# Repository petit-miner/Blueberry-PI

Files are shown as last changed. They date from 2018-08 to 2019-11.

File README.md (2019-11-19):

Blueberry PI

I have designed this PCB, because the sheer power of this SoC, at very low power consumption, combined with its display capabilities, it offers options that makers have never seen before.<br> 
<br>
There are two versions available: the 2 layer and 4 layer version.<br> 
Have a look at the subfolder for the 2 and 4 layer version to check out the specific features.<br>
<br>
<br>
The Blueberry PI:<br>
• SoC Allwinner V3s:<br>
	- ARM Cortex-A7 @ 1.2GHz<br>
	- 64 Megabyte of RAM<br>
•	10 / 100M Ethernet <br>
•	Wifi and Bluetooth (RTL8723BS)  <br>
•	1 USB Host Port / 1 micro USB port <br> 
•	MIPI CSI interface<br>
•	pinheader for an OV2640 and an OV7670 parallel camera<br>
•	parallel RGB interface, compatible with 40pin parallel RGB displays<br>
•	audio jack (3,5mm)<br>
•	onboard microphone<br>
•	a 26pin Raspberry PI compatible header<br>
•	SPI Flash <br>
•	SD card slot<br>

The Blueberry PI can boot from an SD card or SPI Flash. <br>
I'm currently <b> not </B> available for custom projects. <br>
If you have any questions email me at info.blueberrypi@gmail.com <br>

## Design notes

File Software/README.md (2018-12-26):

Software

The mainline linux kernel (4.21) has support for:
- basic SOC features
- Ethernet
- USB 
- parallel CSI 
- RGB and TCON 
- UART
- I²C
- SPI
- SDIO
- Audio
- LRADC0
- RTC
- Watchdog

Whats not implemented:
- CPU frequency scaling
- MIPI CSI 
- Video Engine (encoding / decoding video)

 Have a look at the documentation to find out how to build your own mainline kernel and rootfs.

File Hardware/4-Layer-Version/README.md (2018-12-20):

Hardware

This is the 4 Layer version of the Blueberry PI. It has a richer featureset than the 2 Layer PCB.<br>
Keep in mind that this PCB isn' tested yet, I will keep you updated.<br>
It has the following features:<br>
<br>
• SoC Allwinner V3s:<br>
• ARM Cortex-A7 @ 1.2GHz<br>
• 64 Megabyte of RAM<br>
• Ethernet Jack<br>
• Wifi and Bluetooth (RTL8723BS)<br>
• 1 USB Host Port / 1 micro USB port<br>
• MIPI CSI interface, pin compatible with the Raspberry Pi camera<br>
• pinheader for an OV2640 and an OV7670 parallel camera<br>
• parallel RGB interface, compatible with 40pin parallel RGB displays<br>
• VGA Output<br>
• HDMI Input with the ADV7611 1080p @ 30 fps<br>
• Audio jack (3,5mm)<br>
• onboard microphone<br>
• a 26pin Raspberry PI compatible header<br>
• SPI Flash<br>
• SD card slot <br>
<br>

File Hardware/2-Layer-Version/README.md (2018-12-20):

Hardware

This is the 2 Layer version of the Blueberry PI. It is a more compact version as the 4 layer PCB.<br>
It has the following features:<br>
<br>
• SoC Allwinner V3s:<br>
• ARM Cortex-A7 @ 1.2GHz<br>
• 64 Megabyte of RAM<br>
• Ethernet Jack<br>
• Wifi and Bluetooth (RTL8723BS)<br>
• 1 USB Host Port / 1 micro USB port<br>
• MIPI CSI interface, pin compatible with the Raspberry Pi camera<br>
• pinheader for an OV2640 and an OV7670 parallel camera<br>
• parallel RGB interface, compatible with 40pin parallel RGB displays<br>
• Audio jack (3,5mm)<br>
• onboard microphone<br>
• four costumizeable buttons and one reset buttons<br>
• a 26pin Raspberry PI compatible header<br>
• SPI Flash<br>
• SD card slot <br>

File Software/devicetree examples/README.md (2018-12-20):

Devicetree examples

As you can see there are 3 .dts files and one dtsi file.

The sun8i-v3s.dtsi defines all of the SoC Interfaces.

The sun8i-blueberrypi.dts shows an example for enabling the framebuffer.

The sun8i-blueberrypi-csi-ov2640.dts shows an example for the OV2640 parallel camera.

The sun8i-blueberrypi-csi-ov7670.dts shows an example for the OV7670 parallel camera.

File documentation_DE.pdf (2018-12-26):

## Inhaltsverzeichnis

S e i t e | 1

S e i t e | 2

## Buildroot

Für Buildroot werden folgende Pakte benötigt:

which sed make binutils build-essentials gcc g++ bash patch gzip bzip2 perl tar cpio python unzip rsync file bc wget ncurses5

Als erstes muss Buildroot heruntergeladen werden:

https://buildroot.org/downloads/

Wählt dazu den aktuellsten Tarball aus. Entpackt den Tarball in euer Workspace und betretet das neue Verzeichnis buildroot. Anschließend muss das Unterverzeichnis configs betreten werden.

In diesem Unterverzeichnis ladet ihr die vorgefertigte config Datei für den Blueberry PI herunter:

wget https://github.com/petit-miner/Blueberry-PI/raw/master/Software/blueberrypi_defconfig

Verlasst danach das Unterverzeichnis configs und wechselt ins Hauptverzeichnis von Buildroot, nun wird die config Datei angewendet:

make blueberrypi_defconfig

Möchte man nun Buildroot weiter konfigurieren, so muss dieser Befehl verwendet werden:

make menuconfig

Der Buildprozess lässt sich mit

make

starten. Dabei ist zu beachten, dass der Parameter -j nicht verwendet werden darf, da Buildroot kein paralleles Arbeiten unterstützt!

Nach erfolgreichem erstellen des Buildroots ist der Tarball unter: output/images/rootfs.tar

zu finden.

S e i t e | 3

## Imagepacker

Im Imagepacker befindet sich bereits eine kompilierte Version von u-boot und des Linux Kernels (4.21.rc-1). Somit kann, wenn gewünscht, der Buildprozess von u-boot und dem Linux Kernel übersprungen werden. Das Buildroot muss aufgrund seiner Größe allerdings noch selbst erstellt werden.

Möchte man ein LCD verwenden müssen diese Dateien in das /boot Verzeichnis kopiert werden:

boot-lcd.scr

sun8i-v3s-blueberrypi.dtb

Möchte man den VGA Ausgang benutzen müssen folgende Dateien in das /boot Verzeichnis kopiert werden:

boot-vga.scr

sun8i-v3s-blueberrypi.dtb

Möchte man keine Videoausgabe oder möchte eine parallele Kamera anschließen sind folgende Dateien zu kopieren:

boot.scr

sun8i-v3s-blueberrypi-csi-ov7670.dtb oder sun8i-v3s-blueberrypi-csi-ov2640.dtb

(Anschließend muss die Devicetree Datei noch in sun8i-v3s-blueberrypi.dtb umbenannt werden!)

Nachdem die korrekten Bootdateien kopiert worden sind, muss das zuvor erstellte tarball Buildroot in den Ordner rootfs entpackt werden. Wichtig ist dabei, dass dieses als Root geschieht, da sonst die Dateirechte verloren gehen.

mkdir rootfs

sudo tar xvf rootfs/rootfs.tar

rm rootfs/rootfs.tar

Als letzter Schritt wird nun das flashbare Image erstellt, dies geschieht so:

sudo chmod +x imagepacker.sh

sudo ./imagepacker.sh boot/ rootfs/

Nach erfolgreichem Erstellen des Images ist dieses als .dd Datei zu finden.

S e i t e | 4

## u-boot

Als erstes muss der Sourcecode für u-boot von Github geklont werden:

git clone https://github.com/petit-miner/u-boot.git -b v3s-current

Betrete anschließend das neue Verzeichnis u-boot und wende die Konfigurationsdatei an:

make ARCH=arm CROSS_COMPILE=arm-linux-gnueabihf- BlueberryPI-vga_defconfig

Möchte man nun u-boot weiter konfigurieren, so muss dieser Befehl verwendet werden:

make ARCH=arm CROSS_COMPILE=arm-linux-gnueabihf- menuconfig

Der Buildprozess lässt sich mit

make

starten.

Nach erfolgreichem Erstellen von u-boot ist dieses als u-boot-sunxi-with-spl.bin zu finden.

## Linux Kernel

Als erstes muss der Sourcecode für den Linux Kernel von Github geklont werden:

git clone https://github.com/torvalds/linux.git

Betrete anschließend das neue Verzeichnis linux und wende folgende Konfigurationsdatei an:

make ARCH=arm CROSS_COMPILE=arm-linux-gnueabihf- sunxi_defconfig

Zu beachten ist, dass es sich hierbei um eine minimal Konfiguration handelt und somit viele Treiber für z.B. USB Geräte fehlen. Zudem fehlt der DVP Kamera Treiber, dieser ist unter device driver -> Multimedia -> Platform zu finden. Diese können durch menuconfig ausgewählt werden.

make ARCH=arm CROSS_COMPILE=arm-linux-gnueabihf- menuconfig

Der Buildprozess lässt sich mit

make ARCH=arm CROSS_COMPILE=arm-linux-gnueabihf-

starten.

Nach erfolgreichem Erstellen vom Linux Kernel ist dieser als arch/arm/boot/zImage zu finden.

S e i t e | 5

## USB OTG (Universal Serial Bus, On the Go)

Der Allwinner V3s verfügt über einen USB OTG Port. Das USB Interface ist nicht multiplexbar.

Port | Pin
USB-DM | 110
USB-DP | 111

Im Linux Kernel ist der Treiber für das USB Interface als sun4i-usb-phy und sun4i-a10-musb zu finden.

### Konfiguration im Devicetree

Bei der Verwendung der Standard Devicetree Datei sun8i-v3s.dtsi ist im folgenden Beispiel erklärt wie der USB Controller aktiviert wird: Die vollständige Devicetreedatei kann auf Github heruntergeladen werden. Auszug aus der sun8i-v3s.dtsi:

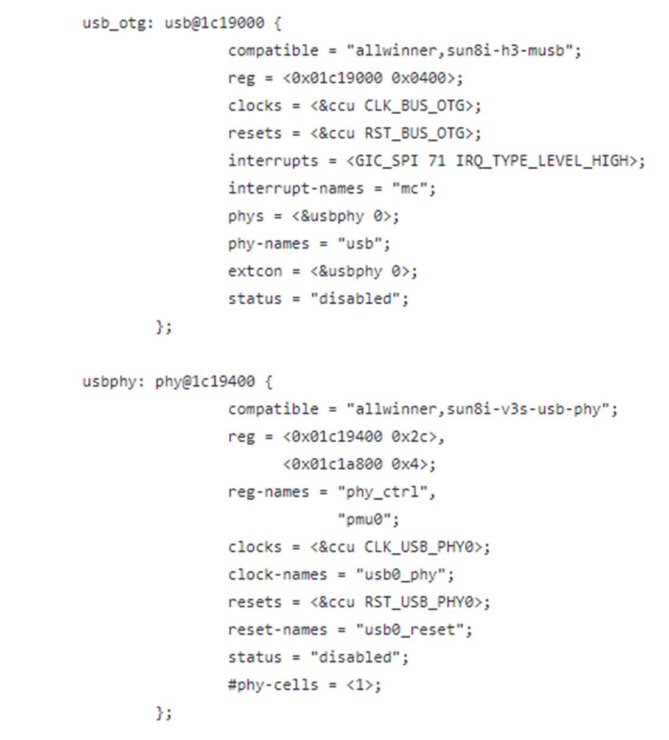
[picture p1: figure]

S e i t e | 6

Dafür muss die Boardfile sun8i-v3s-blueberrypi.dts bearbeitet werden:

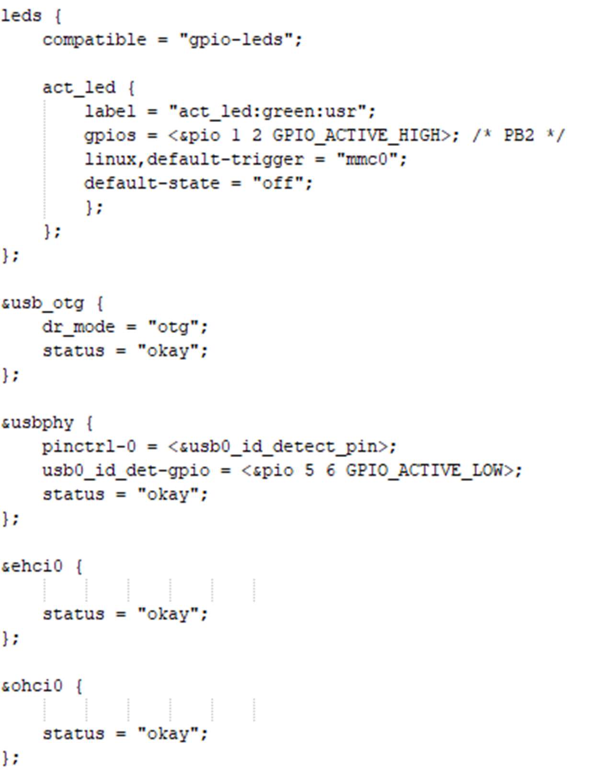
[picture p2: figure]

Der EHCI und OHCI Controller werden benötigt um USB 1.0 und USB 2.0 Geräte zu unterstützen. Werden die beiden Controller nicht im Devicetree aktiviert, entsteht kein Host Verhalten des V3s SoC. Momentan ist es nicht möglich USB 3.0 Geräte an den V3s anzuschließen, da dies eine Kernel Panic hervorruft.

### USB Device

Der V3s SoC verfügt über einen USB OTG Port, d.h. dass er als USB Device oder Host konfiguriert werden kann. Beim Blueberry PI befindet sich der USB_ID Pin an PF6. Dank der Treiberunterstützung im Linux Kernel kann der V3s als virtuelle USB zu Ethernet Karte und auch als USB zu UART Konverter fungieren. Dank des offenen USB Stacks lassen sich auch eigene USB Devices programmieren.

S e i t e | 7

### FEL-Mode

Über USB ist es möglich ein angeschlossenes SPI Flash zu beschreiben. Dazu muss die SD Karte aus dem Halter entfernt werden. Die weiteren Schritte zum Beschreiben sind auf Sunxi unter FEL/USBBoot zu finden.

## Ethernet

Der Allwinner V3s verfügt über einen Ethernet Port. Das Ethernet Interface ist nicht multiplexbar.

Port | Pin
EPHY_RXN | 89
EPHY_RXP | 90
EPHY_TXN | 91
EPHY_TXP | 91
EPHY_LINK_LED | 77
EPHY_SPD_LED | 78

Im Linux Kernel ist der Treiber für das Ethernet Interface als dwmac-sun8i zu finden.

### Konfiguration im Devicetree

Bei der Verwendung der Standard Devicetree Datei sun8i-v3s.dtsi ist im folgenden Beispiel erklärt wie das Ethernet Interface aktiviert wird. Dafür muss die Boardfile sun8i-v3s-blueberrypi.dts bearbeitet werden:

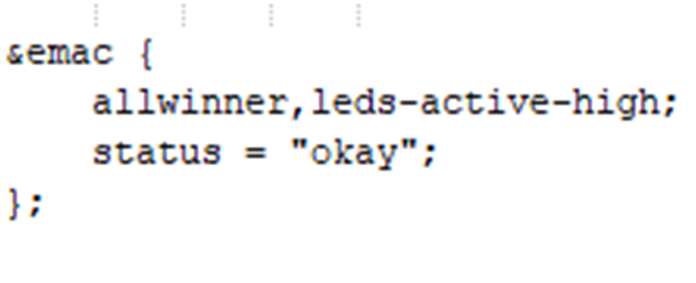
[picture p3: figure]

S e i t e | 8

### Einstellen einer festen MAC Adresse

Bei jedem Start / Reboot erhält der Ethernet PHY eine neue MAC Adresse vom Treiber, um dies zu unterbinden muss folgendes in die /etc/network/interfaces eingetragen werden:

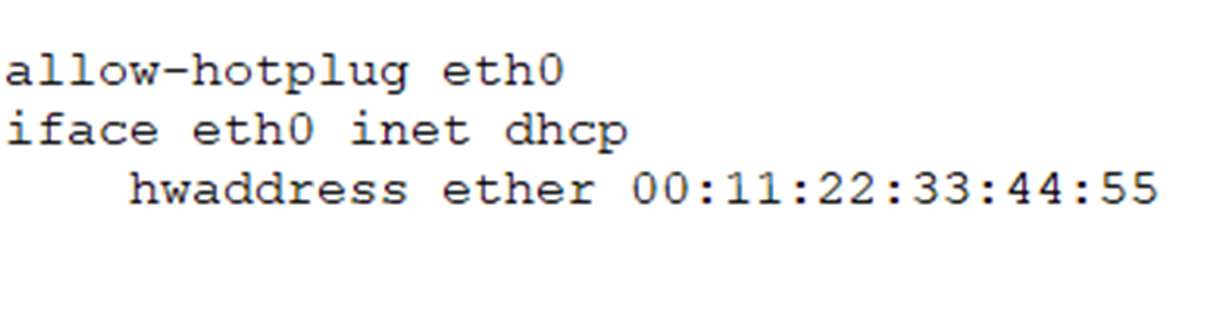
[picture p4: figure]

## Parallel RGB LCD interface

Der Allwinner V3s verfügt über eine parallele RGB LCD Schnittstelle, welche direkt LCDs ansteuern kann. Es können so gut wie alle 40 Pin parallelen RGB LCDs verwendet werden, zum Beispiel:

AT050TN33 (480x320)

HW800480F-3E-0B-10 (800x480)

Das parallele RGB interface ist nicht multiplexbar und besitzt folgendes Pinmapping:

Port | Pin
CSI_PCLK | PE0
CSI_MCLK | PE1
CSI_HSYNC | PE2
CSI_VSYNC | PE3
LCD_D2 | PE4
LCD_D3 | PE5
LCD_D4 | PE6
LCD_D5 | PE7
LCD_D6 | PE8
LCD_D7 | PE9
LCD_D10 | PE10
LCD_D11 | PE11
LCD_D12 | PE12
LCD_D13 | PE13
LCD_D14 | PE14
LCD_D15 | PE15
LCD_D18 | PE16
LCD_D19 | PE17
LCD_D20 | PE18
LCD_D21 | PE19
LCD_D22 | PE23
LCD_D23 | PE24

S e i t e | 9

### Konfiguration in u-boot:

Das Displaytiming wird bereits in u-boot konfiguriert um schon beim Booten eine Displayausgabe zu erhalten. Beim Starten des Linux Kernels übergibt u-boot jegliche Informationen über das Displaytiming sowie die Speicheradresse des zuvor initialisierten Framebuffers an den Linux Kernel. Somit ist es theoretisch nicht nötig die Displayhardware im Devicetree zu konfigurieren.

Es muss lediglich ein Framebuffer für u-boot angegeben werden, Auszug aus der

sun8i-v3s-blueberrypi.dts:

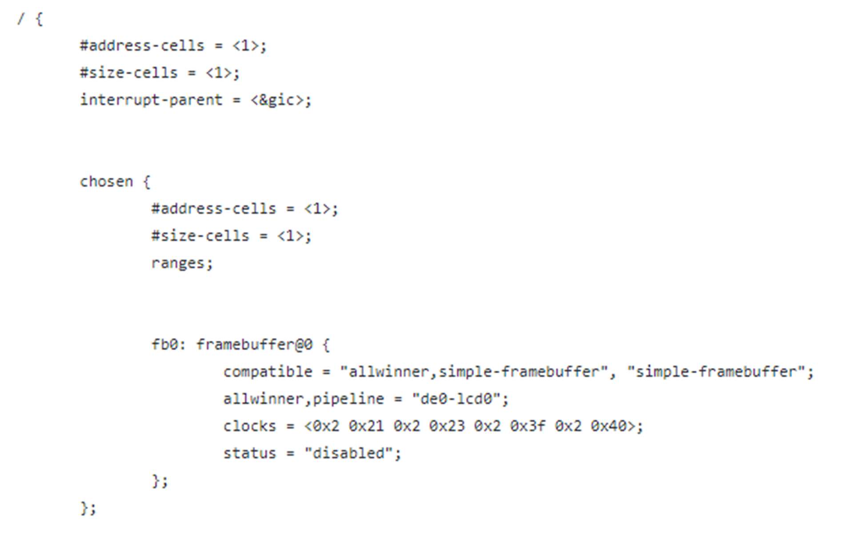
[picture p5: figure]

Momentan wird der simple Framebuffer lediglich in meinem u-boot Repository unterstützt.

Um u-boot mit Unterstützung des parallelen RGB Interfaces zu bauen, siehe u-boot. Dort sind auch die benötigten Displaytimings für die beiden oben genannten Displays angegeben sowie für den RGB zu VGA Konverter.

S e i t e | 10

## Parallel CSI

Der Allwinner V3s verfügt über einen parallelen CSI Port. Das Interface ist nicht multiplexbar.

Port | PIN | OV7670 | OV2640 | ADV7611
CSI_PCLK | PE0 | PLCK | PCLK | LLC
CSI_MCLK | PE1 | XCLK | XCLK | X
CSI_HSYNC | PE2 | HREF | HREF | X**
CSI_VSYNC | PE3 | VSYNC | VSYNC | X**
CSI_D0 | PE4 | X | X | P8
CSI_D1 | PE5 | X | X | P9
CSI_D2 | PE6 | X | D0 | P10
CSI_D3 | PE7 | X | D1 | P11
CSI_D4 | PE8 | D0 | D2 | P12
CSI_D5 | PE9 | D1 | D3 | P13
CSI_D6 | PE10 | D2 | D4 | P14
CSI_D7 | PE11 | D3 | D5 | P15
CSI_D8 | PE12 | D4 | D6 | P0
CSI_D9 | PE13 | D5 | D7 | P1
CSI_D10 | PE14 | D6 | D8 | P2
CSI_D11 | PE15 | D7 | D9 | P3
CSI_D12 | PE16 | X | X | P4
CSI_D13 | PE17 | X | X | P5
CSI_D14 | PE18 | X | X | P6
CSI_D15 | PE19 | X | X | P7
CSI_SCK / I2C1* | PE21 | SIOC | SIOC | SCL
CSI_SDA / I2C1* | PE22 | SIOD | SIOD | SDA

*zu beachten ist, dass lediglich I2C1 bzw. CSI_I2C für die Ansteuerung der Kamera verwendet werden kann.

** HSync und VSync Signale werden nicht benötigt, da BT.656 mit embedded Sync verwendet wird.

### Konfiguration im Devicetree

Bei der Verwendung der Standard Devicetree Datei sun8i-v3s.dtsi ist im folgenden Beispiel erklärt wie der parallele CSI Port aktiviert wird: Die vollständige Devicetreedatei kann auf Github heruntergeladen werden. Auszug aus der sun8i-v3s.dtsi:

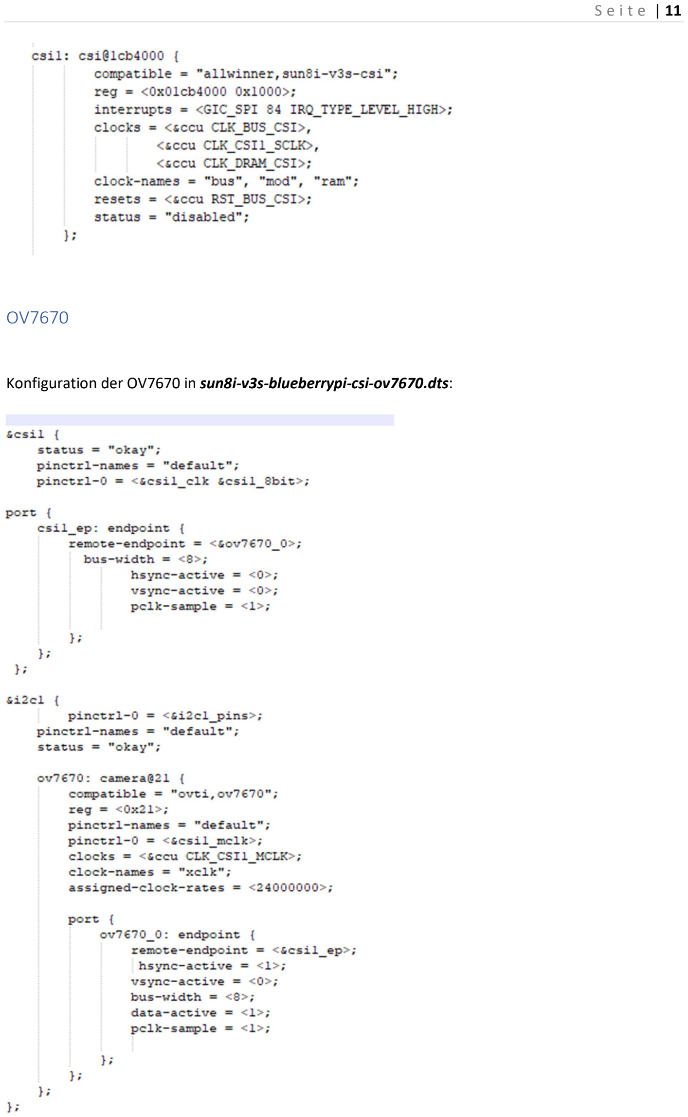
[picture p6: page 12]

S e i t e | 11

OV7670

Konfiguration der OV7670 in sun8i-v3s-blueberrypi-csi-ov7670.dts:

S e i t e | 12

Unter &csi wird das Interface aktiviert und die dazu gehörigen Pins über &csi1_clk und &csi1_8bit dem Interface zugewiesen. Dies geschieht im &pio (Pincontroller):

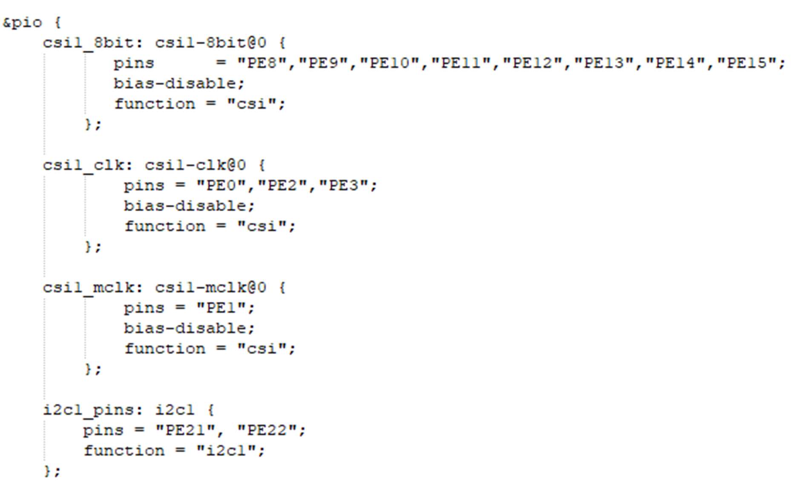
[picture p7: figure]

Anschließend wird im endpoint die verwendete Kamera näher definiert, wie z.B. die Hsync, Vsync und die PCLK Eigenschaften.

Unter &i2c1 werden die benutzen Pins zugewiesen und das I2C1 Interface aktiviert, innerhalb des &i2c1 wird die Kamera konfiguriert. Mit reg = <0x21>; wird die I2C Adresse der Kamera angegeben.

Danach wird die MCLK, die den Arbeitstakt für die Kamera bereitstellt, konfiguriert. Hierzu wird der verwendete Pin angegeben, siehe &pio, sowie die Frequenz in Hz.

Im endpoint von &i2c1 werden wieder die Eigenschaften von Hsync, Vsync und der PCLK definiert.

Zu beachten ist, dass die beiden Endpoints unter &csi und &i2c1 aufeinander verweisen, siehe remote-endpoint = <>;

S e i t e | 13

OV2640

Konfiguration der OV2640 in sun8i-v3s-blueberrypi-csi-ov2640.dts:

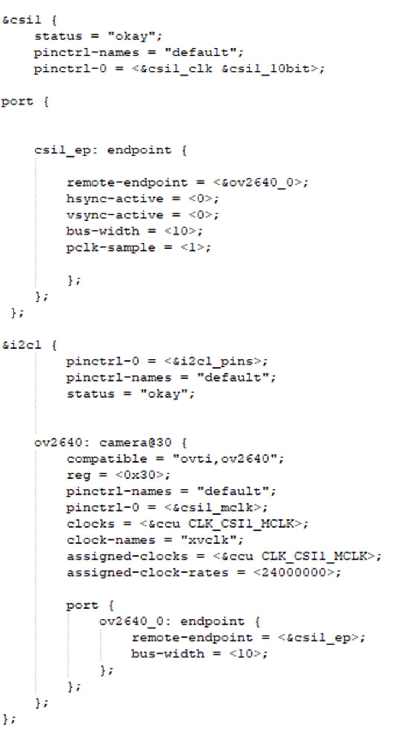
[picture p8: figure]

S e i t e | 14

Unter &csi wird das Interface aktiviert und die dazu gehörigen Pins über &csi1_clk und &csi1_10bit dem Interface zugewiesen. Dies geschieht im &pio (Pincontroller):

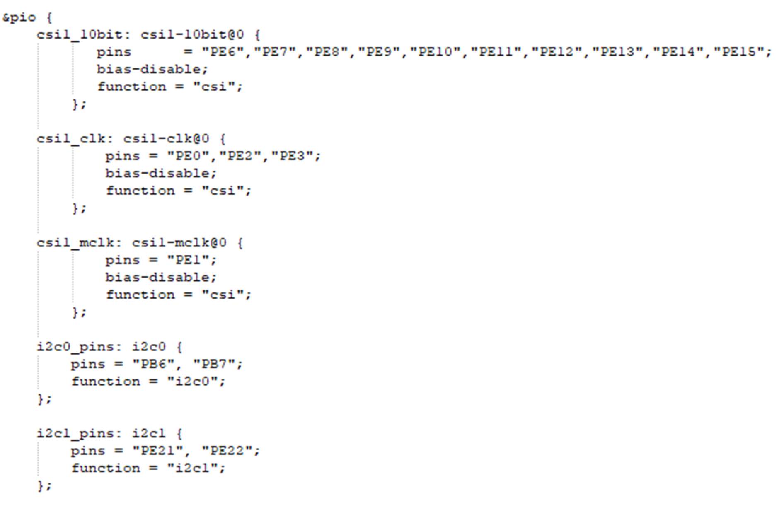
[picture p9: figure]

### ADV7611

WIP

### Verwendung der Kamera unter Linux

Mit dem Befehl: dmesg | grep ov kann überprüft werden ob die Kamera erkannt worden ist. Sollte
die Kamera nicht erkannt worden sein, könnte dies an der fehlenden MCLK liegen.

Wurde die Kamera erkannt, kann nun mit fswebcam ein Bild aufgenommen werden:

fswebcam -S 20 -d /dev/video0 -p YUYV -r 640x480 YUYV.jpg

Mit ffmpeg ist es möglich Videos aufzuzeichnen:

ffmpeg -f v4l2 -framerate 25 -video_size 640x480 -i /dev/video0 output.mp4

S e i t e | 15

## SPI (Serial Peripheral Interface)

Der Allwinner V3s verfügt über ein Serial Peripheral Interface. Beim SPI ist es nicht möglich die Pins zu multiplexen.

Port | Pin
SPI0_MISO | PC0
SPI0_CLK | PC1
SPI0_CS | PC2
SPI0_MOSI | PC3

Im Linux Kernel ist der Treiber für das SPI als sun8i-h3-spi zu finden.

### Konfiguration im Devicetree

Bei der Verwendung der Standard Devicetree Datei sun8i-v3s.dtsi ist im folgenden Beispiel erklärt wie das SPI aktiviert wird. Die vollständige Devicetreedatei kann auf Github heruntergeladen werden. Dafür muss die Boardfile sun8i-v3s-blueberrypi.dts bearbeitet werden:

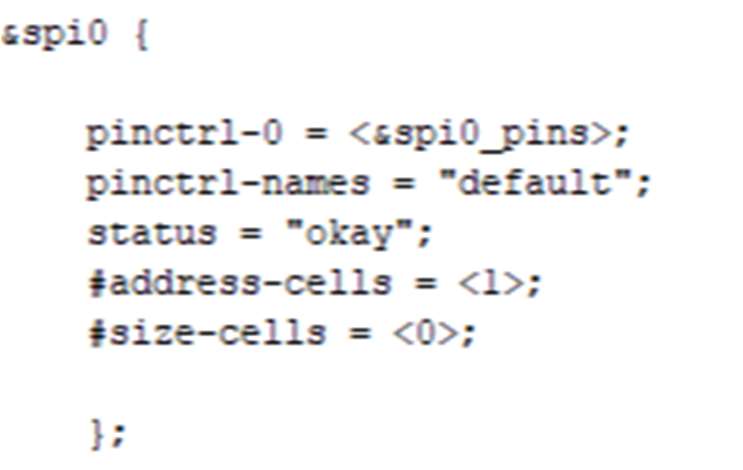
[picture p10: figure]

Als erstes wird das SPI mit den spi0_pins initialisiert. Die zwei Zeilen: #adress-cells = <1>; und

#size-cells = <0>; sind Helfer welche den DMA Support auf dem SPI ermöglichen.

Auffällig ist, dass in der sun8i-v3s-blueberrypi.dts keine Pinzuweisung stattfindet. Die Pinzuweisung findet in der sun8i-v3s.dtsi statt, da das SPI nicht multiplexbar ist und somit nur eine korrekte Pinzuweisung existiert.

Möchte man nun weitere Geräte an das SPI anschließen, so kann auf das große Treiberspektrum des Linux Kernels zurückgegriffen werden. Es kann z.B: der MCP2515 (CAN-Controller), ENC28J60 (Ethernet Interface), SPI Displays oder auch zahllose Sensoren und Aktoren angeschlossen werden.

Weitere Beispiele mit Sensoren / Aktoren im Devicetree folgen noch!

S e i t e | 16

## I²C

Der Allwinner V3s verfügt über zwei I²C (TWI) Busse:

Port | Multiplex Option 1 | Multiplex Option 2
TWI0-SDA | PB7
TWI0-SCK | PB6
TWI1-SDA | PB9 | PE22
TWI1-SCK | PB8 | PE21

I2C1 wird standardmäßig für die Ansteuerung einer seriellen oder parallelen Kamera verwendet.

Bei dem verwendetem I2C Controller handelt es sich um einen Marvell mv64xxx I2C.

Im Linux Kernel ist dieser als CONFIG_I2C_MV64XXX zu finden.

### Konfiguration im Devicetree

Bei der Verwendung der Standard Devicetree Datei sun8i-v3s.dtsi ist im folgenden Beispiel erklärt wie der I1C0 Bus aktiviert wird. Die vollständige Devicetreedatei kann auf Github heruntergeladen werden. Dafür muss die Boardfile sun8i-v3s-blueberrypi.dts bearbeitet werden:

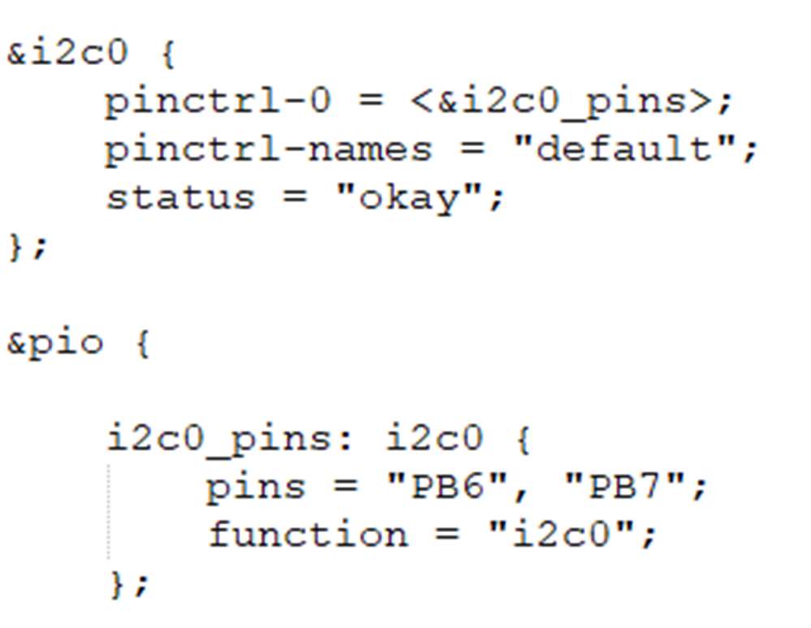
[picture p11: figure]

Als erstes wird der I2C0 Bus mit den i2c0_pins initialisiert. Die Pinzuweisung findet im PIO (Pincontroller) darunter statt. Zuerst wird die SCK des Busses und anschließend SDA als Pin angegeben.

Möchte man zusätzlich den zweiten I2C Bus aktivieren, so muss der Busname von i2c0 auf i2c1 geändert werden. Dies ist auch im Pincontroller zu tun.

S e i t e | 17

Möchte man nun Sensoren oder Aktoren an den I2C Bus anschließen, so kann auf das große Treiberspektrum des Linux Kernels zurückgegriffen werden. Sollte ein Sensor noch nicht unterstützt sein, kann auch auf externe Python oder C Programme zurückgegriffen werden, welche auf die I2C Schnittstelle unter /dev/i2c-0 zugreifen.

Weitere Beispiele mit Sensoren / Aktoren im Devicetree folgen noch!

## UART

Der Allwinner V3s verfügt über drei UART Busse:

Port | Multiplex Option 1 | Multiplex Option 2
UART0-TXD | PB8* | PF2*
UART0-RXD | PB9* | PF4*
UART1-TXD | PE21 | -
UART1-RXD | PE22 | -
UART1-RTS | PE23 | -
UART1-CTS | PE24 | -
UART2-TXD | PB0 | -
UART2-RXD | PB1 | -
UART2-RTS | PB2 | -
UART2-CTS | PB3 | -

*(Pinkonflikt mit SDC0! Kann nur verwendet werden, wenn über das SPI-Flash gebootet wird.)

*(Serielle Standardausgabe von Linux und u-boot, Baud: 115200)

### Konfiguration im Devicetree

Bei der Verwendung der Standard Devicetree Datei sun8i-v3s.dtsi ist im folgenden Beispiel erklärt wie der UART0 Bus aktiviert wird. Die vollständige Devicetreedatei kann auf Github heruntergeladen werden. Dafür muss die Boardfile sun8i-v3s-blueberrypi.dts bearbeitet werden:

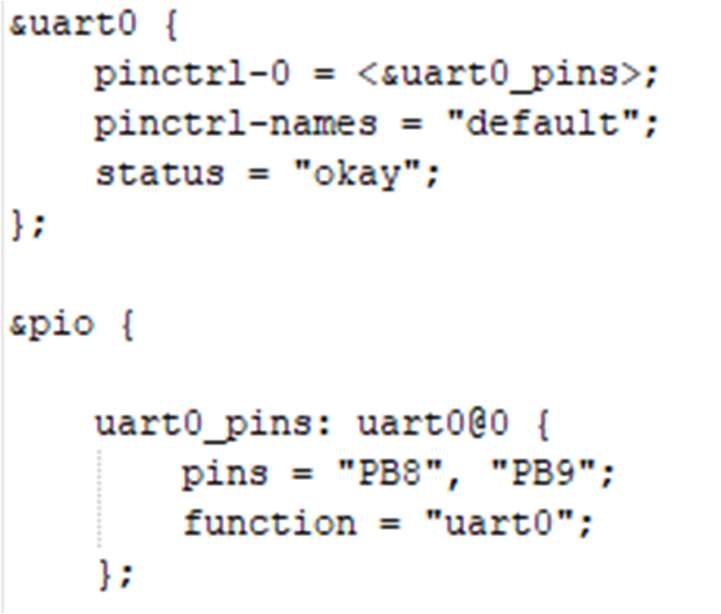
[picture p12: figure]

S e i t e | 18

Als erstes wird der UART0 Bus mit den uart0_pins initialisiert. Die Pinzuweisung findet im PIO (Pincontroller) darunter statt. Zuerst wird der TXD Pin des Busses und anschließend RXD als Pin angegeben.

Möchte man zusätzlich den zweiten oder dritten UART Bus aktivieren, so muss der Busname von UART0 auf UART1 geändert werden. Dies ist auch im Pincontroller zu tun.

## Audio Codec

Der Allwinner V3s verfügt über einen Audio Codec, dieser besteht aus einem Stereo DAC für die Wiedergabe und einem Stereo ADC zum Aufzeichnen von Audio.

Port | Pin
MICIN1P | 113
MICIN1N | 114
AVCC | 115
AGND | 116
VRA1 | 117
VRA2 | 118
HBIAS | 119
HPOUTR | 120
HPOUTL | 121
HPVCCIN | 122
HPVCCBP | 123
HPCOMFB | 124
HPCOM | 125

Im Linux Kernel ist der Treiber für den Audiocodec als sun8i-codec zu finden.

### Konfiguration im Devicetree

Bei der Verwendung der Standard Devicetree Datei sun8i-v3s.dtsi ist im folgenden Beispiel erklärt wie der Audio Codec aktiviert wird. Die vollständige Devicetreedatei kann auf Github heruntergeladen werden. Dafür muss die Boardfile sun8i-v3s-blueberrypi.dts bearbeitet werden:

S e i t e | 19

Als erstes wird beim Audio Routing die Audio Senke und danach die Audio Quelle angegeben.

Senke <- Quelle

Headphone <- HP

Headphone <- HPCOM

MIC1 <- Mic

Mic <- HBIAS

### Verwendung des Audiocodecs unter Linux

Wiedergabe:

Zuerst über amixer / alsamixer die Laustärke der Headphones erhöhen:

amixer -c 0 sset 'Headphone',0 100% unmute

Oder wahlweise über die GUI mit:

amixer

aplay test.mp3

Aufnahme mit dem Mikrofon:

amixer -c 0 cset numid=12 2 // Mikrofon aktivieren

arecord -D hw:0,0 -d 3 -f S16_LE -r 16000 tmp.wav

## LRADC0

Der Allwinner V3s verfügt über einen Low resolution ADC. Dieser wird dazu verwendet um 4 Taster auszulesen. Hinter jedem Taster ist ein Widerstand verschaltet, welcher wenn er gedrückt wird einen Spannungsteiler formt. Der ADC liest die abfallende Spannung am Spannungsteiler und bestimmt somit welcher Taster gedrückt worden ist.

Port | Pin
LRADC0 | 112

Im Linux Kernel ist dieser als sun4i-a10-lradc-keys zu finden.

S e i t e | 20

### Konfiguration im Devicetree

Bei der Verwendung der Standard Devicetree Datei sun8i-v3s.dtsi ist im folgenden Beispiel erklärt wie der LRADC0 aktiviert wird. Die vollständige Devicetreedatei kann auf Github heruntergeladen werden. Dafür muss die Boardfile sun8i-v3s-blueberrypi.dts bearbeitet werden:

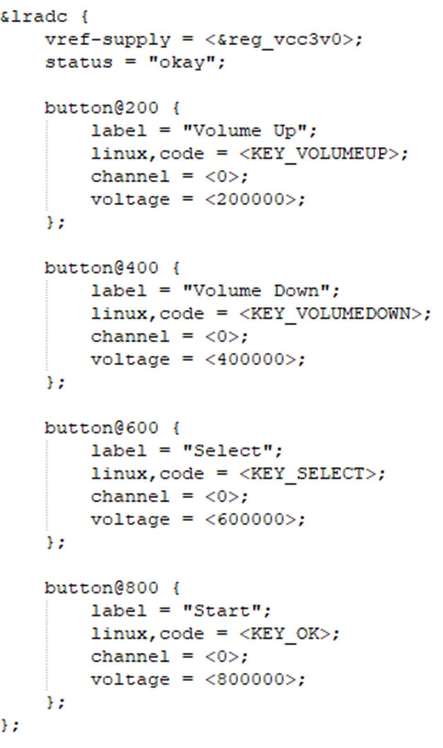
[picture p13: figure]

Zuerst wird die Speisespannung des LRADC0 mit vref-supply = <>; festgelegt. Im Fall des Blueberry PIs sind dies 3V. Anschließend werden die vier Taster wie folgt definiert:

label = “ “; Beschreibung des Tasters

linux,code = <>; Angabe des numerischen Keycodes

voltage = <>; Spannung des Spannungsteiler wenn der Taster gedrückt ist

S e i t e | 21

## Onewire Bus

Da der Allwinner V3s über kein natives Onewire Interface verfügt, muss dies über einen GPIO Port gebitbangt werden.

### Konfiguration im Devicetree

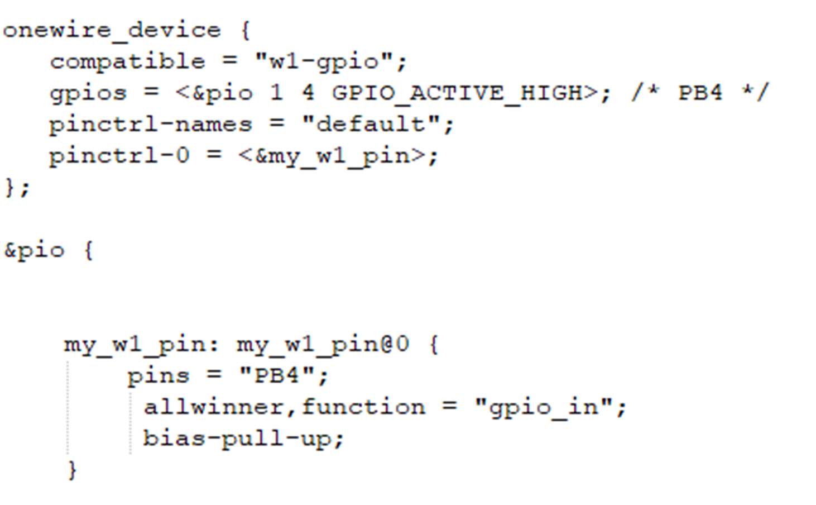
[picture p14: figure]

Zuerst wird unter der Angabe des zu verwendenden Treibers und dem benutzten GPIO Pin der Onewirebus konfiguriert. Im Pincontroller &pio muss der verwendete Pin für den Onewirebus noch zusätzlich definiert werden. Dieser ist als GPIO-In und mit einem Pull-Up zu konfigurieren.

Nun sollte unter /sys/bus/w1/devices/ alle angeschlossenen Onewiredevices sichtbar sein.

Um Sensoren auszulesen, können die einschlägigen Tutorials für andere Single Board Computer verwendet werden.

S e i t e | 22

## Troubleshooting Guide

Dieses Kapitel hilft dir dabei, wenn du den Blueberry Pi selbst in Betrieb nehmen willst.

Sollte dieser nicht booten, folge dieser Schritt für Schritt Anleitung um den Fehler zu finden.

- Im angeschalteten Zustand, ohne Boot Medium, verbraucht der SoC ungefähr 90mA @ 5V. (Versorgung durch DC Step down Module)
Sollte dies der Fall sein liegt höchstwahrscheinlich ein Softwareproblem vor. Versuche den V3s mit dem fertigen Image von Github zu booten. Sollte dies nicht funktionieren teste auch andere SD Karten.

Sollte der SoC wesentlich weniger verbrauchen folge diesen Schritten:

- Ist der V3s SoC korrekt auf der Platine platziert? Der kleine Kreis auf dem SoC markiert Pin 1.
- Alle Lötstellen überprüfen, sind alle Pins des SoC korrekt ausgerichtet und es existieren keine Lötbrücken?
- Ist das Masse Pad auf der Unterseite des SoC verlötet worden?
- Sind alle passiven Bauteile an der richtigen Stelle?
- Ist VCC – RTC und VCC – PE mit 3,3V verbunden? Beim Blueberry Pi geschieht dies mit zwei Jumpern die auf die jeweiligen beschrifteten Pinheader gesetzt werden.
- Sind alle nötigen Spannungen für den SoC vorhanden? (3,3V 3,0V 1,8V 1,2V)
- Oszilliert das 24Mhz Quarz?

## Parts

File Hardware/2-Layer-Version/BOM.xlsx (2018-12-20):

Qty | Value | Parts | Device
RCL
2 | 47k | RN1, RN2 | 4R-NEXB38V
2 | 0R | R4,R26 | R-EU_R0603
3 | 100k | R9, R10, R56 | R-EU_R0603
30 | 100nF | C1, C2, C9, C14, C15, C18, C19, C22, C27, C28, C48, C49, C51, C53, C57, C58, C62, C67, C68, C70, C72,C50, C52, C63, C69,C31, C36, C37, C75, C76 | C-EUC0603
1 | 100pF | C25 | C-EUC0603
1 | 10M | R3 | R-EU_R0603
7 | 10k | R8, R19, R22, R38, R39, R44, R45 | R-EU_R0603
22 | 10µF | C3, C5, C6, C7, C16, C20, C29, C30, C32, C33, C35, C40, C43, C44, C46, C66, C73, C74,C38, C56, C60, C71 | C-EUC0805
1 | 10µH | L2 | L-EUL0805
1 | 11k | R23 | R-EU_R0603
3 | 150k | R7, R54, R58 | R-EU_R0603
7 | 18pF | C8, C10, C11, C12, C41, C42, C45 | C-EUC0603
4 | 1k | R16, R17, R52, R53 | R-EU_R0603
1 | 1nF | C34 | C-EUC0603
11 | 1µF | C13, C17, C21, C39, C47, C55, C64, C65,C54, C59, C61 | C-EUC0603
4 | 2,2µH | L1, L3, L4,L5 | L-EU
2 | 200k | R55,R27 | R-EU_R0603
1 | 22R | R15 | R-EU_R0603
1 | 240 - 1% | R12 | R-EU_R0603
5 | 2k | R25, R28, R30,R13, R14 | R-EU_R0603
4 | 33pF | C4, C23, C24, C26 | C-EUC0603
6 | 47k | R1, R2, R11, R29, R32, R36 | R-EU_R0603
4 | 49.9 | R40, R41, R42, R43 | R-EU_R0603
1 | 5.1 | R47 | R-EU_R0603
1 | 680k | R57 | R-EU_R0603
1 | 6k 1% | R24 | R-EU_R0603
1 | 6k8 | R20 | R-EU_R0603
1 | 8k2 | R21 | R-EU_R0603
IC
1 | EA3036 | U$4 | EA3036
1 | 25F32006WSOI | U1 | SPI_FLASH-X25XXSMD1
1 | NS2009 | U$8 | NS2009
1 | PT4101 | U$9 | PT4101
1 | RTL8723BS | U$2 | RTL8723BS
1 | V3S | U$1 | V3S
1 | XC6204 | U$6 | 2.5V LDO
1 | LM1117 | IC1 | LM1117
Connectors
1 |  | J3 | 40PINFPCH15-1LW
1 | U-FL | ANT2 | ANTENNA-CONN-U-FL(3P)
1 | USB-B-S | X1 | USB-B-S
1 | HR911105A | U$3 | HR911105A
1 | AUDIO_JACK_SMD | J2 | AUDIO_JACK_TRRSSMD_RA
2 |  | JP11, JP12 | PINHD-2X8M
2 |  | JP3, JP5 | PINHD-1X3
1 |  | JP7 | PINHD-1X3M
1 |  | JP2 | PINHD-1X6_2.00
1 |  | JP1 | PINHD-2X13
1 |  | U$5 | MICRO-USB
1 | TRANSFLASH-LOCK | J1 | TRANSFLASH-LOCK
1 | OV2640 | JP10 | PINHD-2X10
1 | OV7670 | JP6 | PINHD-2X9
1 |  | CN2 | DCBARRELPTH
1 |  | J4 | 68611514122
1 | 52745-2290 | X3 | 52745-2290
Misc.
1 | 2A | F1 | PTCFUSE-1206
1 | 32kHz | Q2 | CRYSTALTC38H
1 | 24Mhz | Q1 | CRYSTALHC49U-V
1 |  | MIC | ELECTRET_MICROPHON
2 |  | LED1, LED2 | LEDCHIPLED_0805
5 |  | S1, S2, S3, S4, S5 | MOMENTARY-SWITCH
Semiconductor
1 |  | D1 | DIODE-SOD323-W
1 | AP2305BGN | U$7 | P-CHANNEL-MOSFET

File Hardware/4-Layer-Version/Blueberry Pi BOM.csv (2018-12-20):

Qty | Value | Device | Package | Parts | Description | MF | MPN | OC_FARNELL | OC_NEWARK | PACKAGE | PROD_ID | SF_ID | SPICEPREFIX | SUPPLIER | VALUE
1 |  | 40PINFPCH15-1LW | XF2H-4015-1LW | J3 | OMRON FPC Connector
2 |  | 4R-NEXB38V | EXB38V | RN1, RN2 | Array Chip Resistor |  |  | unknown | unknown
1 |  | 68611514122 | 68611514122 | J4 | WR-FPC 1.00mm SMT ZIF Horizontal Top Contact, 15 Pins=>Code : Con_FPC_ZIF_1.00_68611514122
2 |  | BSS138TA | SOT95P240X110-3N | U5, U6 | N-CHANNEL ENHANCEMENT MODE MOSFET |  | BSS138TA | 1471176 | 61M5072 | SOT-23-3 |  |  |  | Diodes Inc
1 |  | CON-HIROSE_MICRO-USB-SHIELD-ZX62R-B-5P | CON-HIROSE_ZX62R-B-5P | U$15 | Hirose Micro USB Connector
1 |  | DCBARRELPTH | DCJACK_2MM_PTH | CN2 | 2.0mm DC Barrel Jack
1 |  | DIODE-SOD323-W | SOD323-W | D1 | DIODE
1 |  | ELECTRET_MICROPHON-F6035AP | F6035AP | MIC | Electret Condenser Microphone
1 |  | F15HDH | HDF15H | X2 | SUB-D
2 |  | LEDCHIPLED_0805 | CHIPLED_0805 | LED1, LED2 | LED
1 |  | LM1117 | SOT223 | IC1
1 |  | PINHD-1X3 | 1X03 | JP3 | PIN HEADER
1 |  | PINHD-1X3M | 1X03M | JP7 | PIN HEADER
1 |  | PINHD-2X13 | 2X13 | JP1 | PIN HEADER
3 |  | SN74ALVC244PW | SOP65P640X120-20N | U2, U3, U4 | OCTAL BUFFERS/DRIVERS WITH 3-STATE OUTPUTS |  | SN74ALVC244PW | 1470750 | 36K3549 | TSSOP-20 |  |  |  | Texas Instruments
1 | 0 | R-EU_R0603 | R0603 | R26 | RESISTOR, European symbol
3 | 0R | R-EU_R0603 | R0603 | R69, R70, R71 | RESISTOR, European symbol
3 | 1,05k | R-EU_R0603 | R0603 | R18, R46, R55 | RESISTOR, European symbol
2 | 100k | R-EU_R0603 | R0603 | R9, R10 | RESISTOR, European symbol
2 | 100k | R-EU_R0603 | R0603 | R66, R68 | RESISTOR, European symbol |  |  |  |  |  |  |  | R
21 | 100nF | C-EUC0603 | C0603 | C1, C2, C9, C14, C15, C18, C22, C27, C28, C32, C33, C35, C48, C49, C51, C53, C57, C58, C62, C67, C70 | CAPACITOR, European symbol
4 | 100nF | C-EUC0603 | C0603 | C77, C79, C81, C83 | CAPACITOR, European symbol |  |  |  |  |  |  |  | C
3 | 100nF | C-EUC0805 | C0805 | C52, C63, C69 | CAPACITOR, European symbol
5 | 100nf | C-EUC0603 | C0603 | C31, C36, C37, C75, C76 | CAPACITOR, European symbol
1 | 100pF | C-EUC0603 | C0603 | C25 | CAPACITOR, European symbol
1 | 10M | R-EU_R0603 | R0603 | R3 | RESISTOR, European symbol
6 | 10k | R-EU_R0603 | R0603 | R8, R19, R38, R39, R44, R45 | RESISTOR, European symbol
2 | 10k | R-EU_R0603 | R0603 | R63, R64 | RESISTOR, European symbol |  |  |  |  |  |  |  | R
4 | 10µF | C-EUC0603 | C0603 | C38, C56, C60, C71 | CAPACITOR, European symbol
13 | 10µF | C-EUC0805 | C0805 | C3, C5, C6, C7, C16, C20, C29, C30, C50, C59, C66, C73, C74 | CAPACITOR, European symbol
8 | 10µF | C-EUC0805 | C0805 | C43, C44, C45, C46, C78, C80, C82, C84 | CAPACITOR, European symbol |  |  |  |  |  |  |  | C
1 | 10µH | L-EUL0805 | L0805 | L2 | INDUCTOR, European symbol
3 | 17,8k | R-EU_R0603 | R0603 | R4, R33, R49 | RESISTOR, European symbol
4 | 18pF | C-EUC0603 | C0603 | C8, C10, C11, C12 | CAPACITOR, European symbol
4 | 1k | R-EU_R0603 | R0603 | R16, R17, R52, R53 | RESISTOR, European symbol
1 | 1k | R-EU_R0603 | R0603 | R60 | RESISTOR, European symbol |  |  |  |  |  |  |  | R
1 | 1nF | C-EUC0603 | C0603 | C34 | CAPACITOR, European symbol
8 | 1µF | C-EUC0603 | C0603 | C13, C17, C21, C39, C47, C55, C64, C65 | CAPACITOR, European symbol
2 | 1µF | C-EUC0805 | C0805 | C54, C61 | CAPACITOR, European symbol
3 | 2,2k | R-EU_R0603 | R0603 | R7, R37, R54 | RESISTOR, European symbol
1 | 2,2µH | L-EU | ODD-INDUCTOR | L1 | INDUCTOR, European symbol
1 | 200k 1% | R-EU_R0603 | R0603 | R27 | RESISTOR, European symbol
1 | 22 | R-EU_R0603 | R0603 | R15 | RESISTOR, European symbol
1 | 240 - 1% | R-EU_R0603 | R0603 | R12 | RESISTOR, European symbol
1 | 24Mhz | CRYSTALHC49U-V | HC49U-V | Q1 | CRYSTAL |  |  | 1666969 | unknown
1 | 25F32006WSOI | SPI_FLASH-X25XXSMD1 | SO08-EIAJ | U1 | 32M Serial Flash Memory |  |  |  |  |  | IC-09109 |  |  |  | 25F32006WSOI
1 | 28.6363 | CRYSTALHC49S | HC49/S | Q3 | CRYSTAL |  |  | 1667008 | unknown
1 | 2A | PTCFUSE-1206 | R1206 | F1 | PTC fuses, resettable thermistors
2 | 2K2 | R-EU_R0603 | R0603 | R57, R58 | RESISTOR, European symbol
3 | 2k | R-EU_R0603 | R0603 | R25, R28, R30 | RESISTOR, European symbol
2 | 2k - 1% | R-EU_R0603 | R0603 | R13, R14 | RESISTOR, European symbol
1 | 32kHz | CRYSTALTC38H | TC38H | Q2 | CRYSTAL |  |  | unknown | unknown
4 | 33pF | C-EUC0603 | C0603 | C4, C23, C24, C26 | CAPACITOR, European symbol
1 | 390k | R-EU_R0603 | R0603 | R59 | RESISTOR, European symbol |  |  |  |  |  |  |  | R
4 | 3k3 | R-EU_R0603 | R0603 | R61, R62, R65, R67 | RESISTOR, European symbol |  |  |  |  |  |  |  | R
3 | 4,32k | R-EU_R0603 | R0603 | R6, R35, R51 | RESISTOR, European symbol
1 | 470pF | C-EUC0603 | C0603 | C42 | CAPACITOR, European symbol |  |  |  |  |  |  |  | C
6 | 47k | R-EU_R0603 | R0603 | R1, R2, R11, R29, R32, R36 | RESISTOR, European symbol
2 | 47pF | C-EUC0603 | C0603 | C40, C41 | CAPACITOR, European symbol |  |  |  |  |  |  |  | C
4 | 49.9 | R-EU_R0603 | R0603 | R40, R41, R42, R43 | RESISTOR, European symbol
1 | 5,1 | R-EU_R0603 | R0603 | R47 | RESISTOR, European symbol
3 | 549 | R-EU_R0603 | R0603 | R31, R48, R56 | RESISTOR, European symbol
1 | 6k 1% | R-EU_R0603 | R0603 | R24 | RESISTOR, European symbol
3 | 8,66k | R-EU_R0603 | R0603 | R5, R34, R50 | RESISTOR, European symbol
1 | ADV7611 | ADV7611 | QFP50P1210X1210X120-65T500 | U$5
1 | AP2305BGN | P-CHANNEL-MOSFET | SOT23-3 | U$7 | P-Channel MOSFET Mode Field Effect Transistor
1 | AUDIO_JACK_SMD | AUDIO_JACK_TRRSSMD_RA | AUDIO_JACK_3.5MM_TRRS_SMD_RA | J2 | Audio Jack - 3.5mm TRRS (SMD) |  |  |  |  |  | CONN-10676 | PRT-12639
2 | BSS123 | BSS123 | SOT23 | Q4, Q5 | N-CHANNEL MOS FET
1 | HDMI-A | HDMI-A | HDMI_A | U$12 | Horizonal HDMI type A" jack"
1 | HR911105A | HR911105A | RJ45 | U$3
4 | MOUNT-HOLE3.0 | MOUNT-HOLE3.0 | 3,0 | H1, H2, H3, H4 | MOUNTING HOLE with drill center marker
3 | MP1584-MINI | MP1584-MINI | MINI-DC-BRICK | U$4, U$10, U$11
1 | NS2009 | NS2009 | MSOP10 | U$8
1 | OV2640 | PINHD-2X10 | 2X10 | JP10 | PIN HEADER
1 | OV7670 | PINHD-2X9 | 2X09 | JP6 | PIN HEADER
1 | PT4101 | PT4101 | SOT23-6 | U$9
1 | RT9013-18GB | RT9013 | SOT-23-5 | U$14
1 | RTL8723BS | RTL8723BS | LGA | U$2
1 | TRANSFLASH-LOCK | TRANSFLASH-LOCK | TRANSFLASH-LOCK-SOCK | J1 | TransFlash TF Micro SD Card Socket Adapter
1 | U-FL | ANTENNA-CONN-U-FL(3P) | U-FL3P-SMD-2.6X2.6X1.0MM | ANT2 | 320110048 |  |  |  |  |  |  |  |  |  | U-FL
1 | USB-B-S | USB-B-S | USB-B-SMT | X1 | USB Connectors
1 | V3S | V3S | QFP-128 | U$1
1 | VCC-RTC | PINHD-1X3 | 1X03 | JP5 | PIN HEADER
1 | XC6204 | XC6204XC6204 | SOT25 | U$6
1 | XC6210B332MR-G | XC6210 | SOT-25 | U$13

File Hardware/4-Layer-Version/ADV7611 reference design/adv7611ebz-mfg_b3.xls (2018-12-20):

Manufacturing BOM Report for adv7611ebz_b3.pcb on 30/11/2010 - RoHS Compliant
Name | Part Type | Value | Tolerance | PCB Decal | SMD | Layer Name | Part Description | Manufacturer | Manufacturers P/N | Stock Code | Reel | Position X | Position Y | Orientation
ALSB | JUMPER |  |  | SIP-2P | No | Top | HEADER, 1 ROW 2WAY & JUMPER SOCKET, RED | HARWIN | M20-9990245 & M7566-05 | FEC 1022245 & 150411 |  | 39.75 | 47.75 | 90
AUDIO_OL1 | TESTPOINT-RED |  |  | TESTPOINT | No | Top | TERMINAL, PCB RED | VERO | 20-313137 | FEC 8731144 |  | 41 | 61.5 | 270
AUDIO_OL2 | TESTPOINT-RED |  |  | TESTPOINT | No | Top | TERMINAL, PCB RED | VERO | 20-313137 | FEC 8731144 |  | 38.25 | 61.5 | 270
AUDIO_OL3 | TESTPOINT-RED |  |  | TESTPOINT | No | Top | TERMINAL, PCB RED | VERO | 20-313137 | FEC 8731144 |  | 35.5 | 61.5 | 270
AUDIO_OL4 | TESTPOINT-RED |  |  | TESTPOINT | No | Top | TERMINAL, PCB RED | VERO | 20-313137 | FEC 8731144 |  | 32.75 | 61.5 | 270
AUDIO_OR1 | TESTPOINT-RED |  |  | TESTPOINT | No | Top | TERMINAL, PCB RED | VERO | 20-313137 | FEC 8731144 |  | 41 | 76 | 270
AUDIO_OR2 | TESTPOINT-RED |  |  | TESTPOINT | No | Top | TERMINAL, PCB RED | VERO | 20-313137 | FEC 8731144 |  | 38.25 | 76 | 270
AUDIO_OR3 | TESTPOINT-RED |  |  | TESTPOINT | No | Top | TERMINAL, PCB RED | VERO | 20-313137 | FEC 8731144 |  | 35.5 | 76 | 270
AUDIO_OR4 | TESTPOINT-RED |  |  | TESTPOINT | No | Top | TERMINAL, PCB RED | VERO | 20-313137 | FEC 8731144 |  | 32.75 | 76 | 270
AUD_3V3 | TESTPOINT-RED |  |  | TESTPOINT-POWER | No | Top | TESTPOINT-POWER | Not Inserted | Not Inserted | Not Inserted |  | 101.5 | 107 | 0
AUD_3V3A | TESTPOINT-RED |  |  | TESTPOINT-POWER | No | Top | TESTPOINT-POWER | Not Inserted | Not Inserted | Not Inserted |  | 101.5 | 112.75 | 0
AUD_CH1 | LED_0805_GR |  |  | LED_0805_GR | Yes | Top | LED, SMD GREEN | KINGBRIGHT | KP-2012SGC | FEC 1318243 | Yes | 8.25 | 88.25 | 180
AUD_CH2 | LED_0805_GR |  |  | LED_0805_GR | Yes | Top | LED, SMD GREEN | KINGBRIGHT | KP-2012SGC | FEC 1318243 | Yes | 8.25 | 85.75 | 180
AUD_CH3 | LED_0805_GR |  |  | LED_0805_GR | Yes | Top | LED, SMD GREEN | KINGBRIGHT | KP-2012SGC | FEC 1318243 | Yes | 8.25 | 83.25 | 180
AUD_CH4 | LED_0805_GR |  |  | LED_0805_GR | Yes | Top | LED, SMD GREEN | KINGBRIGHT | KP-2012SGC | FEC 1318243 | Yes | 8.25 | 80.75 | 180
AUD_RESET | TESTPOINT-RED |  |  | TESTPOINT | No | Top | TERMINAL, PCB RED | VERO | 20-313137 | FEC 8731144 |  | 55 | 61 | 0
AVDD1V8 | TESTPOINT-RED |  |  | TESTPOINT-POWER | No | Top | TESTPOINT-POWER | Not Inserted | Not Inserted | Not Inserted |  | 110.25 | 47.75 | 180
C1 | CAP0402_100NF | 0.1uF | (+80 -20%) | CMI0402 | Yes | Top | CAPACITOR, 0402 100NF 16V Y5V | PHYCOMP | CC0402ZRY5V7BB104 | FEC 3019482 | Yes | 10.25 | 144 | 180
C2 | CAP0402_10NF | 10nF | (+80 -20%) | CMI0402 | Yes | Top | CAPACITOR, 0402 10NF 16V Y5V | PHYCOMP | CC0402ZRY5V7BB103 | FEC 3019421 | Yes | 10.25 | 143 | 180
C3 | CAP0402_100NF | 0.1uF | (+80 -20%) | CMI0402 | Yes | Top | CAPACITOR, 0402 100NF 16V Y5V | PHYCOMP | CC0402ZRY5V7BB104 | FEC 3019482 | Yes | 14.5 | 135.5 | 180
C4 | CAP+ | 10uF | ±10% | CAP\TAJ_C | Yes | Top | CAPACITOR, CASE C, 10UF, 16V | KEMET | T491C106K016AT | FEC 1457461 |  | 15.25 | 69 | 270
C5 | 220UF_6.3V_TANT_SMD_N | 220uF | ±20% | CASE_N | Yes | Top | CAP TANTALUM 220UF 6.3V 20% SMD | Nichicon | F930J227MNC | Digikey 493-2345-1-ND |  | 12.5 | 60.5 | 180
C6 | CAPTAJA_4-7UF | 4.7uF | ±10% | RTAJ_A | Yes | Top | CAPACITOR, CASE A 4.7UF 10V TANTALUM | AVX | TAJA475K010R | FEC 498658 |  | 16.25 | 52.75 | 90
C7 | 220UF_6.3V_TANT_SMD_N | 220uF | ±20% | CASE_N | Yes | Top | CAP TANTALUM 220UF 6.3V 20% SMD | Nichicon | F930J227MNC | Digikey 493-2345-1-ND |  | 15.25 | 76.75 | 180
C8 | CAP0402_100NF | 0.1uF | (+80 -20%) | CMI0402 | Yes | Top | CAPACITOR, 0402 100NF 16V Y5V | PHYCOMP | CC0402ZRY5V7BB104 | FEC 3019482 | Yes | 17.75 | 72.5 | 270
C9 | CAP0402_100NF | 0.1uF | (+80 -20%) | CMI0402 | Yes | Top | CAPACITOR, 0402 100NF 16V Y5V | PHYCOMP | CC0402ZRY5V7BB104 | FEC 3019482 | Yes | 17.75 | 69 | 270
C10 | CAP0402_100NF | 0.1uF | (+80 -20%) | CMI0402 | Yes | Top | CAPACITOR, 0402 100NF 16V Y5V | PHYCOMP | CC0402ZRY5V7BB104 | FEC 3019482 | Yes | 19.5 | 140.5 | 0
C11 | CAP0402_100NF | 0.1uF | (+80 -20%) | CMI0402 | Yes | Top | CAPACITOR, 0402 100NF 16V Y5V | PHYCOMP | CC0402ZRY5V7BB104 | FEC 3019482 | Yes | 20.25 | 133.5 | 270
C12 | CAP0402_10NF | 10nF | (+80 -20%) | CMI0402 | Yes | Top | CAPACITOR, 0402 10NF 16V Y5V | PHYCOMP | CC0402ZRY5V7BB103 | FEC 3019421 | Yes | 21.25 | 133.5 | 270
C13 | CAP0402_10NF | 10nF | (+80 -20%) | CMI0402 | Yes | Top | CAPACITOR, 0402 10NF 16V Y5V | PHYCOMP | CC0402ZRY5V7BB103 | FEC 3019421 | Yes | 21.25 | 129.5 | 90
C14 | CAP0402_100NF | 0.1uF | (+80 -20%) | CMI0402 | Yes | Top | CAPACITOR, 0402 100NF 16V Y5V | PHYCOMP | CC0402ZRY5V7BB104 | FEC 3019482 | Yes | 20.25 | 129.5 | 90
C15 | 200PF_50V_NP0_0402 | 200pF | ±5% | CMI0402 | Yes | Top | CAP CER 200PF 50V C0G 0402 | Murata ENA | GRM1555C1H201JA01D | DigiKey 490-3232-1-ND |  | 20 | 63.75 | 0
C16 | 200PF_50V_NP0_0402 | 200pF | ±5% | CMI0402 | Yes | Top | CAP CER 200PF 50V C0G 0402 | Murata ENA | GRM1555C1H201JA01D | DigiKey 490-3232-1-ND |  | 21.25 | 73.5 | 0
C17 | CAP0402_NI | NI | n/a | CMI0402 | Yes | Top | SMD CAPACITOR 0402 | Not Inserted | Not Inserted | Not Inserted |  | 22 | 19.5 | 0
C18 | CAP0402_100NF | 0.1uF | (+80 -20%) | CMI0402 | Yes | Top | CAPACITOR, 0402 100NF 16V Y5V | PHYCOMP | CC0402ZRY5V7BB104 | FEC 3019482 | Yes | 25 | 138.75 | 0
C19 | CAP0402_10NF | 10nF | (+80 -20%) | CMI0402 | Yes | Top | CAPACITOR, 0402 10NF 16V Y5V | PHYCOMP | CC0402ZRY5V7BB103 | FEC 3019421 | Yes | 25 | 137.75 | 0
C20 | CAP0402_10NF | 10nF | (+80 -20%) | CMI0402 | Yes | Top | CAPACITOR, 0402 10NF 16V Y5V | PHYCOMP | CC0402ZRY5V7BB103 | FEC 3019421 | Yes | 24.75 | 126 | 180
C21 | CAP0402_100NF | 0.1uF | (+80 -20%) | CMI0402 | Yes | Top | CAPACITOR, 0402 100NF 16V Y5V | PHYCOMP | CC0402ZRY5V7BB104 | FEC 3019482 | Yes | 24.75 | 125 | 180
C22 | 680PF_50V_NP0_0402 | 680pF | ±5% | CMI0402 | Yes | Top | CAP CER 680PF 50V C0G 0402 | Murata ENA | GRM1555C1H681JA01D | Digikey 490-3240-1-ND |  | 26.75 | 74 | 90
C23 | 680PF_50V_NP0_0402 | 680pF | ±5% | CMI0402 | Yes | Top | CAP CER 680PF 50V C0G 0402 | Murata ENA | GRM1555C1H681JA01D | Digikey 490-3240-1-ND |  | 26.75 | 63.5 | 270
C24 | CAP0402_100NF | 0.1uF | (+80 -20%) | CMI0402 | Yes | Top | CAPACITOR, 0402 100NF 16V Y5V | PHYCOMP | CC0402ZRY5V7BB104 | FEC 3019482 | Yes | 27.75 | 138.75 | 0
C25 | CAP0402_10NF | 10nF | (+80 -20%) | CMI0402 | Yes | Top | CAPACITOR, 0402 10NF 16V Y5V | PHYCOMP | CC0402ZRY5V7BB103 | FEC 3019421 | Yes | 27.75 | 137.75 | 0
C26 | CAP0402_10NF | 10nF | (+80 -20%) | CMI0402 | Yes | Top | CAPACITOR, 0402 10NF 16V Y5V | PHYCOMP | CC0402ZRY5V7BB103 | FEC 3019421 | Yes | 29.25 | 53.5 | 180
C27 | CAP0402_100NF | 0.1uF | (+80 -20%) | CMI0402 | Yes | Top | CAPACITOR, 0402 100NF 16V Y5V | PHYCOMP | CC0402ZRY5V7BB104 | FEC 3019482 | Yes | 29.25 | 52.5 | 180
C28 | CAPTAJA_4-7UF | 4.7uF | ±10% | RTAJ_A | Yes | Top | CAPACITOR, CASE A 4.7UF 10V TANTALUM | AVX | TAJA475K010R | FEC 498658 |  | 29 | 70.25 | 0
C29 | CAPTAJA_4-7UF | 4.7uF | ±10% | RTAJ_A | Yes | Top | CAPACITOR, CASE A 4.7UF 10V TANTALUM | AVX | TAJA475K010R | FEC 498658 |  | 29 | 67.25 | 0
C30 | CAP0402_100NF | 0.1uF | (+80 -20%) | CMI0402 | Yes | Top | CAPACITOR, 0402 100NF 16V Y5V | PHYCOMP | CC0402ZRY5V7BB104 | FEC 3019482 | Yes | 31.5 | 138.5 | 0
C31 | CAP0402_10NF | 10nF | (+80 -20%) | CMI0402 | Yes | Top | CAPACITOR, 0402 10NF 16V Y5V | PHYCOMP | CC0402ZRY5V7BB103 | FEC 3019421 | Yes | 31.5 | 137.5 | 0
C32 | CAP0402_10NF | 10nF | (+80 -20%) | CMI0402 | Yes | Top | CAPACITOR, 0402 10NF 16V Y5V | PHYCOMP | CC0402ZRY5V7BB103 | FEC 3019421 | Yes | 32.75 | 135 | 90
C33 | CAP0402_10NF | 10nF | (+80 -20%) | CMI0402 | Yes | Top | CAPACITOR, 0402 10NF 16V Y5V | PHYCOMP | CC0402ZRY5V7BB103 | FEC 3019421 | Yes | 32.75 | 126.5 | 270
C34 | CAP0402_100NF | 0.1uF | (+80 -20%) | CMI0402 | Yes | Top | CAPACITOR, 0402 100NF 16V Y5V | PHYCOMP | CC0402ZRY5V7BB104 | FEC 3019482 | Yes | 33.75 | 135 | 90
C35 | CAP0402_100NF | 0.1uF | (+80 -20%) | CMI0402 | Yes | Top | CAPACITOR, 0402 100NF 16V Y5V | PHYCOMP | CC0402ZRY5V7BB104 | FEC 3019482 | Yes | 33.75 | 126.5 | 270
C36 | CAP0402_100NF | 0.1uF | (+80 -20%) | CMI0402 | Yes | Top | CAPACITOR, 0402 100NF 16V Y5V | PHYCOMP | CC0402ZRY5V7BB104 | FEC 3019482 | Yes | 34.25 | 74.25 | 0
C37 | CAP0402_100NF | 0.1uF | (+80 -20%) | CMI0402 | Yes | Top | CAPACITOR, 0402 100NF 16V Y5V | PHYCOMP | CC0402ZRY5V7BB104 | FEC 3019482 | Yes | 34.25 | 68 | 0
C38 | CAP0603_12PF | 12pF | ±5% | CMI0603 | Yes | Top | CAPACITOR, 0603 12PF 50V | PHYCOMP | CC0603JRNPO9BN120 | FEC 721979 |  | 36 | 142.75 | 270
C39 | CAP0603_12PF | 12pF | ±5% | CMI0603 | Yes | Top | CAPACITOR, 0603 12PF 50V | PHYCOMP | CC0603JRNPO9BN120 | FEC 721979 |  | 36 | 139.25 | 90
C40 | CAP0603_47PF | 47pF | ±5% | CMI0603 | Yes | Top | CAPACITOR, 0603 47PF 50V C0G/NP0 | KEMET | C0603C470J5GACTU | FEC 1414639 |  | 35.25 | 32 | 270
C41 | CAP0603_47PF | 47pF | ±5% | CMI0603 | Yes | Top | CAPACITOR, 0603 47PF 50V C0G/NP0 | KEMET | C0603C470J5GACTU | FEC 1414639 |  | 35.25 | 28.5 | 90
C42 | CAPTAJA_4-7UF | 4.7uF | ±10% | RTAJ_A | Yes | Top | CAPACITOR, CASE A 4.7UF 10V TANTALUM | AVX | TAJA475K010R | FEC 498658 |  | 37.75 | 119.75 | 180
C43 | CAP+ | 47uF | ± 10% | CAP\TAJ_D | Yes | Top | CAPACITOR, CASE D, 47UF, 16V | KEMET | B45196H3476K409 | FEC 9753931 |  | 43.25 | 68 | 270
C44 | CAP0402_100NF | 0.1uF | (+80 -20%) | CMI0402 | Yes | Top | CAPACITOR, 0402 100NF 16V Y5V | PHYCOMP | CC0402ZRY5V7BB104 | FEC 3019482 | Yes | 47.5 | 73 | 90
C45 | CAP0402_100NF | 0.1uF | (+80 -20%) | CMI0402 | Yes | Top | CAPACITOR, 0402 100NF 16V Y5V | PHYCOMP | CC0402ZRY5V7BB104 | FEC 3019482 | Yes | 46.25 | 70.75 | 270
C46 | CAP | 39nF | ±10% | CMI0603 | Yes | Top | MLCC, 0603, X7R, 25V, 39NF | MULTICOMP | MCCA000172 | FEC 1759030 |  | 46.75 | 63 | 270
C47 | CAP0402_2-2NF | 2.2nF | ±10% | CMI0402 | Yes | Top | CAPACITOR, 0402, 2.2NF, 50V, X7R | PHYCOMP | CC0402KRX7R9BB222 | FEC 3019408 |  | 47.25 | 65 | 0
C48 | CAP0402_100NF | 0.1uF | (+80 -20%) | CMI0402 | Yes | Top | CAPACITOR, 0402 100NF 16V Y5V | PHYCOMP | CC0402ZRY5V7BB104 | FEC 3019482 | Yes | 50.75 | 77 | 0
C49 | CAP0402_100NF | 0.1uF | (+80 -20%) | CMI0402 | Yes | Top | CAPACITOR, 0402 100NF 16V Y5V | PHYCOMP | CC0402ZRY5V7BB104 | FEC 3019482 | Yes | 49.75 | 63 | 0
C50 | CAP0402_100NF | 0.1uF | (+80 -20%) | CMI0402 | Yes | Top | CAPACITOR, 0402 100NF 16V Y5V | PHYCOMP | CC0402ZRY5V7BB104 | FEC 3019482 | Yes | 51.75 | 75.25 | 180
C51 | CAP0402_100NF | 0.1uF | (+80 -20%) | CMI0402 | Yes | Top | CAPACITOR, 0402 100NF 16V Y5V | PHYCOMP | CC0402ZRY5V7BB104 | FEC 3019482 | Yes | 52.25 | 63 | 180
C52 | CAP+ | 10uF | ±10% | CAP\TAJ_C | Yes | Top | CAPACITOR, CASE C, 10UF, 16V | KEMET | T491C106K016AT | FEC 1457461 |  | 51.75 | 79.5 | 0
C53 | CAP0402_10NF | 10nF | (+80 -20%) | CMI0402 | Yes | Top | CAPACITOR, 0402 10NF 16V Y5V | PHYCOMP | CC0402ZRY5V7BB103 | FEC 3019421 | Yes | 55.5 | 55.25 | 0
C54 | CAP0402_100NF | 0.1uF | (+80 -20%) | CMI0402 | Yes | Top | CAPACITOR, 0402 100NF 16V Y5V | PHYCOMP | CC0402ZRY5V7BB104 | FEC 3019482 | Yes | 55.5 | 54 | 0
C55 | CAP0402_100NF | 0.1uF | (+80 -20%) | CMI0402 | Yes | Top | CAPACITOR, 0402 100NF 16V Y5V | PHYCOMP | CC0402ZRY5V7BB104 | FEC 3019482 | Yes | 57.5 | 63.75 | 180
C56 | CAP0603_18PF | 18pF | ±5% | CMI0603 | Yes | Top | CAPACITOR, 0603 18PF 50V C0G/NP0 | KEMET | C0603C180J5GAC | FEC 1414620 |  | 68.25 | 121 | 270
C57 | CAP0603_18PF | 18pF | ±5% | CMI0603 | Yes | Top | CAPACITOR, 0603 18PF 50V C0G/NP0 | KEMET | C0603C180J5GAC | FEC 1414620 |  | 68.25 | 117.5 | 90
C58 | CAP0402_100NF | 0.1uF | (+80 -20%) | CMI0402 | Yes | Top | CAPACITOR, 0402 100NF 16V Y5V | PHYCOMP | CC0402ZRY5V7BB104 | FEC 3019482 | Yes | 79.75 | 123.5 | 180
C59 | CAPTAJA_4-7UF | 4.7uF | ±10% | RTAJ_A | Yes | Top | CAPACITOR, CASE A 4.7UF 10V TANTALUM | AVX | TAJA475K010R | FEC 498658 |  | 80.25 | 118.75 | 90
C60 | CAP0402_100NF | 0.1uF | (+80 -20%) | CMI0402 | Yes | Top | CAPACITOR, 0402 100NF 16V Y5V | PHYCOMP | CC0402ZRY5V7BB104 | FEC 3019482 | Yes | 81.75 | 133 | 0
C61 | CAP0402_100NF | 0.1uF | (+80 -20%) | CMI0402 | Yes | Top | CAPACITOR, 0402 100NF 16V Y5V | PHYCOMP | CC0402ZRY5V7BB104 | FEC 3019482 | Yes | 82.5 | 123.5 | 0
C62 | CAP0402_100NF | 0.1uF | (+80 -20%) | CMI0402 | Yes | Top | CAPACITOR, 0402 100NF 16V Y5V | PHYCOMP | CC0402ZRY5V7BB104 | FEC 3019482 | Yes | 82.75 | 44.5 | 0
C63 | CAP0402_100NF | 0.1uF | (+80 -20%) | CMI0402 | Yes | Top | CAPACITOR, 0402 100NF 16V Y5V | PHYCOMP | CC0402ZRY5V7BB104 | FEC 3019482 | Yes | 82.75 | 38.5 | 0
C64 | CAP0402_100NF | 0.1uF | (+80 -20%) | CMI0402 | Yes | Top | CAPACITOR, 0402 100NF 16V Y5V | PHYCOMP | CC0402ZRY5V7BB104 | FEC 3019482 | Yes | 82.75 | 32.5 | 0
C65 | CAP0402_100NF | 0.1uF | (+80 -20%) | CMI0402 | Yes | Top | CAPACITOR, 0402 100NF 16V Y5V | PHYCOMP | CC0402ZRY5V7BB104 | FEC 3019482 | Yes | 85.5 | 123.5 | 0
C66 | CAP0402_100NF | 0.1uF | (+80 -20%) | CMI0402 | Yes | Top | CAPACITOR, 0402 100NF 16V Y5V | PHYCOMP | CC0402ZRY5V7BB104 | FEC 3019482 | Yes | 88.25 | 123.5 | 0
C67 | CAP0402_100NF | 0.1uF | (+80 -20%) | CMI0402 | Yes | Top | CAPACITOR, 0402 100NF 16V Y5V | PHYCOMP | CC0402ZRY5V7BB104 | FEC 3019482 | Yes | 94.25 | 133.75 | 180
C68 | CAP0402_10NF | 10nF | (+80 -20%) | CMI0402 | Yes | Top | CAPACITOR, 0402 10NF 16V Y5V | PHYCOMP | CC0402ZRY5V7BB103 | FEC 3019421 | Yes | 94.25 | 132.75 | 180
C69 | CAP0402_100NF | 0.1uF | (+80 -20%) | CMI0402 | Yes | Top | CAPACITOR, 0402 100NF 16V Y5V | PHYCOMP | CC0402ZRY5V7BB104 | FEC 3019482 | Yes | 94.75 | 87.75 | 0
C70 | CAP0402_100NF | 0.1uF | (+80 -20%) | CMI0402 | Yes | Top | CAPACITOR, 0402 100NF 16V Y5V | PHYCOMP | CC0402ZRY5V7BB104 | FEC 3019482 | Yes | 94.75 | 81.75 | 0
C71 | CAPELEC_22UF | 22uF | ±20% | ELEK_SMD_B | Yes | Top | CAPACITOR, CASE B, 22UF, 16V | PANASONIC | EEEFK1C220UR | FEC 9695656 |  | 93 | 70.75 | 180
C72 | MCESL10V227M6_3X7_7 | 220uF | ±20% | MCESL10V227M6_3X7_7 | Yes | Top | CAPACITOR CASE G 220UF 10V | MULTICOMP | MCESL10V227M6.3X7.7 | FEC 9265678 | Yes | 95.25 | 47.75 | 180
C73 | CAP0603_470NF | 470nF | ±20% | CMI0603 | Yes | Top | CAPACITOR, 0603 470NF 16V X7R | KEMET | C0603C474K4RAC | FEC 1414644 |  | 99.25 | 75.25 | 180
C74 | CAP0402_100NF | 0.1uF | (+80 -20%) | CMI0402 | Yes | Top | CAPACITOR, 0402 100NF 16V Y5V | PHYCOMP | CC0402ZRY5V7BB104 | FEC 3019482 | Yes | 103.5 | 145.75 | 270
C75 | CAP0402_100NF | 0.1uF | (+80 -20%) | CMI0402 | Yes | Top | CAPACITOR, 0402 100NF 16V Y5V | PHYCOMP | CC0402ZRY5V7BB104 | FEC 3019482 | Yes | 102 | 128 | 0
C76 | CAP0402_100NF | 0.1uF | (+80 -20%) | CMI0402 | Yes | Top | CAPACITOR, 0402 100NF 16V Y5V | PHYCOMP | CC0402ZRY5V7BB104 | FEC 3019482 | Yes | 102 | 121.5 | 0
C77 | CAP0402_100NF | 0.1uF | (+80 -20%) | CMI0402 | Yes | Top | CAPACITOR, 0402 100NF 16V Y5V | PHYCOMP | CC0402ZRY5V7BB104 | FEC 3019482 | Yes | 102 | 115.5 | 0
C78 | CAP0402_100NF | 0.1uF | (+80 -20%) | CMI0402 | Yes | Top | CAPACITOR, 0402 100NF 16V Y5V | PHYCOMP | CC0402ZRY5V7BB104 | FEC 3019482 | Yes | 102 | 109.75 | 0
C79 | MCESL10V227M6_3X7_7 | 220uF | ±20% | MCESL10V227M6_3X7_7 | Yes | Top | CAPACITOR CASE G 220UF 10V | MULTICOMP | MCESL10V227M6.3X7.7 | FEC 9265678 | Yes | 102.5 | 30 | 0
C80 | CAP0402_100NF | 0.1uF | (+80 -20%) | CMI0402 | Yes | Top | CAPACITOR, 0402 100NF 16V Y5V | PHYCOMP | CC0402ZRY5V7BB104 | FEC 3019482 | Yes | 105.75 | 136.75 | 0
C81 | CAP0402_100NF | 0.1uF | (+80 -20%) | CMI0402 | Yes | Top | CAPACITOR, 0402 100NF 16V Y5V | PHYCOMP | CC0402ZRY5V7BB104 | FEC 3019482 | Yes | 109.75 | 57.25 | 180
C82 | CAP0402_100NF | 0.1uF | (+80 -20%) | CMI0402 | Yes | Top | CAPACITOR, 0402 100NF 16V Y5V | PHYCOMP | CC0402ZRY5V7BB104 | FEC 3019482 | Yes | 109.75 | 51.25 | 180
C83 | CAP0402_100NF | 0.1uF | (+80 -20%) | CMI0402 | Yes | Top | CAPACITOR, 0402 100NF 16V Y5V | PHYCOMP | CC0402ZRY5V7BB104 | FEC 3019482 | Yes | 109.75 | 45 | 180
C84 | CAP0402_100NF | 0.1uF | (+80 -20%) | CMI0402 | Yes | Top | CAPACITOR, 0402 100NF 16V Y5V | PHYCOMP | CC0402ZRY5V7BB104 | FEC 3019482 | Yes | 109.75 | 39 | 180
C85 | CAP0402_100NF | 0.1uF | (+80 -20%) | CMI0402 | Yes | Top | CAPACITOR, 0402 100NF 16V Y5V | PHYCOMP | CC0402ZRY5V7BB104 | FEC 3019482 | Yes | 109.75 | 33 | 180
C86 | MCESL10V227M6_3X7_7 | 220uF | ±20% | MCESL10V227M6_3X7_7 | Yes | Top | CAPACITOR CASE G 220UF 10V | MULTICOMP | MCESL10V227M6.3X7.7 | FEC 9265678 | Yes | 116.25 | 125.25 | 0
C87 | MCESL10V227M6_3X7_7 | 220uF | ±20% | MCESL10V227M6_3X7_7 | Yes | Top | CAPACITOR CASE G 220UF 10V | MULTICOMP | MCESL10V227M6.3X7.7 | FEC 9265678 | Yes | 115.25 | 79 | 0
C88 | MCESL10V227M6_3X7_7 | 220uF | ±20% | MCESL10V227M6_3X7_7 | Yes | Top | CAPACITOR CASE G 220UF 10V | MULTICOMP | MCESL10V227M6.3X7.7 | FEC 9265678 | Yes | 120 | 140.25 | 0
C89 | MCESL10V227M6_3X7_7 | 220uF | ±20% | MCESL10V227M6_3X7_7 | Yes | Top | CAPACITOR CASE G 220UF 10V | MULTICOMP | MCESL10V227M6.3X7.7 | FEC 9265678 | Yes | 120 | 132.75 | 0
C90 | CAP0402_100NF | 0.1uF | (+80 -20%) | CMI0402 | Yes | Top | CAPACITOR, 0402 100NF 16V Y5V | PHYCOMP | CC0402ZRY5V7BB104 | FEC 3019482 | Yes | 122.5 | 110 | 180
C91 | CAP0402_100NF | 0.1uF | (+80 -20%) | CMI0402 | Yes | Top | CAPACITOR, 0402 100NF 16V Y5V | PHYCOMP | CC0402ZRY5V7BB104 | FEC 3019482 | Yes | 122.5 | 104.25 | 180
C92 | CAP0402_100NF | 0.1uF | (+80 -20%) | CMI0402 | Yes | Top | CAPACITOR, 0402 100NF 16V Y5V | PHYCOMP | CC0402ZRY5V7BB104 | FEC 3019482 | Yes | 131.5 | 145.75 | 270
C93 | CAP0402_NI | NI | n/a | CMI0402 | Yes | Top | SMD CAPACITOR 0402 | Not Inserted | Not Inserted | Not Inserted |  | 141.75 | 67.75 | 180
C94 | CAP0402_100NF | 0.1uF | (+80 -20%) | CMI0402 | Yes | Top | CAPACITOR, 0402 100NF 16V Y5V | PHYCOMP | CC0402ZRY5V7BB104 | FEC 3019482 | Yes | 146.5 | 80 | 90
C95 | CAP0402_2-2NF | 2.2nF | ±10% | CMI0402 | Yes | Top | CAPACITOR, 0402, 2.2NF, 50V, X7R | PHYCOMP | CC0402KRX7R9BB222 | FEC 3019408 |  | 147 | 78.25 | 180
C96 | CAP0603_12NF | 12nF | ±10% | CMI0603 | Yes | Top | CAPACITOR, 0603, 12NF, 25V, X7R | PHYCOMP | CC0603KRX7R8BB123 | FEC 3019573 |  | 145.75 | 68.5 | 0
C97 | CAP0603_150NF | 150nF | ±10% | CMI0603 | Yes | Top | CAPACITOR,0.15UF 10V X7R | PHYCOMP | CC0603KRX7R6BB154 | FEC 3352006 |  | 146.5 | 66.25 | 90
C98 | CAP0402_2-2NF | 2.2nF | ±10% | CMI0402 | Yes | Top | CAPACITOR, 0402, 2.2NF, 50V, X7R | PHYCOMP | CC0402KRX7R9BB222 | FEC 3019408 |  | 147.75 | 70.75 | 180
C99 | CAP0402_100NF | 0.1uF | (+80 -20%) | CMI0402 | Yes | Top | CAPACITOR, 0402 100NF 16V Y5V | PHYCOMP | CC0402ZRY5V7BB104 | FEC 3019482 | Yes | 154.5 | 66 | 90
C100 | CAP0402_10NF | 10nF | (+80 -20%) | CMI0402 | Yes | Top | CAPACITOR, 0402 10NF 16V Y5V | PHYCOMP | CC0402ZRY5V7BB103 | FEC 3019421 | Yes | 153.5 | 66 | 90
C101 | CAP0402_100NF | 0.1uF | (+80 -20%) | CMI0402 | Yes | Top | CAPACITOR, 0402 100NF 16V Y5V | PHYCOMP | CC0402ZRY5V7BB104 | FEC 3019482 | Yes | 154.5 | 56 | 90
C102 | CAP0402_10NF | 10nF | (+80 -20%) | CMI0402 | Yes | Top | CAPACITOR, 0402 10NF 16V Y5V | PHYCOMP | CC0402ZRY5V7BB103 | FEC 3019421 | Yes | 153.5 | 56 | 90
C103 | CAP0402_100NF | 0.1uF | (+80 -20%) | CMI0402 | Yes | Top | CAPACITOR, 0402 100NF 16V Y5V | PHYCOMP | CC0402ZRY5V7BB104 | FEC 3019482 | Yes | 154.5 | 48.25 | 90
C104 | CAP0402_10NF | 10nF | (+80 -20%) | CMI0402 | Yes | Top | CAPACITOR, 0402 10NF 16V Y5V | PHYCOMP | CC0402ZRY5V7BB103 | FEC 3019421 | Yes | 153.5 | 48.25 | 90
C105 | CAP0402_10NF | 10nF | (+80 -20%) | CMI0402 | Yes | Top | CAPACITOR, 0402 10NF 16V Y5V | PHYCOMP | CC0402ZRY5V7BB103 | FEC 3019421 | Yes | 155.25 | 9.5 | 0
C106 | CAP0402_100NF | 0.1uF | (+80 -20%) | CMI0402 | Yes | Top | CAPACITOR, 0402 100NF 16V Y5V | PHYCOMP | CC0402ZRY5V7BB104 | FEC 3019482 | Yes | 155.25 | 8.25 | 0
C107 | CAP+_ELEK | 1000uF | ±20% | CAP_ELEK_200 | No | Top | CAPACITOR, 1000UF 16V | PANASONIC | ECA1CM102 | FEC 9693610 |  | 145 | 141.5 | 180
C108 | CAP0603_NI | NI | n/a | CMI0603 | Yes | Top | SMD CAPACITOR 0603 | Not Inserted | Not Inserted | Not Inserted |  | 162.75 | 12 | 0
C109 | CAP0402_220PF | 220pF | ±5% | CMI0402 | Yes | Bottom | CAPACITOR, 0402 220PF 50V C0G/NP0 | PHYCOMP | CC0402JRNPO9BN221 | FEC 3019240 | Yes | 5.75 | 77.75 | 0
C110 | CAP0402_220PF | 220pF | ±5% | CMI0402 | Yes | Bottom | CAPACITOR, 0402 220PF 50V C0G/NP0 | PHYCOMP | CC0402JRNPO9BN221 | FEC 3019240 | Yes | 5.75 | 57.25 | 0
C111 | CAP0402_220PF | 220pF | ±5% | CMI0402 | Yes | Bottom | CAPACITOR, 0402 220PF 50V C0G/NP0 | PHYCOMP | CC0402JRNPO9BN221 | FEC 3019240 | Yes | 10.5 | 99.75 | 0
C112 | CAP0402_220PF | 220pF | ±5% | CMI0402 | Yes | Bottom | CAPACITOR, 0402 220PF 50V C0G/NP0 | PHYCOMP | CC0402JRNPO9BN221 | FEC 3019240 | Yes | 14 | 146.5 | 0
C113 | CAP0402_220PF | 220pF | ±5% | CMI0402 | Yes | Bottom | CAPACITOR, 0402 220PF 50V C0G/NP0 | PHYCOMP | CC0402JRNPO9BN221 | FEC 3019240 | Yes | 19.75 | 124 | 0
C114 | CAP0402_220PF | 220pF | ±5% | CMI0402 | Yes | Bottom | CAPACITOR, 0402 220PF 50V C0G/NP0 | PHYCOMP | CC0402JRNPO9BN221 | FEC 3019240 | Yes | 24 | 38 | 0
C115 | CAP0402_220PF | 220pF | ±5% | CMI0402 | Yes | Bottom | CAPACITOR, 0402 220PF 50V C0G/NP0 | PHYCOMP | CC0402JRNPO9BN221 | FEC 3019240 | Yes | 28 | 59.75 | 0
C116 | CAP0402_220PF | 220pF | ±5% | CMI0402 | Yes | Bottom | CAPACITOR, 0402 220PF 50V C0G/NP0 | PHYCOMP | CC0402JRNPO9BN221 | FEC 3019240 | Yes | 42 | 127.25 | 0
C117 | CAP0402_220PF | 220pF | ±5% | CMI0402 | Yes | Bottom | CAPACITOR, 0402 220PF 50V C0G/NP0 | PHYCOMP | CC0402JRNPO9BN221 | FEC 3019240 | Yes | 39.75 | 87.5 | 0
C118 | CAP0402_220PF | 220pF | ±5% | CMI0402 | Yes | Bottom | CAPACITOR, 0402 220PF 50V C0G/NP0 | PHYCOMP | CC0402JRNPO9BN221 | FEC 3019240 | Yes | 43 | 20.25 | 0
C119 | CAP0402_100NF | 0.1uF | (+80 -20%) | CMI0402 | Yes | Bottom | CAPACITOR, 0402 100NF 16V Y5V | PHYCOMP | CC0402ZRY5V7BB104 | FEC 3019482 | Yes | 45 | 34.25 | 180
C120 | CAP0402_100NF | 0.1uF | (+80 -20%) | CMI0402 | Yes | Bottom | CAPACITOR, 0402 100NF 16V Y5V | PHYCOMP | CC0402ZRY5V7BB104 | FEC 3019482 | Yes | 45 | 31.75 | 180
C121 | CAP0402_100NF | 0.1uF | (+80 -20%) | CMI0402 | Yes | Bottom | CAPACITOR, 0402 100NF 16V Y5V | PHYCOMP | CC0402ZRY5V7BB104 | FEC 3019482 | Yes | 45 | 30.75 | 180
C122 | CAP0402_100NF | 0.1uF | (+80 -20%) | CMI0402 | Yes | Bottom | CAPACITOR, 0402 100NF 16V Y5V | PHYCOMP | CC0402ZRY5V7BB104 | FEC 3019482 | Yes | 44.75 | 29 | 90
C123 | CAP0402_100NF | 0.1uF | (+80 -20%) | CMI0402 | Yes | Bottom | CAPACITOR, 0402 100NF 16V Y5V | PHYCOMP | CC0402ZRY5V7BB104 | FEC 3019482 | Yes | 46.5 | 35.25 | 270
C124 | CAP0402_100NF | 0.1uF | (+80 -20%) | CMI0402 | Yes | Bottom | CAPACITOR, 0402 100NF 16V Y5V | PHYCOMP | CC0402ZRY5V7BB104 | FEC 3019482 | Yes | 46.25 | 26.5 | 270
C125 | CAP0402_1UF | 1uF | ±10% | CMI0402 | Yes | Bottom | CAPACITOR, 0402 1UF, 10V X5R | PHYCOMP | CC0402KRX5R6BB105 | FEC 1458896 | Yes | 48.5 | 119.25 | 270
C126 | CAP0402_100NF | 0.1uF | (+80 -20%) | CMI0402 | Yes | Bottom | CAPACITOR, 0402 100NF 16V Y5V | PHYCOMP | CC0402ZRY5V7BB104 | FEC 3019482 | Yes | 48.5 | 110.75 | 270
C127 | CAP0402_220PF | 220pF | ±5% | CMI0402 | Yes | Bottom | CAPACITOR, 0402 220PF 50V C0G/NP0 | PHYCOMP | CC0402JRNPO9BN221 | FEC 3019240 | Yes | 49.75 | 97.5 | 0
C128 | CAP0402_100NF | 0.1uF | (+80 -20%) | CMI0402 | Yes | Bottom | CAPACITOR, 0402 100NF 16V Y5V | PHYCOMP | CC0402ZRY5V7BB104 | FEC 3019482 | Yes | 48.5 | 35.25 | 270
C129 | CAP0402_100NF | 0.1uF | (+80 -20%) | CMI0402 | Yes | Bottom | CAPACITOR, 0402 100NF 16V Y5V | PHYCOMP | CC0402ZRY5V7BB104 | FEC 3019482 | Yes | 47.75 | 26.5 | 270
C130 | CAP0402_220PF | 220pF | ±5% | CMI0402 | Yes | Bottom | CAPACITOR, 0402 220PF 50V C0G/NP0 | PHYCOMP | CC0402JRNPO9BN221 | FEC 3019240 | Yes | 49.75 | 143.5 | 0
C131 | CAP0402_220PF | 220pF | ±5% | CMI0402 | Yes | Bottom | CAPACITOR, 0402 220PF 50V C0G/NP0 | PHYCOMP | CC0402JRNPO9BN221 | FEC 3019240 | Yes | 49 | 125.5 | 0
C132 | CAP0402_100NF | 0.1uF | (+80 -20%) | CMI0402 | Yes | Bottom | CAPACITOR, 0402 100NF 16V Y5V | PHYCOMP | CC0402ZRY5V7BB104 | FEC 3019482 | Yes | 50 | 119.25 | 270
C133 | CAP0402_1UF | 1uF | ±10% | CMI0402 | Yes | Bottom | CAPACITOR, 0402 1UF, 10V X5R | PHYCOMP | CC0402KRX5R6BB105 | FEC 1458896 | Yes | 50 | 110.75 | 270
C134 | CAP0402_100NF | 0.1uF | (+80 -20%) | CMI0402 | Yes | Bottom | CAPACITOR, 0402 100NF 16V Y5V | PHYCOMP | CC0402ZRY5V7BB104 | FEC 3019482 | Yes | 49.25 | 26.5 | 270
C135 | CAP0402_100NF | 0.1uF | (+80 -20%) | CMI0402 | Yes | Bottom | CAPACITOR, 0402 100NF 16V Y5V | PHYCOMP | CC0402ZRY5V7BB104 | FEC 3019482 | Yes | 51 | 35.25 | 270
C136 | CAP0402_100NF | 0.1uF | (+80 -20%) | CMI0402 | Yes | Bottom | CAPACITOR, 0402 100NF 16V Y5V | PHYCOMP | CC0402ZRY5V7BB104 | FEC 3019482 | Yes | 51 | 31.75 | 0
C137 | CAP0402_100NF | 0.1uF | (+80 -20%) | CMI0402 | Yes | Bottom | CAPACITOR, 0402 100NF 16V Y5V | PHYCOMP | CC0402ZRY5V7BB104 | FEC 3019482 | Yes | 50.75 | 29 | 90
C138 | CAP0402_1UF | 1uF | ±10% | CMI0402 | Yes | Bottom | CAPACITOR, 0402 1UF, 10V X5R | PHYCOMP | CC0402KRX5R6BB105 | FEC 1458896 | Yes | 53.75 | 122 | 180
C139 | CAP0402_100NF | 0.1uF | (+80 -20%) | CMI0402 | Yes | Bottom | CAPACITOR, 0402 100NF 16V Y5V | PHYCOMP | CC0402ZRY5V7BB104 | FEC 3019482 | Yes | 53.75 | 120.5 | 180
C140 | CAP0402_100NF | 0.1uF | (+80 -20%) | CMI0402 | Yes | Bottom | CAPACITOR, 0402 100NF 16V Y5V | PHYCOMP | CC0402ZRY5V7BB104 | FEC 3019482 | Yes | 53.25 | 109.5 | 0
C141 | CAP0402_1UF | 1uF | ±10% | CMI0402 | Yes | Bottom | CAPACITOR, 0402 1UF, 10V X5R | PHYCOMP | CC0402KRX5R6BB105 | FEC 1458896 | Yes | 53.25 | 108 | 0
C142 | CAP0402_220PF | 220pF | ±5% | CMI0402 | Yes | Bottom | CAPACITOR, 0402 220PF 50V C0G/NP0 | PHYCOMP | CC0402JRNPO9BN221 | FEC 3019240 | Yes | 61 | 38.5 | 0
C143 | CAP0402_220PF | 220pF | ±5% | CMI0402 | Yes | Bottom | CAPACITOR, 0402 220PF 50V C0G/NP0 | PHYCOMP | CC0402JRNPO9BN221 | FEC 3019240 | Yes | 53.25 | 20 | 0
C144 | CAP0402_220PF | 220pF | ±5% | CMI0402 | Yes | Bottom | CAPACITOR, 0402 220PF 50V C0G/NP0 | PHYCOMP | CC0402JRNPO9BN221 | FEC 3019240 | Yes | 55.75 | 117.25 | 0
C145 | CAP0402_100NF | 0.1uF | (+80 -20%) | CMI0402 | Yes | Bottom | CAPACITOR, 0402 100NF 16V Y5V | PHYCOMP | CC0402ZRY5V7BB104 | FEC 3019482 | Yes | 57 | 31.75 | 180
C146 | CAP0402_1UF | 1uF | ±10% | CMI0402 | Yes | Bottom | CAPACITOR, 0402 1UF, 10V X5R | PHYCOMP | CC0402KRX5R6BB105 | FEC 1458896 | Yes | 59.75 | 122 | 0
C147 | CAP0402_100NF | 0.1uF | (+80 -20%) | CMI0402 | Yes | Bottom | CAPACITOR, 0402 100NF 16V Y5V | PHYCOMP | CC0402ZRY5V7BB104 | FEC 3019482 | Yes | 59.75 | 120.5 | 0
C148 | CAP0402_100NF | 0.1uF | (+80 -20%) | CMI0402 | Yes | Bottom | CAPACITOR, 0402 100NF 16V Y5V | PHYCOMP | CC0402ZRY5V7BB104 | FEC 3019482 | Yes | 61 | 117.5 | 270
C149 | CAP0402_100NF | 0.1uF | (+80 -20%) | CMI0402 | Yes | Bottom | CAPACITOR, 0402 100NF 16V Y5V | PHYCOMP | CC0402ZRY5V7BB104 | FEC 3019482 | Yes | 61 | 115.5 | 90
C150 | CAP0402_100NF | 0.1uF | (+80 -20%) | CMI0402 | Yes | Bottom | CAPACITOR, 0402 100NF 16V Y5V | PHYCOMP | CC0402ZRY5V7BB104 | FEC 3019482 | Yes | 59.75 | 109.5 | 180
C151 | CAP0402_1UF | 1uF | ±10% | CMI0402 | Yes | Bottom | CAPACITOR, 0402 1UF, 10V X5R | PHYCOMP | CC0402KRX5R6BB105 | FEC 1458896 | Yes | 59.75 | 108 | 180
C152 | CAP0402_1UF | 1uF | ±10% | CMI0402 | Yes | Bottom | CAPACITOR, 0402 1UF, 10V X5R | PHYCOMP | CC0402KRX5R6BB105 | FEC 1458896 | Yes | 62.5 | 117.5 | 270
C153 | CAP0402_1UF | 1uF | ±10% | CMI0402 | Yes | Bottom | CAPACITOR, 0402 1UF, 10V X5R | PHYCOMP | CC0402KRX5R6BB105 | FEC 1458896 | Yes | 62.5 | 115.5 | 90
C154 | CAP0402_100NF | 0.1uF | (+80 -20%) | CMI0402 | Yes | Bottom | CAPACITOR, 0402 100NF 16V Y5V | PHYCOMP | CC0402ZRY5V7BB104 | FEC 3019482 | Yes | 65.5 | 115 | 270
C155 | CAP0402_100NF | 0.1uF | (+80 -20%) | CMI0402 | Yes | Bottom | CAPACITOR, 0402 100NF 16V Y5V | PHYCOMP | CC0402ZRY5V7BB104 | FEC 3019482 | Yes | 65.5 | 113 | 90
C156 | CAP0402_220PF | 220pF | ±5% | CMI0402 | Yes | Bottom | CAPACITOR, 0402 220PF 50V C0G/NP0 | PHYCOMP | CC0402JRNPO9BN221 | FEC 3019240 | Yes | 64.75 | 85.75 | 0
C157 | CAP0402_220PF | 220pF | ±5% | CMI0402 | Yes | Bottom | CAPACITOR, 0402 220PF 50V C0G/NP0 | PHYCOMP | CC0402JRNPO9BN221 | FEC 3019240 | Yes | 64.75 | 48.25 | 0
C158 | CAP0402_220PF | 220pF | ±5% | CMI0402 | Yes | Bottom | CAPACITOR, 0402 220PF 50V C0G/NP0 | PHYCOMP | CC0402JRNPO9BN221 | FEC 3019240 | Yes | 60.75 | 24.5 | 0
C159 | CAP0402_220PF | 220pF | ±5% | CMI0402 | Yes | Bottom | CAPACITOR, 0402 220PF 50V C0G/NP0 | PHYCOMP | CC0402JRNPO9BN221 | FEC 3019240 | Yes | 67.5 | 99.25 | 0
C160 | CAP0402_220PF | 220pF | ±5% | CMI0402 | Yes | Bottom | CAPACITOR, 0402 220PF 50V C0G/NP0 | PHYCOMP | CC0402JRNPO9BN221 | FEC 3019240 | Yes | 71.25 | 77.5 | 0
C161 | CAP0402_220PF | 220pF | ±5% | CMI0402 | Yes | Bottom | CAPACITOR, 0402 220PF 50V C0G/NP0 | PHYCOMP | CC0402JRNPO9BN221 | FEC 3019240 | Yes | 73.25 | 44.75 | 0
C162 | CAP0402_220PF | 220pF | ±5% | CMI0402 | Yes | Bottom | CAPACITOR, 0402 220PF 50V C0G/NP0 | PHYCOMP | CC0402JRNPO9BN221 | FEC 3019240 | Yes | 75.25 | 129.5 | 0
C163 | CAP0402_220PF | 220pF | ±5% | CMI0402 | Yes | Bottom | CAPACITOR, 0402 220PF 50V C0G/NP0 | PHYCOMP | CC0402JRNPO9BN221 | FEC 3019240 | Yes | 75 | 111 | 0
C164 | CAP0402_220PF | 220pF | ±5% | CMI0402 | Yes | Bottom | CAPACITOR, 0402 220PF 50V C0G/NP0 | PHYCOMP | CC0402JRNPO9BN221 | FEC 3019240 | Yes | 88.75 | 120.75 | 0
C165 | CAPTAJB_33UF | 33uF | ±10% | RTAJ_B | Yes | Bottom | CAPACITOR, CASE B 33UF 6.3V TANTALUM | AVX | TAJB336K006R | FEC 197040 | Yes | 87 | 41.75 | 180
C166 | CAPTAJB_33UF | 33uF | ±10% | RTAJ_B | Yes | Bottom | CAPACITOR, CASE B 33UF 6.3V TANTALUM | AVX | TAJB336K006R | FEC 197040 | Yes | 87 | 35.75 | 180
C167 | CAPTAJB_33UF | 33uF | ±10% | RTAJ_B | Yes | Bottom | CAPACITOR, CASE B 33UF 6.3V TANTALUM | AVX | TAJB336K006R | FEC 197040 | Yes | 87 | 29.75 | 180
C168 | CAP0402_220PF | 220pF | ±5% | CMI0402 | Yes | Bottom | CAPACITOR, 0402 220PF 50V C0G/NP0 | PHYCOMP | CC0402JRNPO9BN221 | FEC 3019240 | Yes | 97.75 | 142.75 | 0
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

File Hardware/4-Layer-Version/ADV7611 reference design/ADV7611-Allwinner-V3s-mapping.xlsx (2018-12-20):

Allwinner V3s Input | 16bit Mapping | ADV7611 Output
D0 | Y0 | P8
D1 | Y1 | P9
D2 | Y2 | P10
D3 | Y3 | P11
D4 | Y4 | P12
D5 | Y5 | P13
D6 | Y6 | P14
D7 | Y7 | P15
D8 | C0 | P0
D9 | C1 | P1
D10 | C2 | P2
D11 | C3 | P3
D12 | C4 | P4
D13 | C5 | P5
D14 | C6 | P6
D15 | C7 | P7

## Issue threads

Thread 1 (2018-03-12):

PCB design discussion

tido-, 2018-03-12:
Allwinner V3s SoC features two CSI module. CSI0 is used for MIPI CSI-2 interface and CSI1 is used for parallel interface. This is not documented in datasheet but by test and guess.

Falls du das noch nicht gesehen hast, mehr dazu: https://www.spinics.net/lists/linux-media/msg128062.html

petit-miner, 2018-03-13:
Ja das habe ich gesehen. Ich weiß nur noch nicht welche Kamera ich verwenden soll, bzw. welche überhaupt unterstützt wird. Ich hätte da an die OV2640 (2MP) oder an die OV5640 (5MP) gedacht. Was meinen Sie?

tido-, 2018-03-14:
Ich habe mich noch mit einem Moderator bei Armbian dazu ausgetauscht. Er meinte es ist eine Frage der erhältlichen Treiber und es gibt viele action-cams die mit [V3 & 8MP Sony Sensor](https://www.youtube.com/watch?v=PIgrToh81Nw) IMX179 laufen, aber ich weiss nicht wie es um die Treiber steht.

Übrigens bei [spinics ist schon v9](https://www.spinics.net/lists/linux-media/msg130006.html) draussen.

tido-, 2018-03-15:
Eine gute Frage.
Eventuell hat der erschaffer von Lichee Pi was in seinen Dateien?
Warst du schon hier: https://www.digi.com/resources/documentation/digidocs/90001546/reference/bsp/cc6/r_mipi.htm

Und das kennst du wahrscheinlich auch https://groups.google.com/forum/#!searchin/linux-sunxi/v3s%7Csort:date/linux-sunxi/Cu5ldv_SzSc/73FR9h50BAAJ

Macht es Sinn das Design trotzdem auf MIPI CSI auszulegen oder gibt es eine Alternative ?

petit-miner, 2018-03-16:
Geplant ist ein MIPI CSI FPC Connector der kompatibel mit der Raspberry Pi Kamera ist.
Vielleicht wird ja irgendwann MIPI CSI doch noch unterstützt.

tido-, 2018-03-16:
Ist der Anschluss für die RPi-Kamera derselbe wie für die OV5640 (5MP) ?

Was ändert sich gemäss dieser Aussage: nicht mehr Raspberry Pi form factor ?

petit-miner, 2018-03-16:
Auf der Raspberry Pi Kamera wird der OV5647 IC verwendet, welcher über MIPI CSI angesprochen wird.
Auf dem Blueberry Pi wird es eine pinkompatible FPC-Buchse für die Raspberry PI Kamera geben.
Der OV5640 und der OV5647 haben neben einem parallem Port auch eine MIPI CSI Schnittstelle.
Wobei ich auf Ebay und co. die OV5640 nur als parallel finde. Die OV5647 nur als Raspberry Pi Kamera also MIPI CSI.

Also der MIPI CSI Port und der parallel Port (CSI / LCD) sind von einander getrennt.
Ein Raspberry Pi form factor ist mit diesen ganzen Schnittstellen, der Lage der einzelnen Schnittstellen auf einem 2-Layer board nicht zu schaffen. Desweiteren kommt dazu, dass es zu wenig GPIOs gibt um einen 40 Pin GPIO Header möglich zu machen. Unter Hardware/pictures/ habe ich einen Vorentwurf hochgeladen, wo ungefähr welche Schnittstelle sitzt. Da ändert sich wahrscheinlich noch was dran.

tido-, 2018-03-17:
OV5647 - die muss doch aber einen Treiber für den RPi haben..

Im 2 Lagen Design wird das PCB recht gross, viele Freiflächen, was ist denn der limitierende Faktor(en) statt 3 oder 4 lagig ?
Sind in deinem Design auch noch LED (power, activity) vorgesehen?

Auch wenn der Header nur 28 hat aber in derselben Reihenfolge wie der RPi, so wäre er doch für viele 'Hat' verwendbar. Ein Bild von der Unterseite wäre noch interessant.

petit-miner, 2018-03-17:
Ja die OV5647 wird von Linux unterstützt, ob MIPI CSI oder auch der Parallele Ausgang unterstützt wird weiß ich nicht. Das übersteigt dann doch mein Wissen.  Ich habe bisher für Kameras irgendwie nur die I²C Treiber gefunden. Wo sind die Treiber für die Kamera selber? Oder gibt es keine weil keine nötig sind, da MIPI CSI Standardisiert ist?

Power LED und Act LED sind natürlich Pflicht, hatte ich bisher nur noch nicht aufgeschrieben.

Das Problem mit dem Raspberry Pi Layout ist einfach, dass es viele Schnittstellen gibt die dem Raspi nicht entsprechen. z.B statt HDMI gibt es keinen "richtigen" Video Ausgang.
Die Powerbuchse ist eine Standard DC-Jack. Die 4 Taster für Next previous volume up down usw.
stören ein bisschen im Standard Raspi Layout. Desweiteren müsste man dann schon ein 4-Layer Board nehmen um ein Raspi Layout hinzubekommen. Dazu kommt noch das relativ große Wifi / Bluetooth Modul.
Im Vergleich zum Licheepi zero soll der Blueberrypi alle Interfaces herausführen und somit die volle Funktionalität des V3s bereitstellen.

Oben rechts in der Ecke ist noch relativ viel Platz, da hier noch 3 Step down Converter + ein linearer Regler hin muss.
Nachdem 6 April habe ich wieder richtig Zeit um aktiv an diesem Projekt zu arbeiten. Ich stecke momentan voll in der Klausurenphase.

Um euer kleines Ratespiel aufzulösen: Nein ich bin nicht aus der Schweiz, komme aus Deutschland. :D

tido-, 2018-03-20:
> z.B statt HDMI gibt es keinen "richtigen" Video Ausgang.

Was meinst du damit, kein HDMI ?

gc2035 - https://github.com/avafinger/gc2035

OV5640 - https://github.com/avafinger/ov5640

I have managed to build FFmpeg with Cedrus on Armbian and it seems working.
To grab video stream from the CMOS camera:
`sudo ./ffmpeg -f v4l2 -channel 0 -video_size 640x480 -i /dev/video0 -pix_fmt nv12 -r 30 -b:v 64k -c:v cedrus264 test.mp4`
https://forum.armbian.com/topic/1842-ffmpeg-with-cedrus-h264-hw-encoder-h3-cmos-camera/

Raspi Layout:

- Standard DC-Jack - ist ja auch sinnvoll
- Die 4 Taster für Next previous volume up down - braucht wahrscheinlich auch nicht jeder aber schön sind die da.
- Wifi / Bluetooth Modul - möchtest du noch eines integrieren, via USB? Welches?

Der Vorteil an dem Layout liegt auf der Hand, Gehäuse und anderes sind schon vorhanden und können bei Bedarf angepasst werden.

Dass du aus DE ist war mir bald klar, als ich deinen Link im Forum zu  de.Aliexpress sah :-)

petit-miner, 2018-03-21:
Bei dem Wlan / Bluetooth Modul habe ich an das RTL8723bs gedacht. Wird über den SDIO Bus angeschlossen + Uart Port.
Ich habe mir das ganze nochmal angesehen und vielleicht kann man ja auf die 3 USB Ports vom Raspi verzichten und dort dann die Taster und das Mikro unterbringen?
Ein 4 Layer Pcb kostest ja in China auch nicht mehr die Welt. Bei Jlc Pcb gibt es ein 4-Layer Pcb 10cm*10cm Leadfree und in Blau für 36€. Versand ist kostenlos.

Der V3s hat keinen HDMI Ausgang, man bräuchte einen extra IC um das zu realisieren.
Vor allem im Bereich der Kamera sind noch viele Fragen offen, z.B. fehlt im aktuellem Treiber die Möglichkeit einen Pin als Clock driver Pin zu definieren um die Kamera ans laufen zu bekommen.
Desweiteren fehlen hier und da Infos die einen in der Entwicklung stoppen.

tido-, 2018-03-23:
> RTL8723bs

Der V3s hat "Integrated an internal 10/100M PHY" sprich Netzwerk ist vorhanden, dann habe ich mir überlegt, wozu noch WiFi, warum nicht Zigbee?

> 3 USB Ports

Wolltest du das via USB-Hub lösen, ich sehe nur den USB-OTG?
Wenn USB nicht direkt am SoC angebunden ist, wird USB-Attached-SCSI nicht möglich sein. Na ja, 100Mbit vom Ethernet wären auch nur 6MB/s und das schafft fast jedes USB2.0 ohne UAS und die 5MP Kamera liefert wahrscheinlich auch nicht mehr. Es gibt auch einzelne aufrechtstehende USB-A Buchsen.

keinen HDMI Ausgang - dafür Support RGB interface with DE/SYNC mode, up to 1024x768@60fps

> 4-Layer Pcb 10cm*10cm Leadfree und in Blau für 36€.

Das wäre für 10 Stück, hat es keine SMD Komponenten, sonst braucht es noch die SMD-Stencil zum aufbringen der Lötpaste.
Ich frage mich gerade was die Produktion in Ostdeutschland kosten würde.

tido-, 2018-04-21:
Ging mit der Klausur alles gut?

Was hälst du davon..
> warum nicht Zigbee?

petit-miner, 2018-04-24:
Ich hoffe mal 😀
Der Schaltplan ist jetzt soweit fertig und es fehlen noch ein paar Sachen wie der DC DC Wandler und der Lipo Lade IC.

Problematisch wird es mit dem Platz auf der Platine. Der SoC vom Raspberry ist ebenhalt wesentlich kleiner als der V3s im TQFP. Zudem fehlt momentan der DC DC Wandler und alle dazugehörigen Bauteile. Vielleicht fällt mir noch was ein, wie ich dass ganze noch lösen kann.
Ich denke einen direkten Zigbee Sockel auf der Platine in den jetzigen Maßen wird nicht möglich sein.

Closed 2018-06-21.

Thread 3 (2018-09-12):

2-sides pcb + lvds + axp203

bhgv, 2018-09-12:
hi,

i did a fork of your blueberry pi, but added LVDS serialiser (SN65LVDS84) with the regular LVDS pin-header, TSC2003 - touch controller, w25q128 - flash, AXP203 power chip instead of EA3036.

https://github.com/bhgv/Blueberry-PI_Allwinner-V3s_LVDS_AXP203

and traced them as 2-sides PCBs.

https://github.com/bhgv/Blueberry-PI_Allwinner-V3s_LVDS_AXP203/tree/master/Hardware/PCB/routed

maybe you interested

petit-miner, 2018-09-13:
thank you

KaDw, 2018-12-19:
@bhgv Did you managed to get it up and running with AXP203?

bhgv, 2018-12-21:
@KaDw
> Did you managed to get it up and running with AXP203?
not yet. i'm playing now with a ea3036 one. only received PCBs and soldered it partly. too tight contacts on the ea3036 (and AXP203). i think using lm1117 will be better for this chip/board.

bhgv, 2018-12-21:
@KaDw
..and on my board wrong connection of the micro-usb. they are mirrored. use full size USB.

petit-miner, 2018-12-21:
@bhgv this issue is resolved with the new version of the PCB

ma6254, 2020-06-12:
@bhgv i cannot set the default output voltage
in the AXP203 datasheet：
> As for more details, please refer to “Default Configuration Instruction”.
Do you have this, can you post it?
Thx

Closed 2018-09-13.

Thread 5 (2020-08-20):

repository 'https://github.com/petit-miner/u-boot.git/' not found

ciprian288, 2020-08-20:
repository 'https://github.com/petit-miner/u-boot.git/' not found

Thore-Krug, 2020-10-09:
The V3s SOC is generally supported by Mainline Uboot by now i dont have a Board to test it but support can be tested relatively easily.

Thore-Krug, 2020-10-09:
You can use Mainline Uboot for the BlueberryPi with the `LicheePi_Zero_defconfig` and the `sunxi` defconfig for mainline Linux Kernel with the `sun8i-v3s-licheepi-zero.dtb` Devicetree according to http://linux-sunxi.org/Blueberry_PI

Closed 2021-03-14.

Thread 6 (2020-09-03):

Hardware Connections

eric-meehan, 2020-09-03:
Hello Marcel,

I am attempting to build a board very similar to the one you have detailed here - a linux-capable single board computer with wifi.  If you are willing, I would very much like to see a schematic for your device, as I am having difficulty making a connection between the WiFi module and the V3s.

How did you supply WiFi to the kernel?  Did you use SPI, SDIO, UART, or some other connection protocol?  Do you think it would be possible to add two WiFi modules?  If you used SDIO, the V3s seems to have multiple SDIO interfaces, so it seems feasible, though I have yet to make a connection with one. Within the OS, does the RTL8723BS appear as one of the WLAN interfaces, and would it be able to be controlled by wpa_supplicant?

I would also like to add additional RAM and storage to the device.  Did you consider doing this?

I have a number of questions on how you managed to build this board and would love to hear back from you!

Best,
Eric

petit-miner, 2020-09-06:
Hi Eric,
the RTL8723BS uses SDIO as main Interface. UART is only needed if you want to use Bluetooth.
The driver for the RTL8723BS is a staging driver, so it isn't in the kernel but in a kernel module.
You will need to activate the SDIO in the devicetree including the used pins. After startup you will need to load the kernel module and then the wifi module is usable as network interface. I have only tried this with one module on SDIO1 since SDIO0 is used by my SD Card. Additional RAM isn't possible since no adress / data bus is exposed. However you can easily expand the flash by adding a bigger SD card.
If you have further questions you can email me at my email adress mentioned in the readme.
Best,
Marcel

Closed 2021-03-14.

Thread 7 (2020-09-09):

Distributor for Allwinner V3S

NilsMinor, 2020-09-09:
Hello Blueberry Team,

First of all thanks for sharing your experience designing a RPI module alternative. I was looking for a distributor for Allwinner V3S SoC in Germnay / Europe. Maybe you can help me with a contact. Where did you buy the SoC ?

Thanks,
Nils

petit-miner, 2020-09-17:
Hallo Nils,
Für einzelne Prototypen habe ich den V3s auf Aliexpress gekauft. Für eine Serienproduktion hätte ich einen Kontakt zu einem Händler in China.

Gruß Marcel

NilsMinor, 2020-09-17:
Hi Marcel,

danke für dein Feedback :). Kannst du einen Kontakt zum Händler herstellen? Wir überlegen ein SoM zu bauen und sind noch auf der Suche nach einem günstigen Prozessor. Gerne kannst du mir auch eine Mail an nils@electronic-fellows.de schreiben.

Beste Grüße,
Nils

Closed 2020-09-25.

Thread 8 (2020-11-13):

Eagle libaries

Thore-Krug, 2020-11-13:
I took a look at the files and noted that for example the Allwinner V3s Libary is not available in this repo. I wanted to ask if you would be kind enough to provide that Libary.

Signed off by: Thore Krug opensource[at]thorekrug.de

Thore-Krug, 2020-11-13:
I noticed the required libary is provided in another Repository.

Signed off by Thore Krug opensource[at]thorekrug.de

Closed 2020-11-13.

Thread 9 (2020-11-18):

FEL Mode Pin

Thore-Krug, 2020-11-18:
I was interested in creating a Board based on the Allwinner V3s as well and was looking through the documentation of the V3s looking for the Pin initiating the FEL mode. Normally the Pin gets pulled down to Ground which initiates the FEL mode, even though the documentation mentions it briefly its not completely clear which pin on the package it is.

Have i overlooked it in the schematic? Or is the Blueberry Pi not making use of this feature?

Signed off by: Thore Krug opensource[at]thorekrug.de

petit-miner, 2020-11-19:
In the lichee pi zero schematics it seems like to be the SPI MISO (Master In Slave Out) Pin. However it makes sense since the Slave can't talk with the Master (V3s)

tomwimmenhove, 2022-02-20:
Simply shorting out the SPI Flash chip's output seems like a bad idea. The datasheet mentions a "BSP" pin in the boot-configuration flow chars, but this pin is not named anywere else (as in, not listed in the pinout of the chip)

petit-miner, 2022-02-21:
Yes, you should do it with a pulldown resistor. But the BSP Pin isn't really needed since the V3s prefers booting from an SD Card and you can also always enter FEL Mode through the uboot console.

Closed 2021-03-14.

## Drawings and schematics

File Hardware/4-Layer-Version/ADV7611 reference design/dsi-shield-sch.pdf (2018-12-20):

A

A

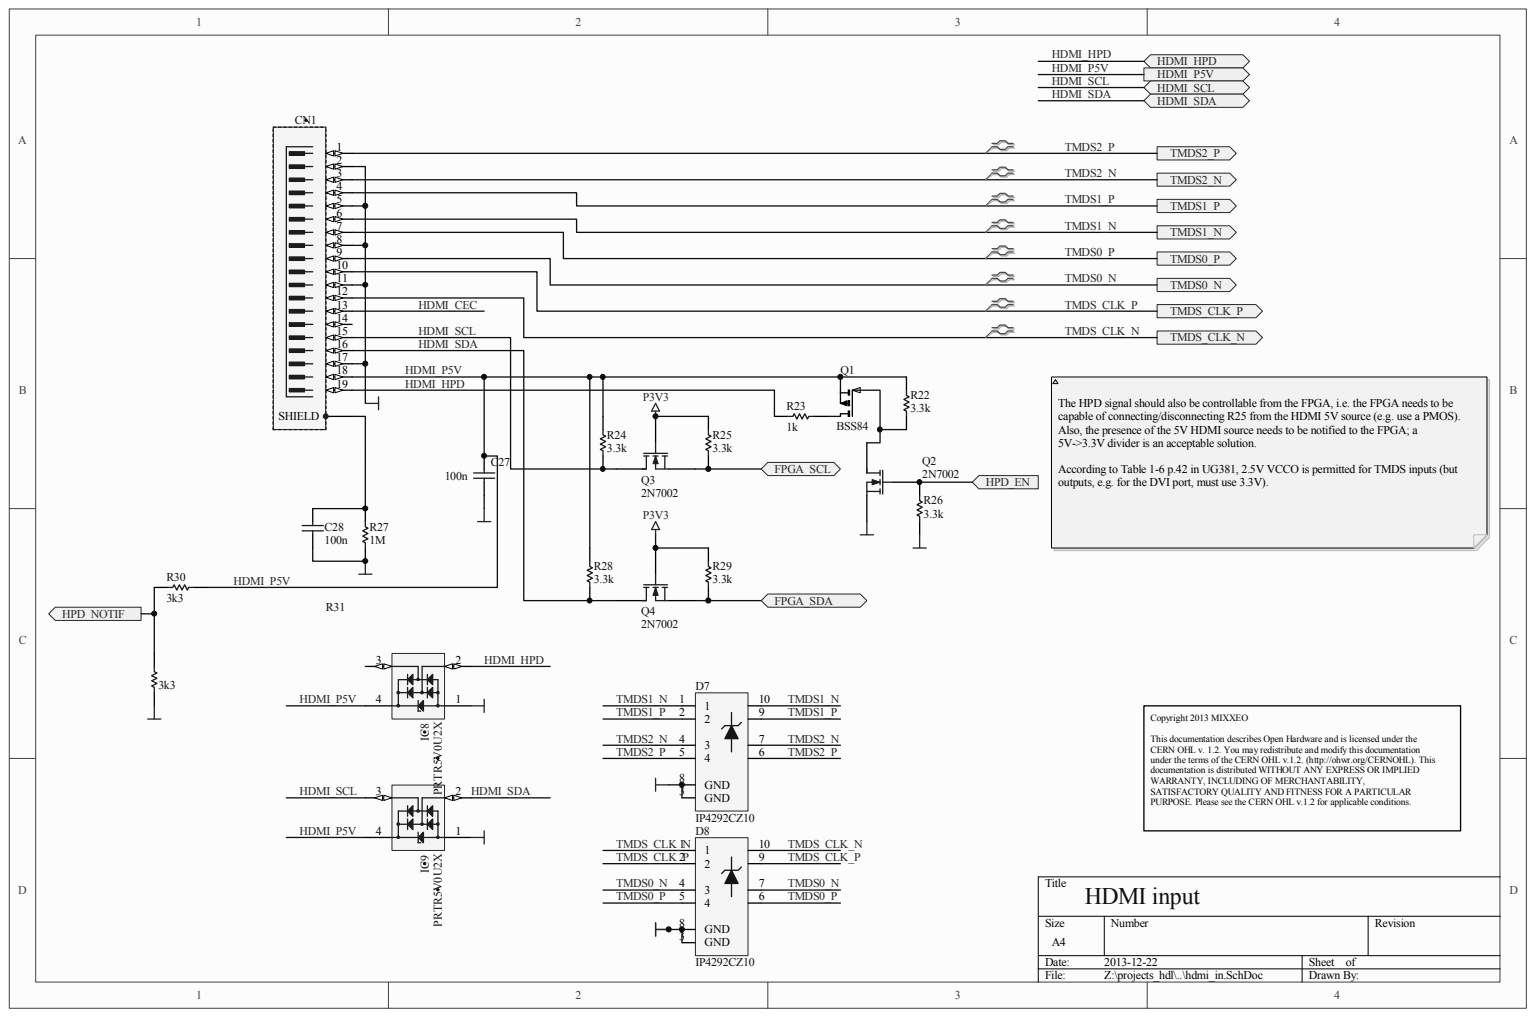
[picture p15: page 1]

The HPD signal should also be controllable from the FPGA, i.e. the FPGA needs to be
capable of connecting/disconnecting R25 from the HDMI 5V source (e.g. use a PMOS).
Also, the presence of the 5V HDMI source needs to be notified to the FPGA; a
5V->3.3V divider is an acceptable solution.

According to Table 1-6 p.42 in UG381, 2.5V VCCO is permitted for TMDS inputs (but
outputs, e.g. for the DVI port, must use 3.3V).

This documentation describes Open Hardware and is licensed under the
CERN OHL v. 1.2. You may redistribute and modify this documentation
under the terms of the CERN OHL v.1.2. (http://ohwr.org/CERNOHL). This
documentation is distributed WITHOUT ANY EXPRESS OR IMPLIED
WARRANTY, INCLUDING OF MERCHANTABILITY,
SATISFACTORY QUALITY AND FITNESS FOR A PARTICULAR
PURPOSE. Please see the CERN OHL v.1.2 for applicable conditions.

A | A

## SDRAM_A0

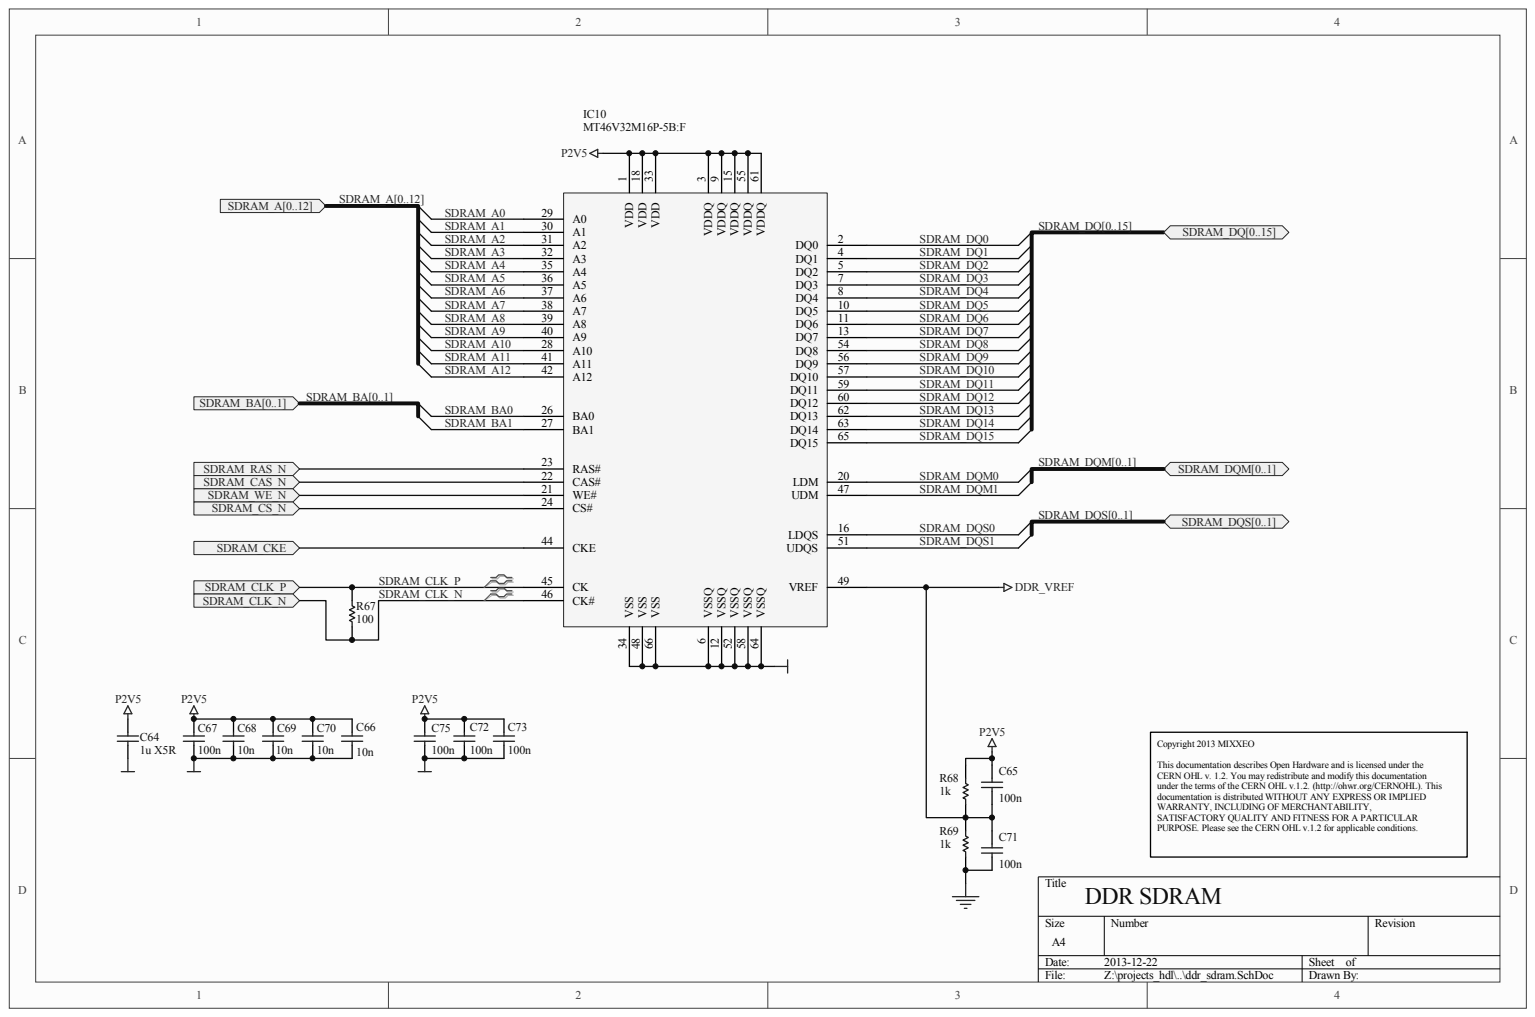
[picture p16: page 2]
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

A | A

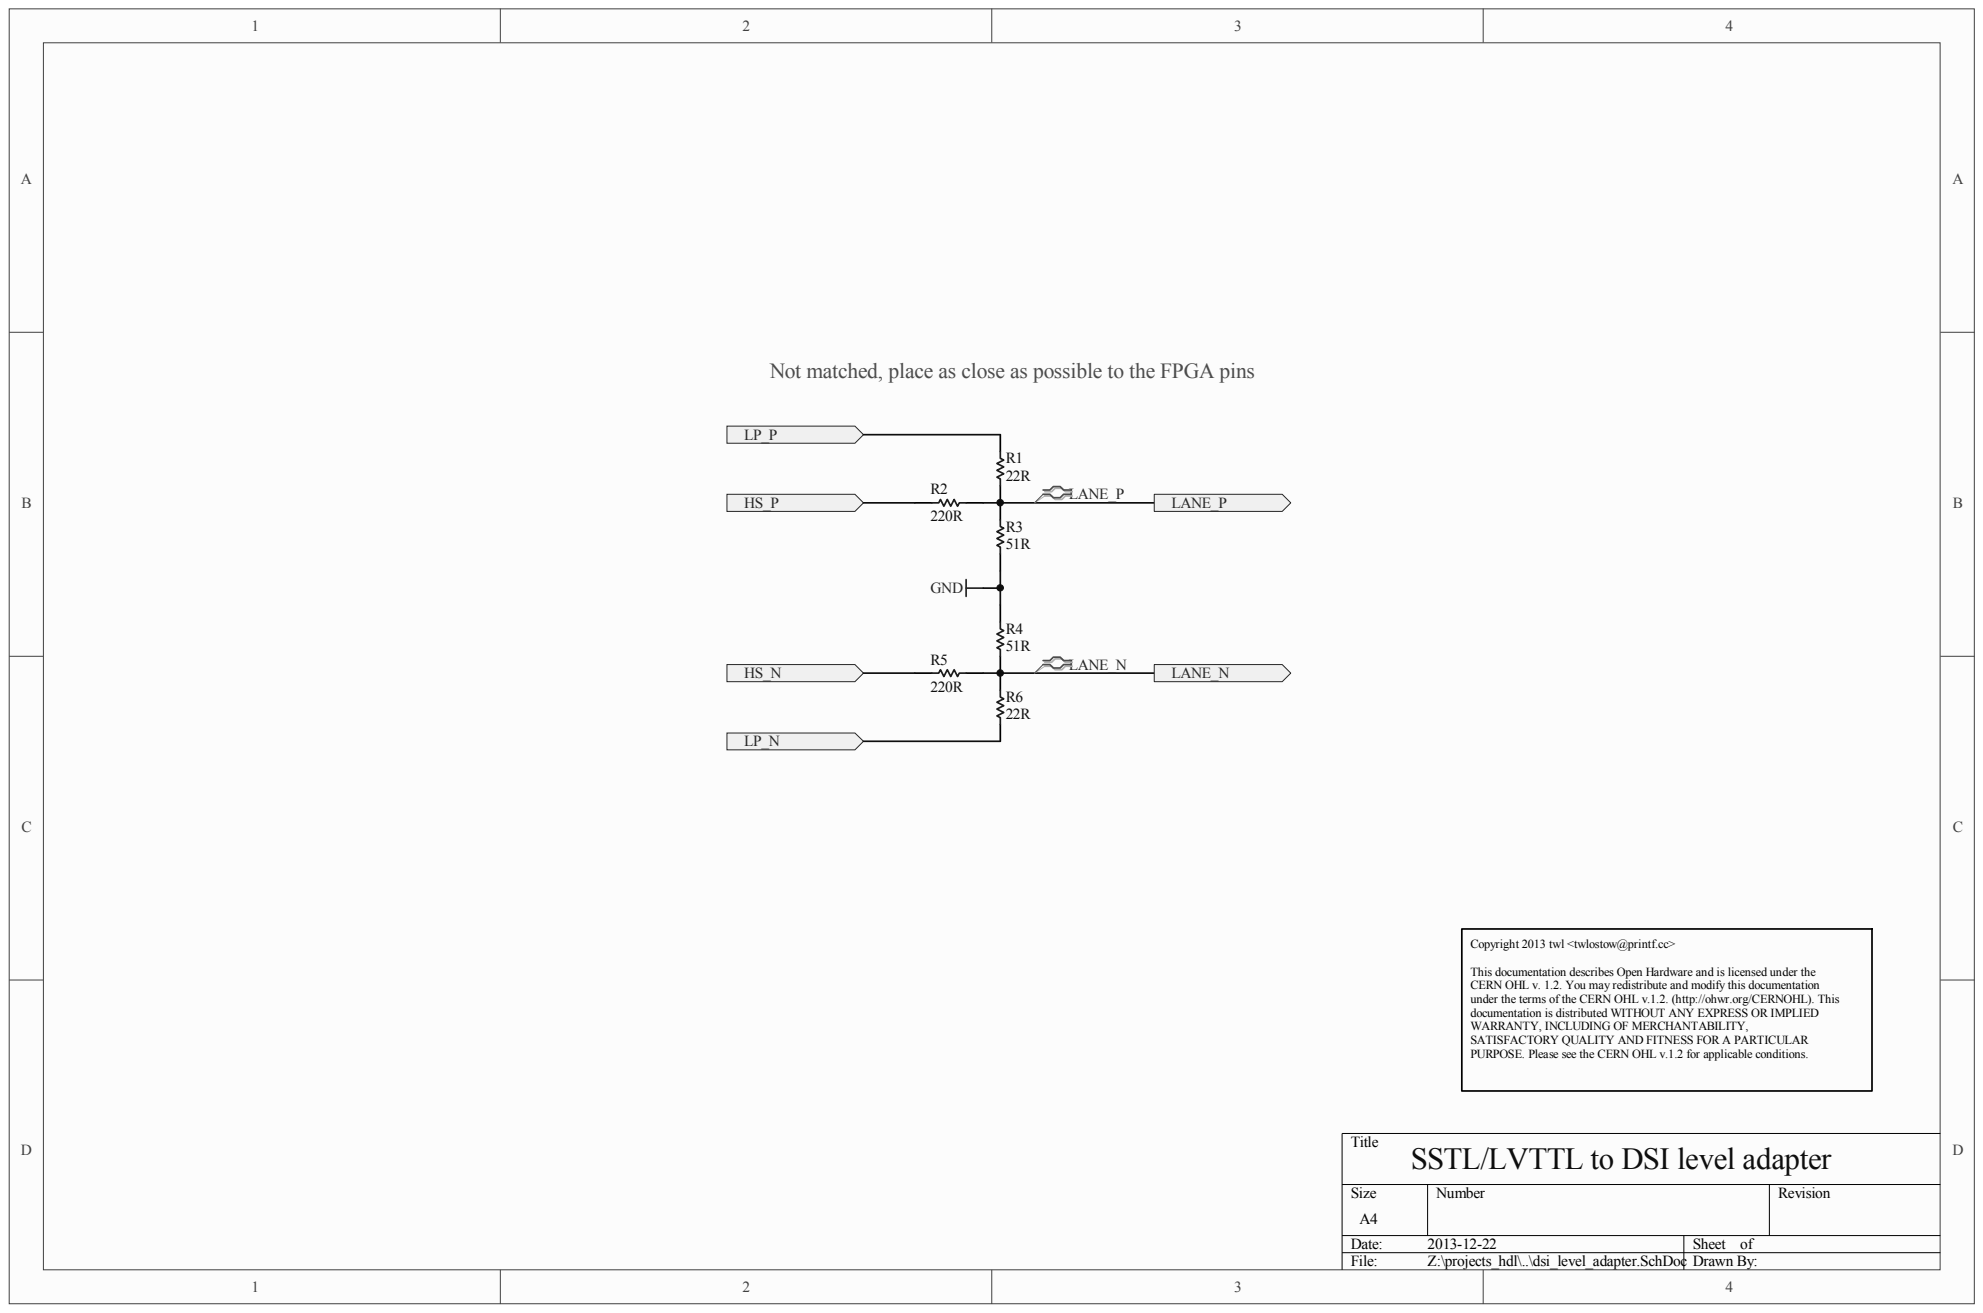
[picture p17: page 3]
Size; Number; Revision; File:; Z:\projects_hdl\..\dsi_level_adapter.SchDoc Drawn By:; GND; LANE_P; LANE_N

Not matched, place as close as possible to the FPGA pins

Copyright 2013 twl <twlostow@printf.cc>

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

Title
SSTL/LVTTL to DSI level adapter

JTAG & configuration flash | TMS

## Host interface

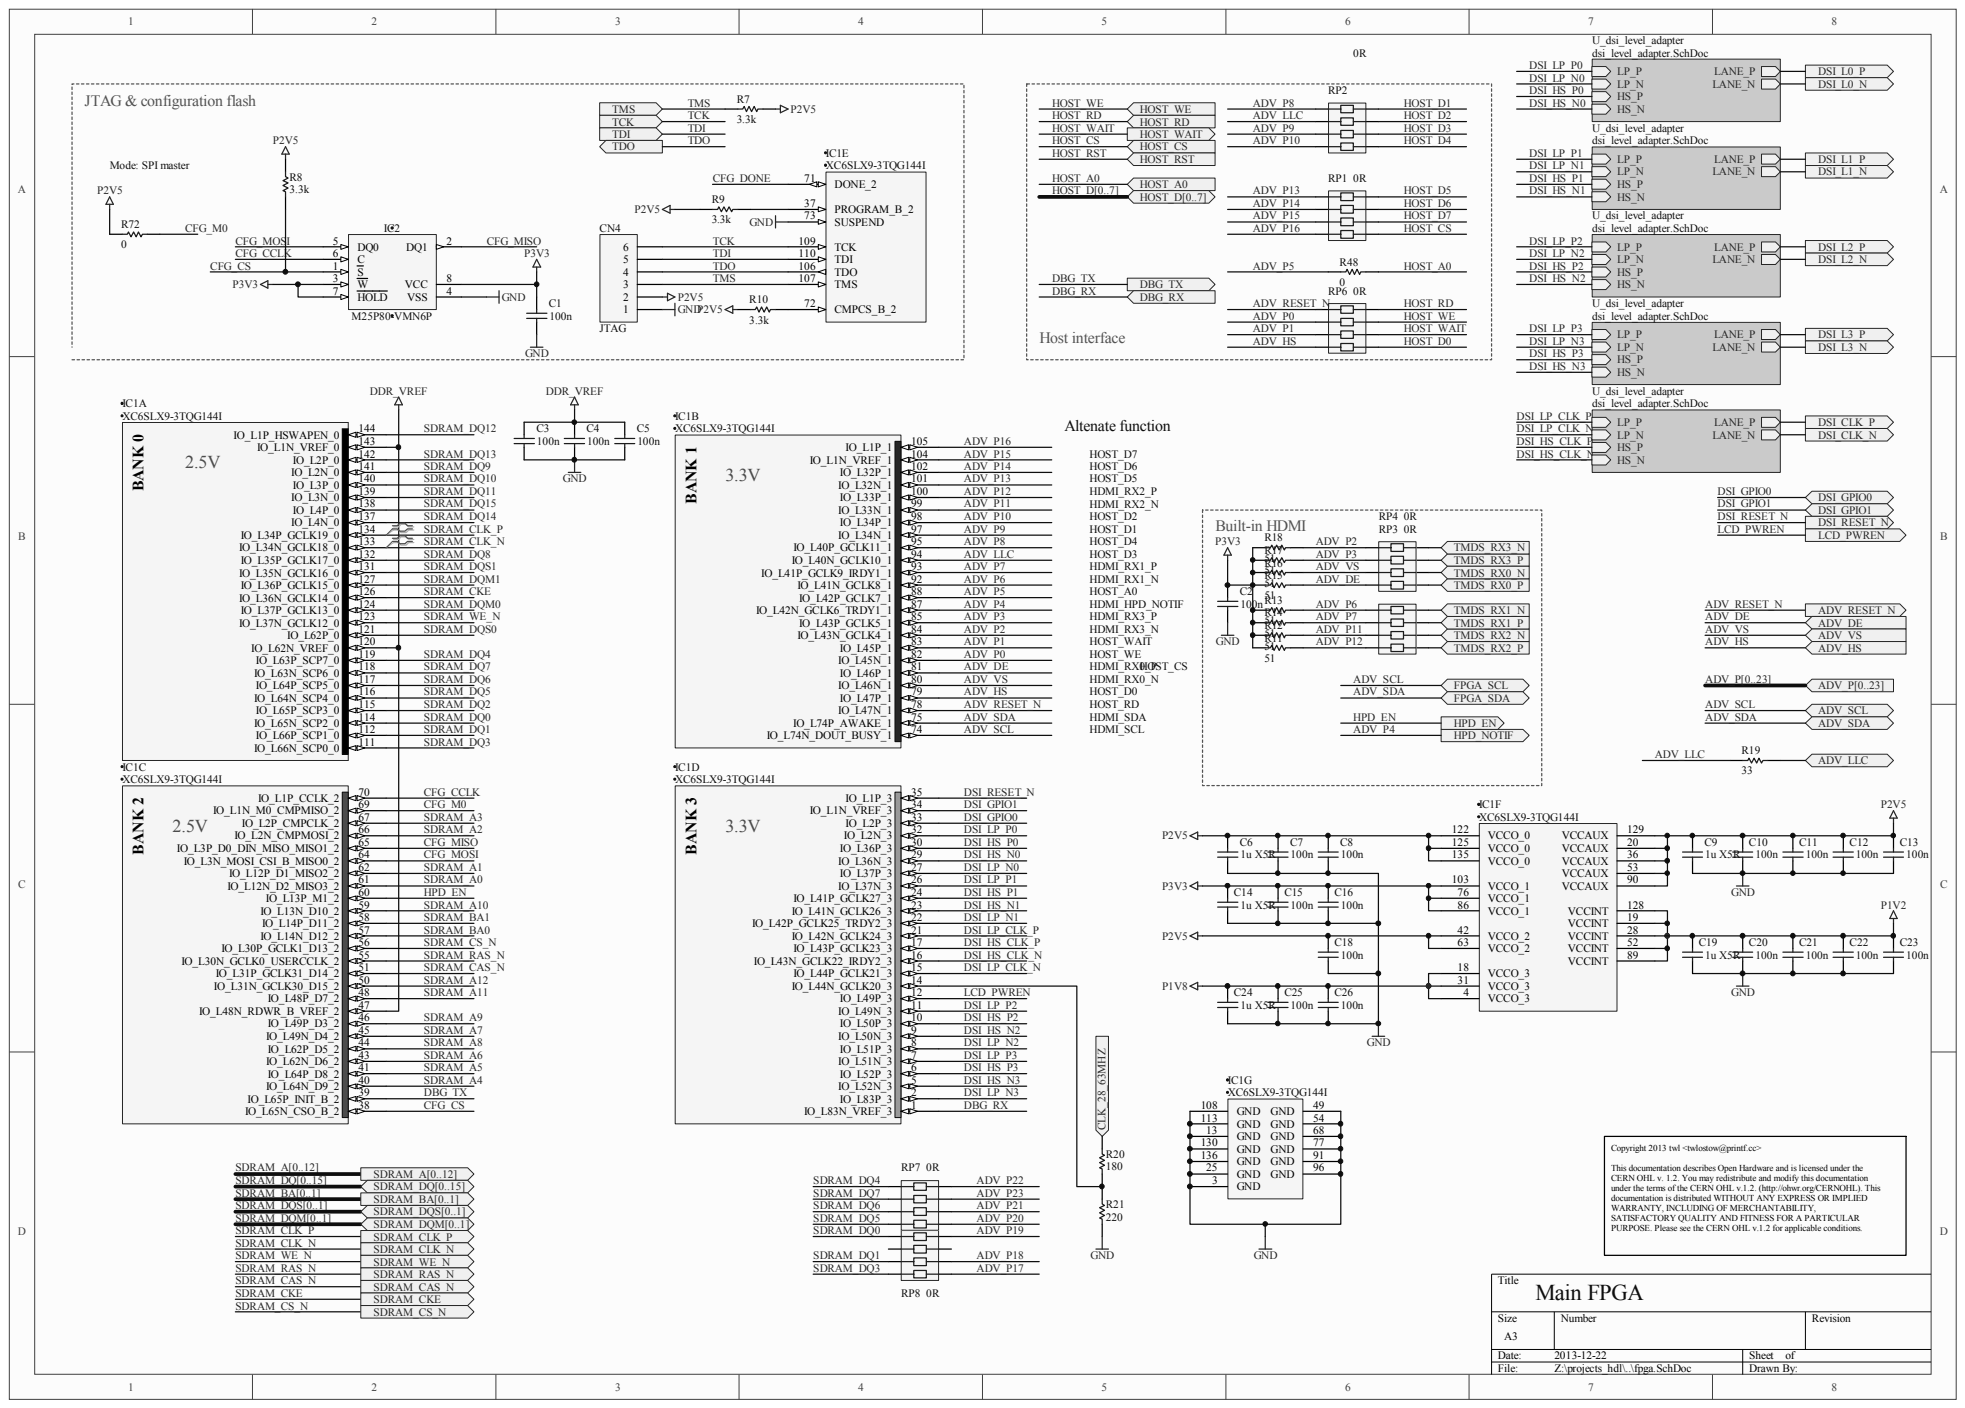
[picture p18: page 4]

Copyright 2013 twl <twlostow@printf.cc>

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

A

A

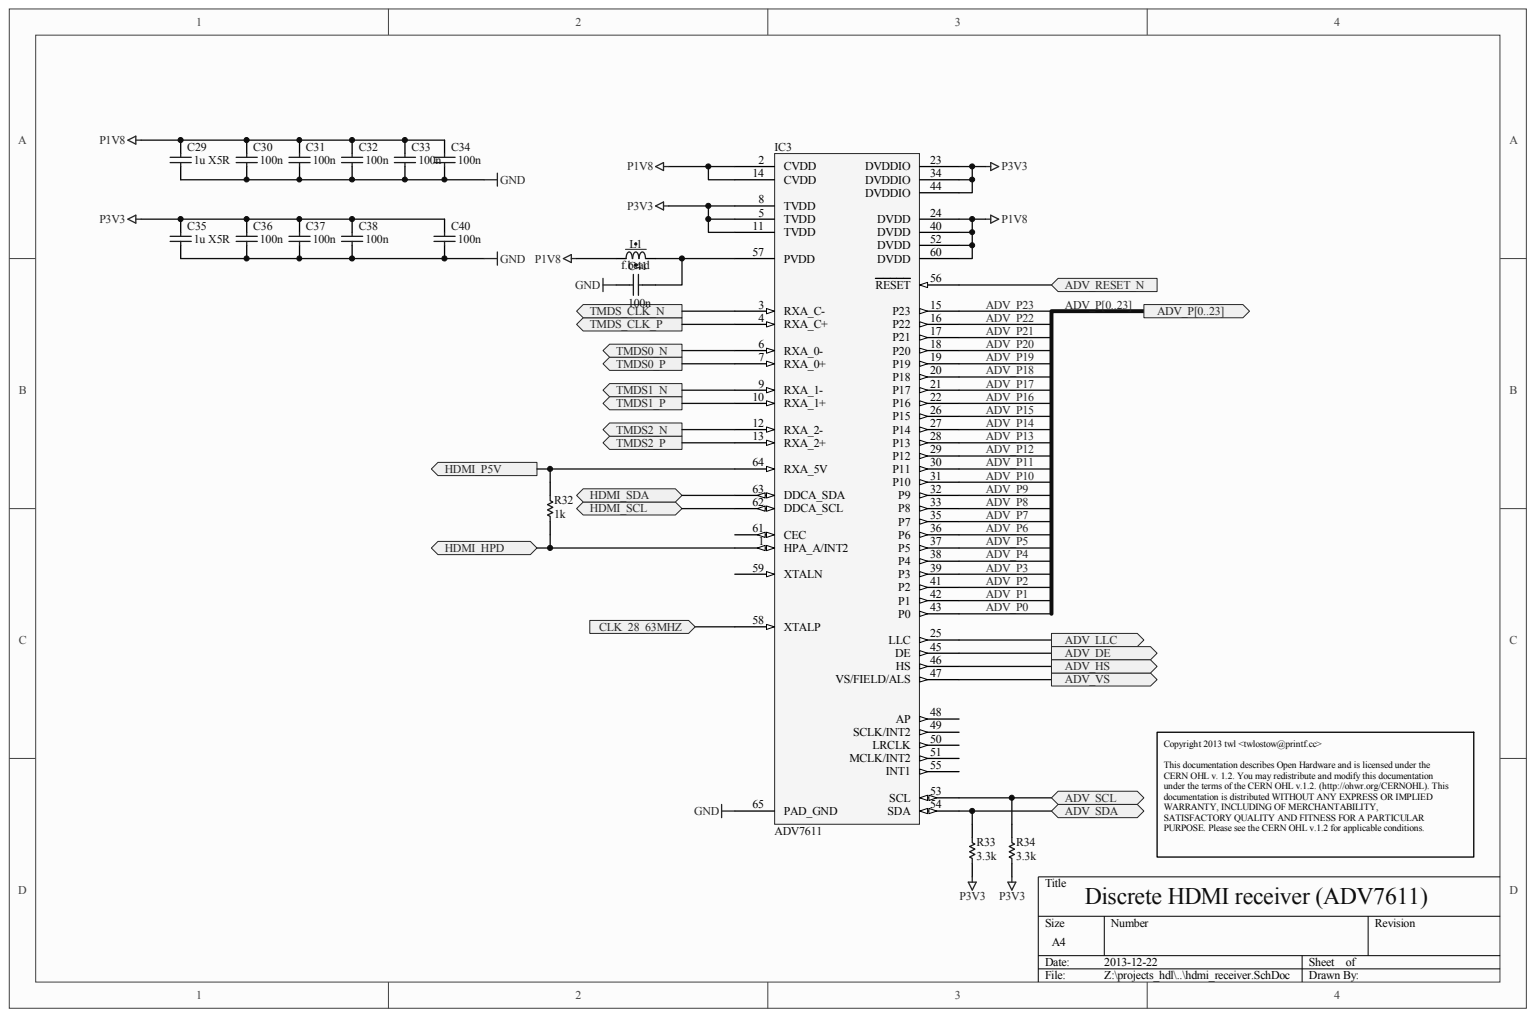
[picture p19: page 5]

Copyright 2013 twl <twlostow@printf.cc>

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

A

A

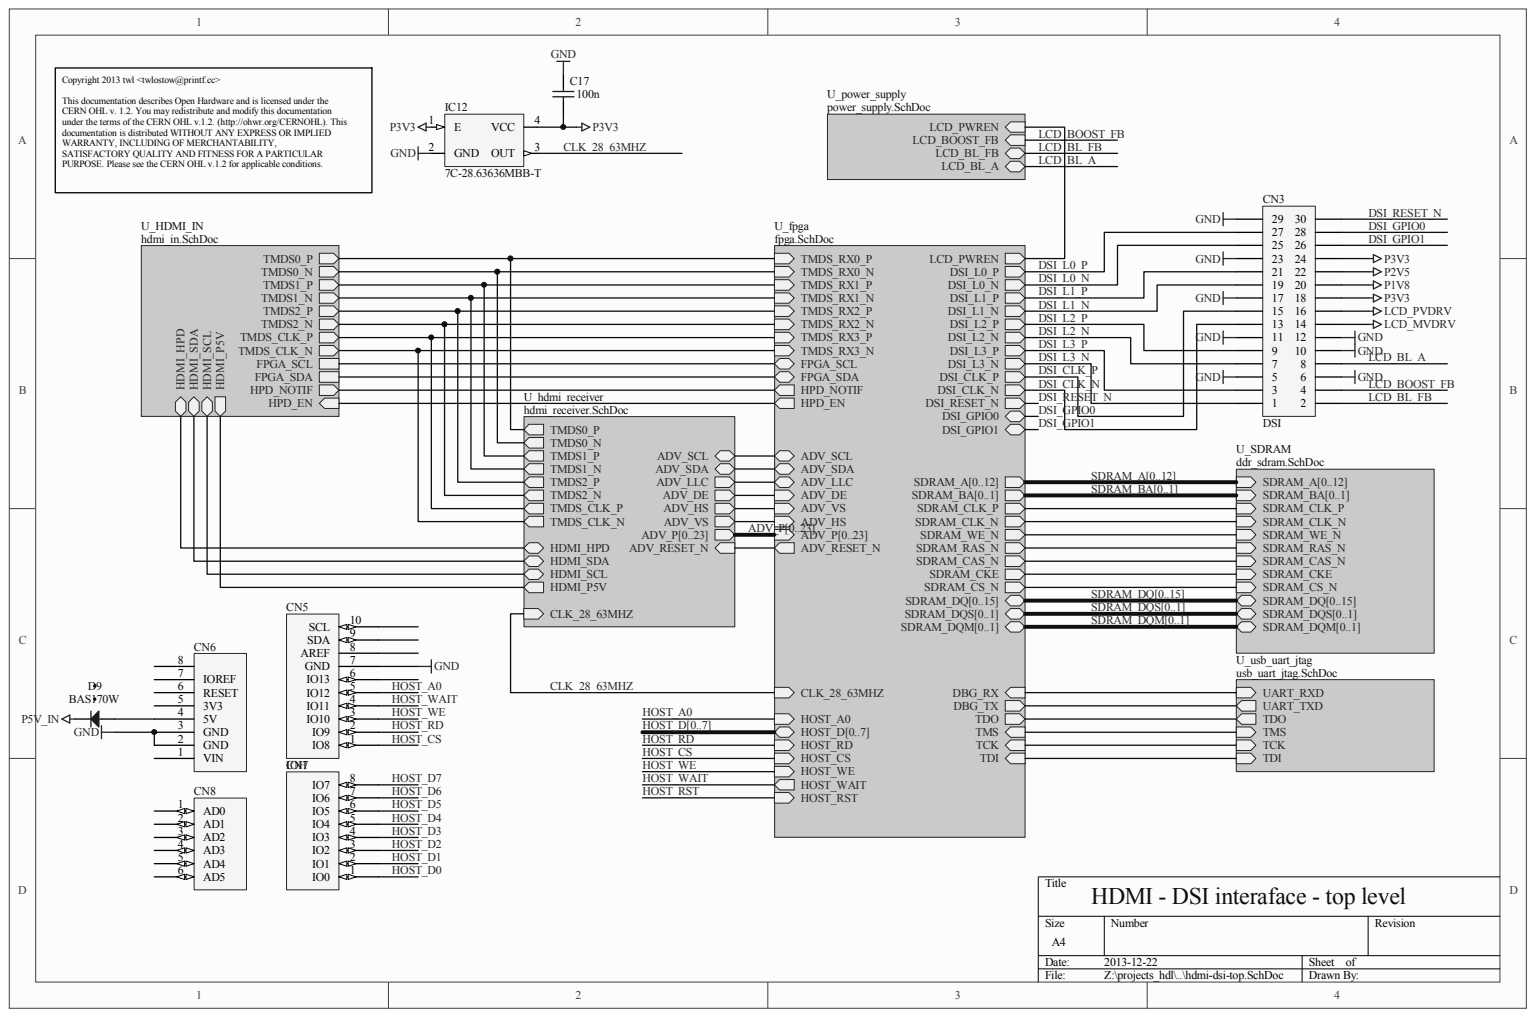
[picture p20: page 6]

Copyright 2013 twl <twlostow@printf.cc>

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

Title
HDMI - DSI interaface - top level

A | A
VINLDO12 1 | SYNC | 2

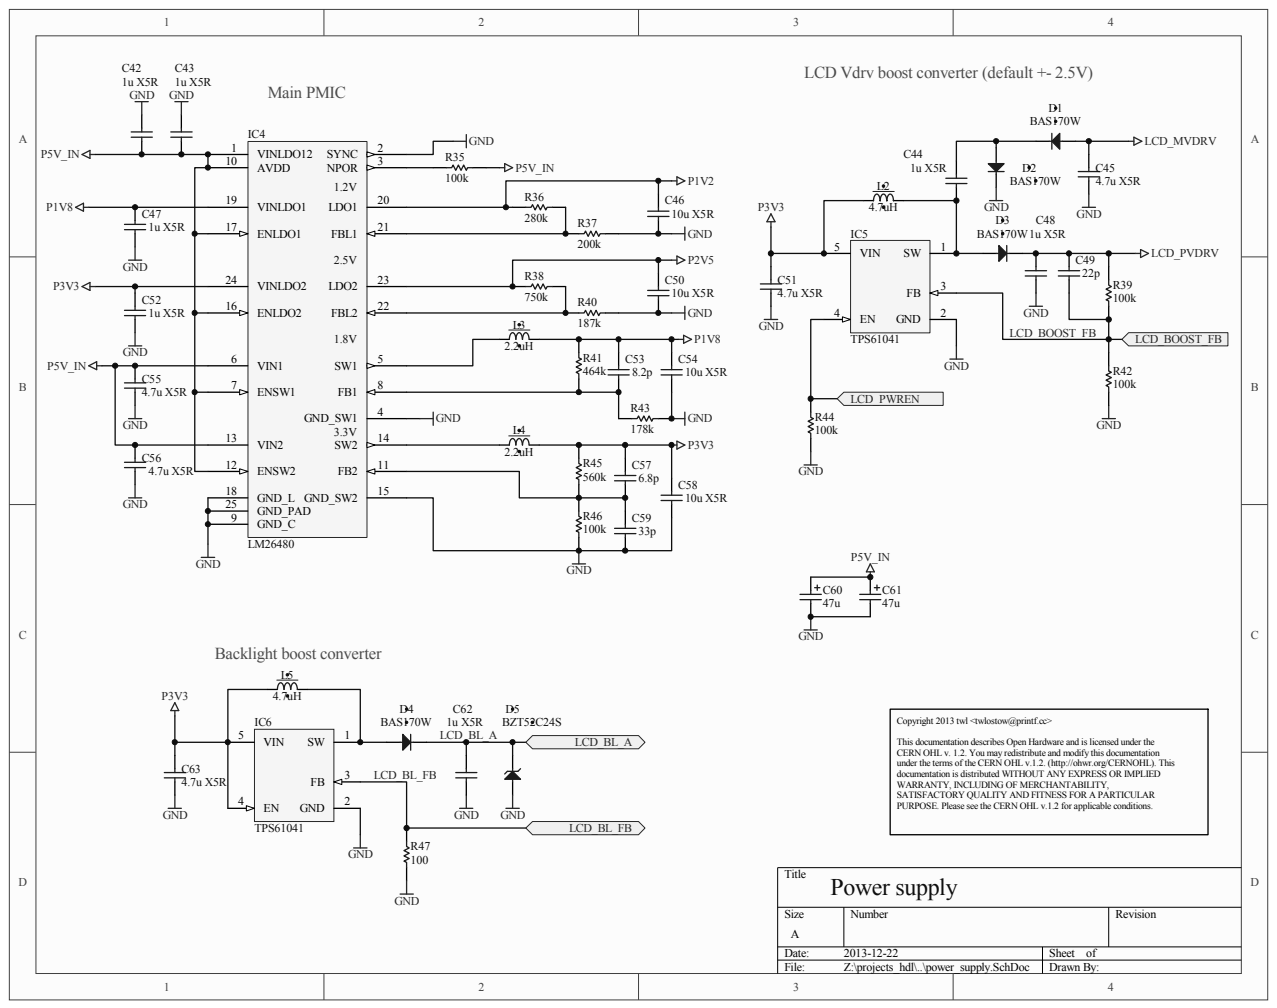
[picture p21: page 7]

LCD Vdrv boost converter (default +- 2.5V)

Copyright 2013 twl <twlostow@printf.cc>

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

A | A

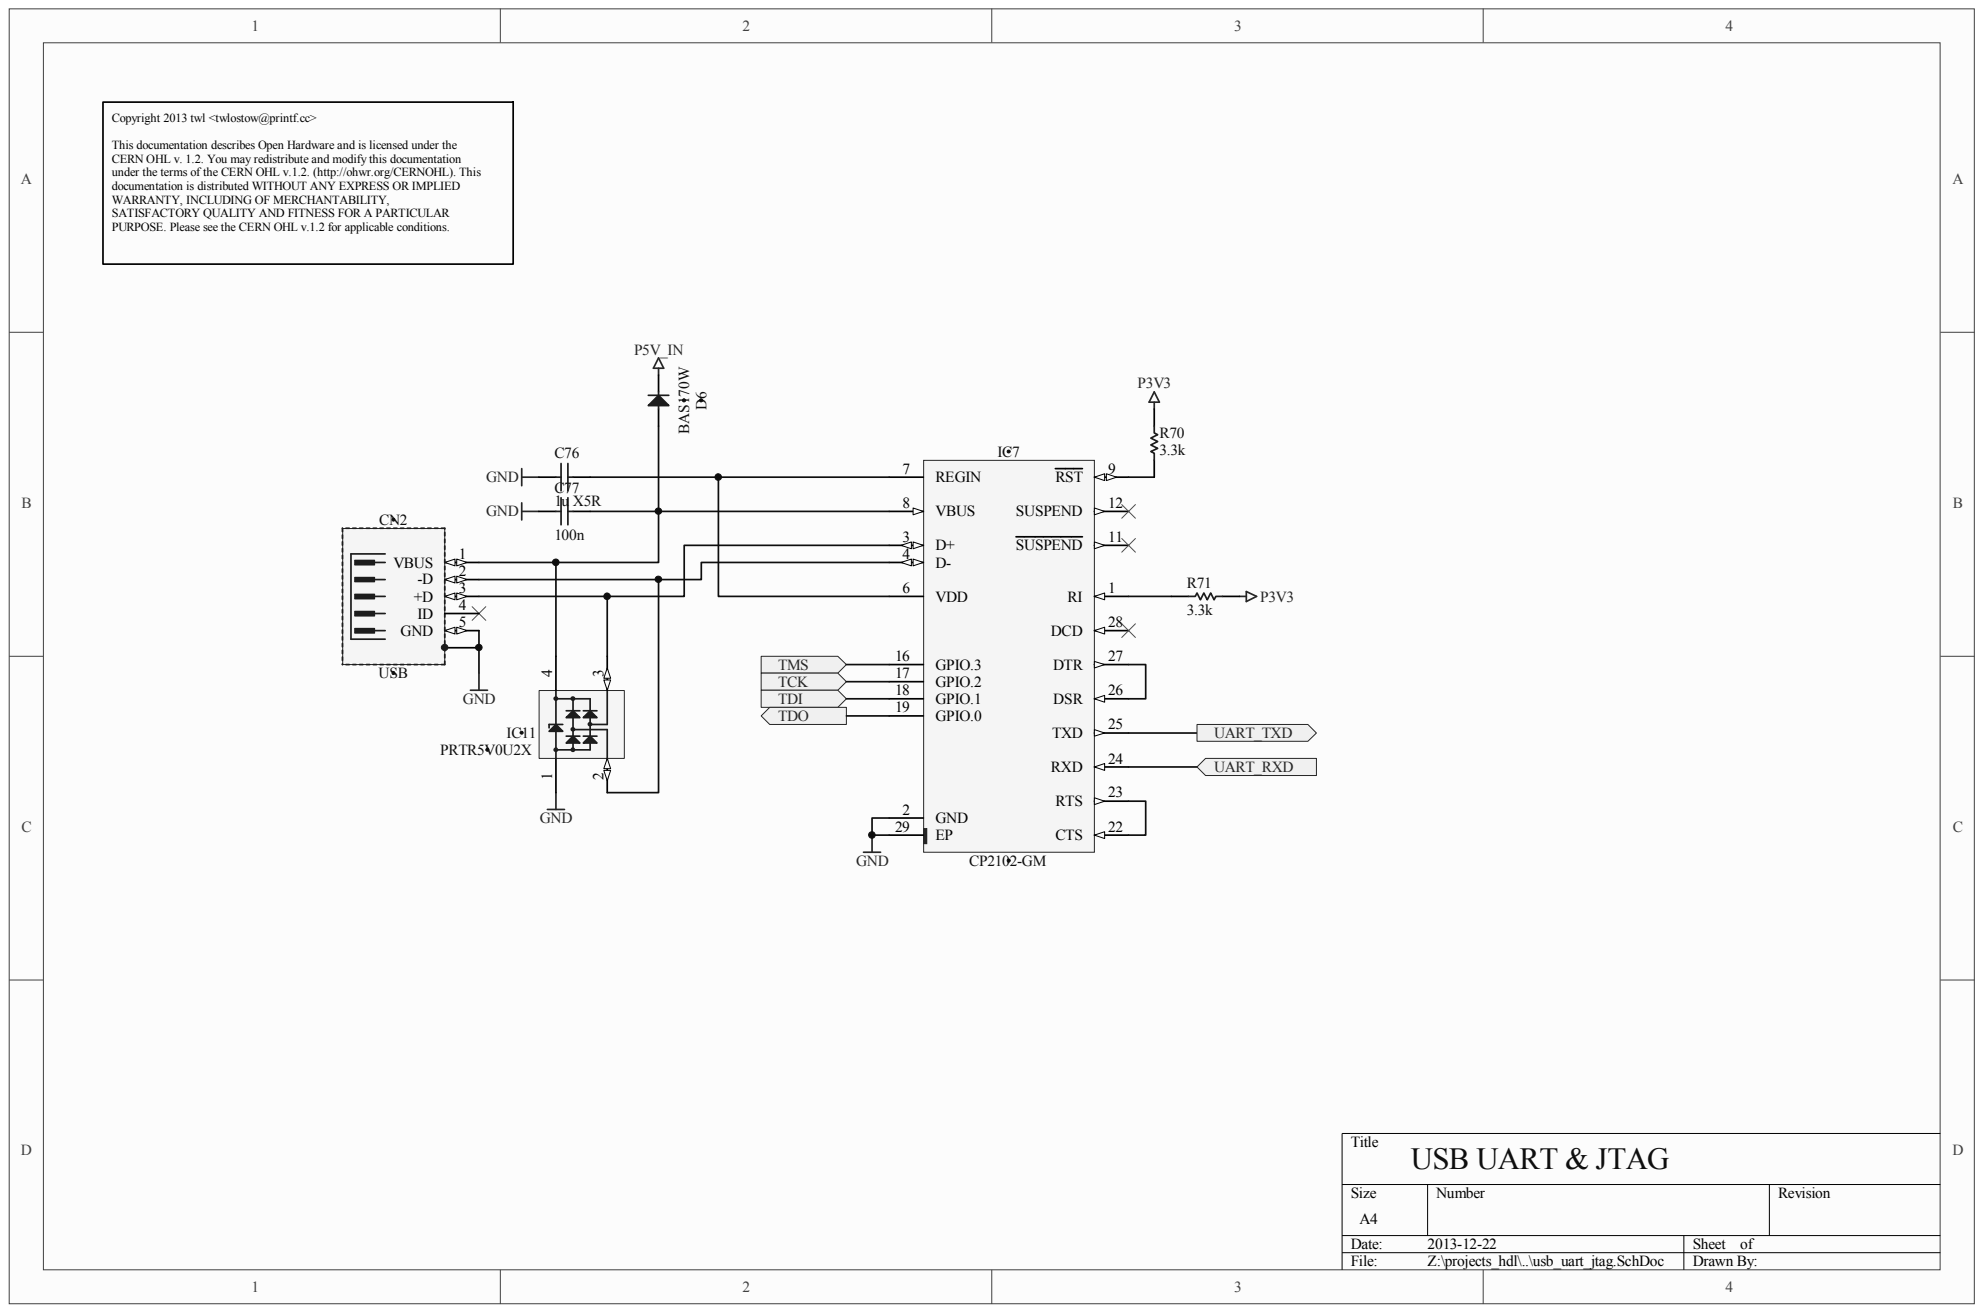
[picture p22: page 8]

Copyright 2013 twl <twlostow@printf.cc>
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

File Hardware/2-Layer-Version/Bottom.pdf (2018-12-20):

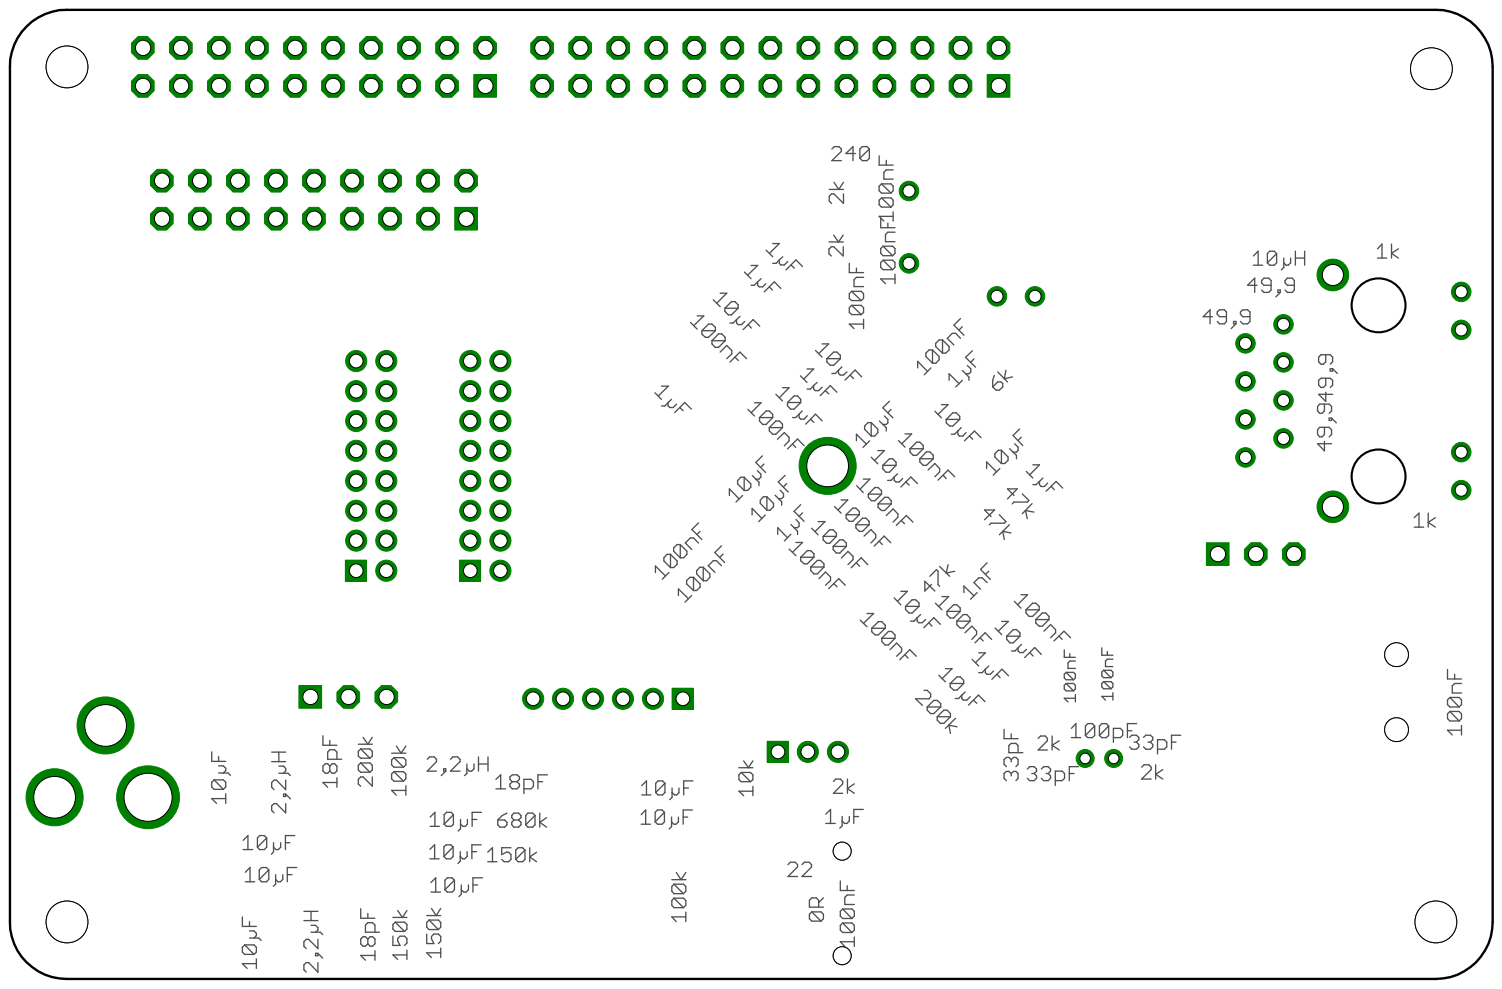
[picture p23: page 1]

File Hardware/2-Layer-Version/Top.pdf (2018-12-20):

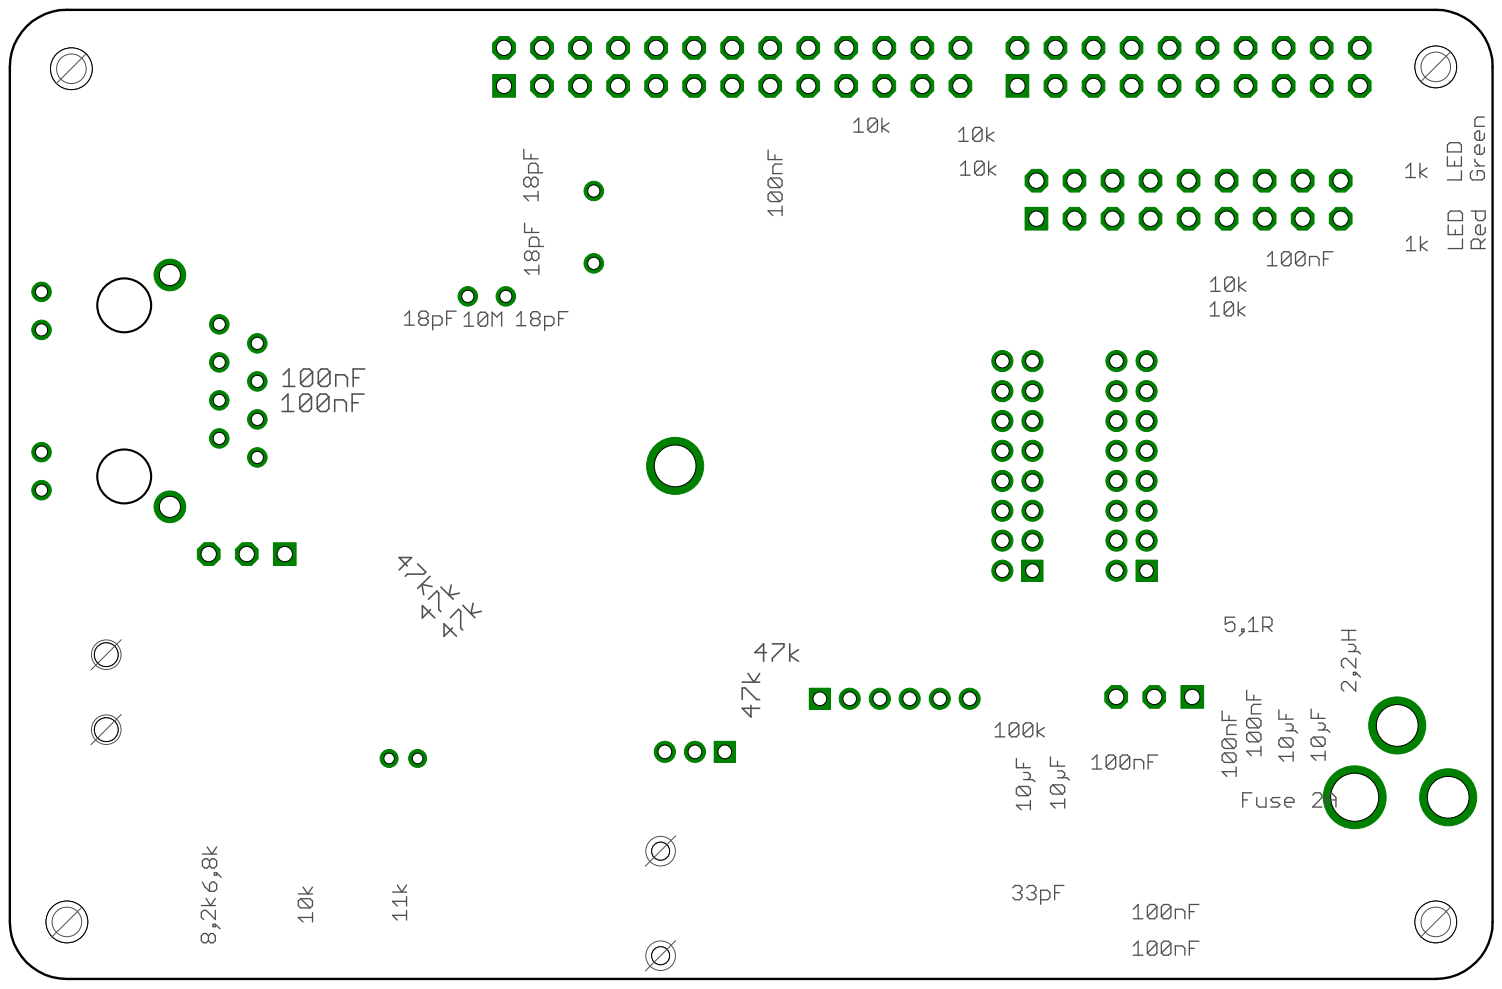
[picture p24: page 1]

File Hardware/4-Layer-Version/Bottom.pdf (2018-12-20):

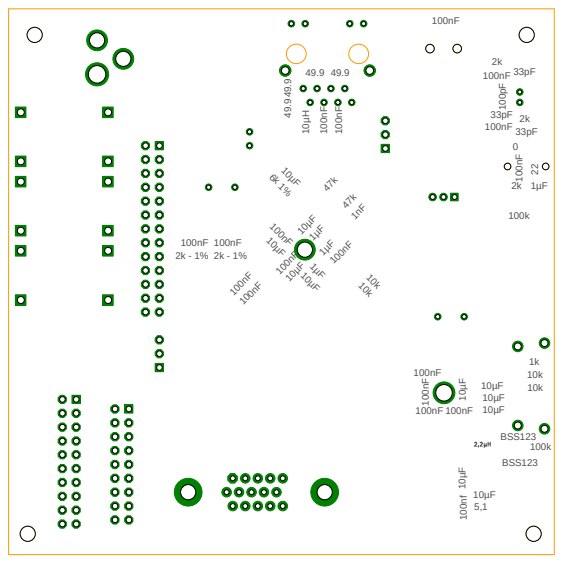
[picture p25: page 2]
1µF ¹⁰⁰nF; 10µF ¹⁰µF 100nf; BSS123; 10µF ¹⁰⁰nF

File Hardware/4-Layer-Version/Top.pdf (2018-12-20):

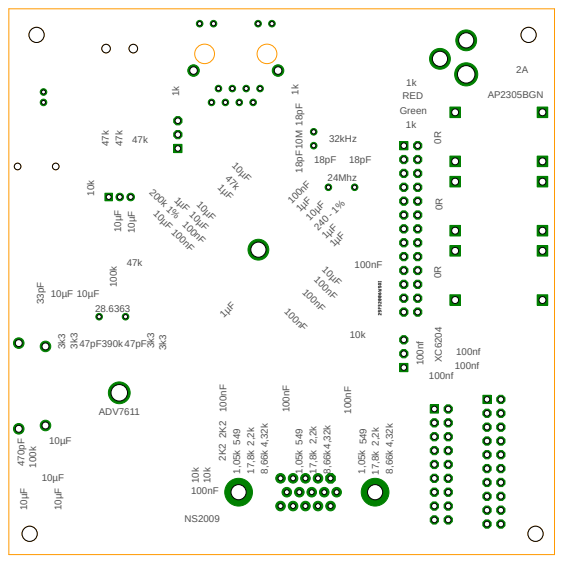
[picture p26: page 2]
RED Green; 100nF ¹⁸pF; 24Mhz; 32kHz 47k; 10k ¹⁰⁰k; XC⁶²⁰⁴; AP2305BGN; NS2009 ¹⁰⁰nF; 1,05k 549 2,2k 1,05k 549 2K² ²K²; ADV7611

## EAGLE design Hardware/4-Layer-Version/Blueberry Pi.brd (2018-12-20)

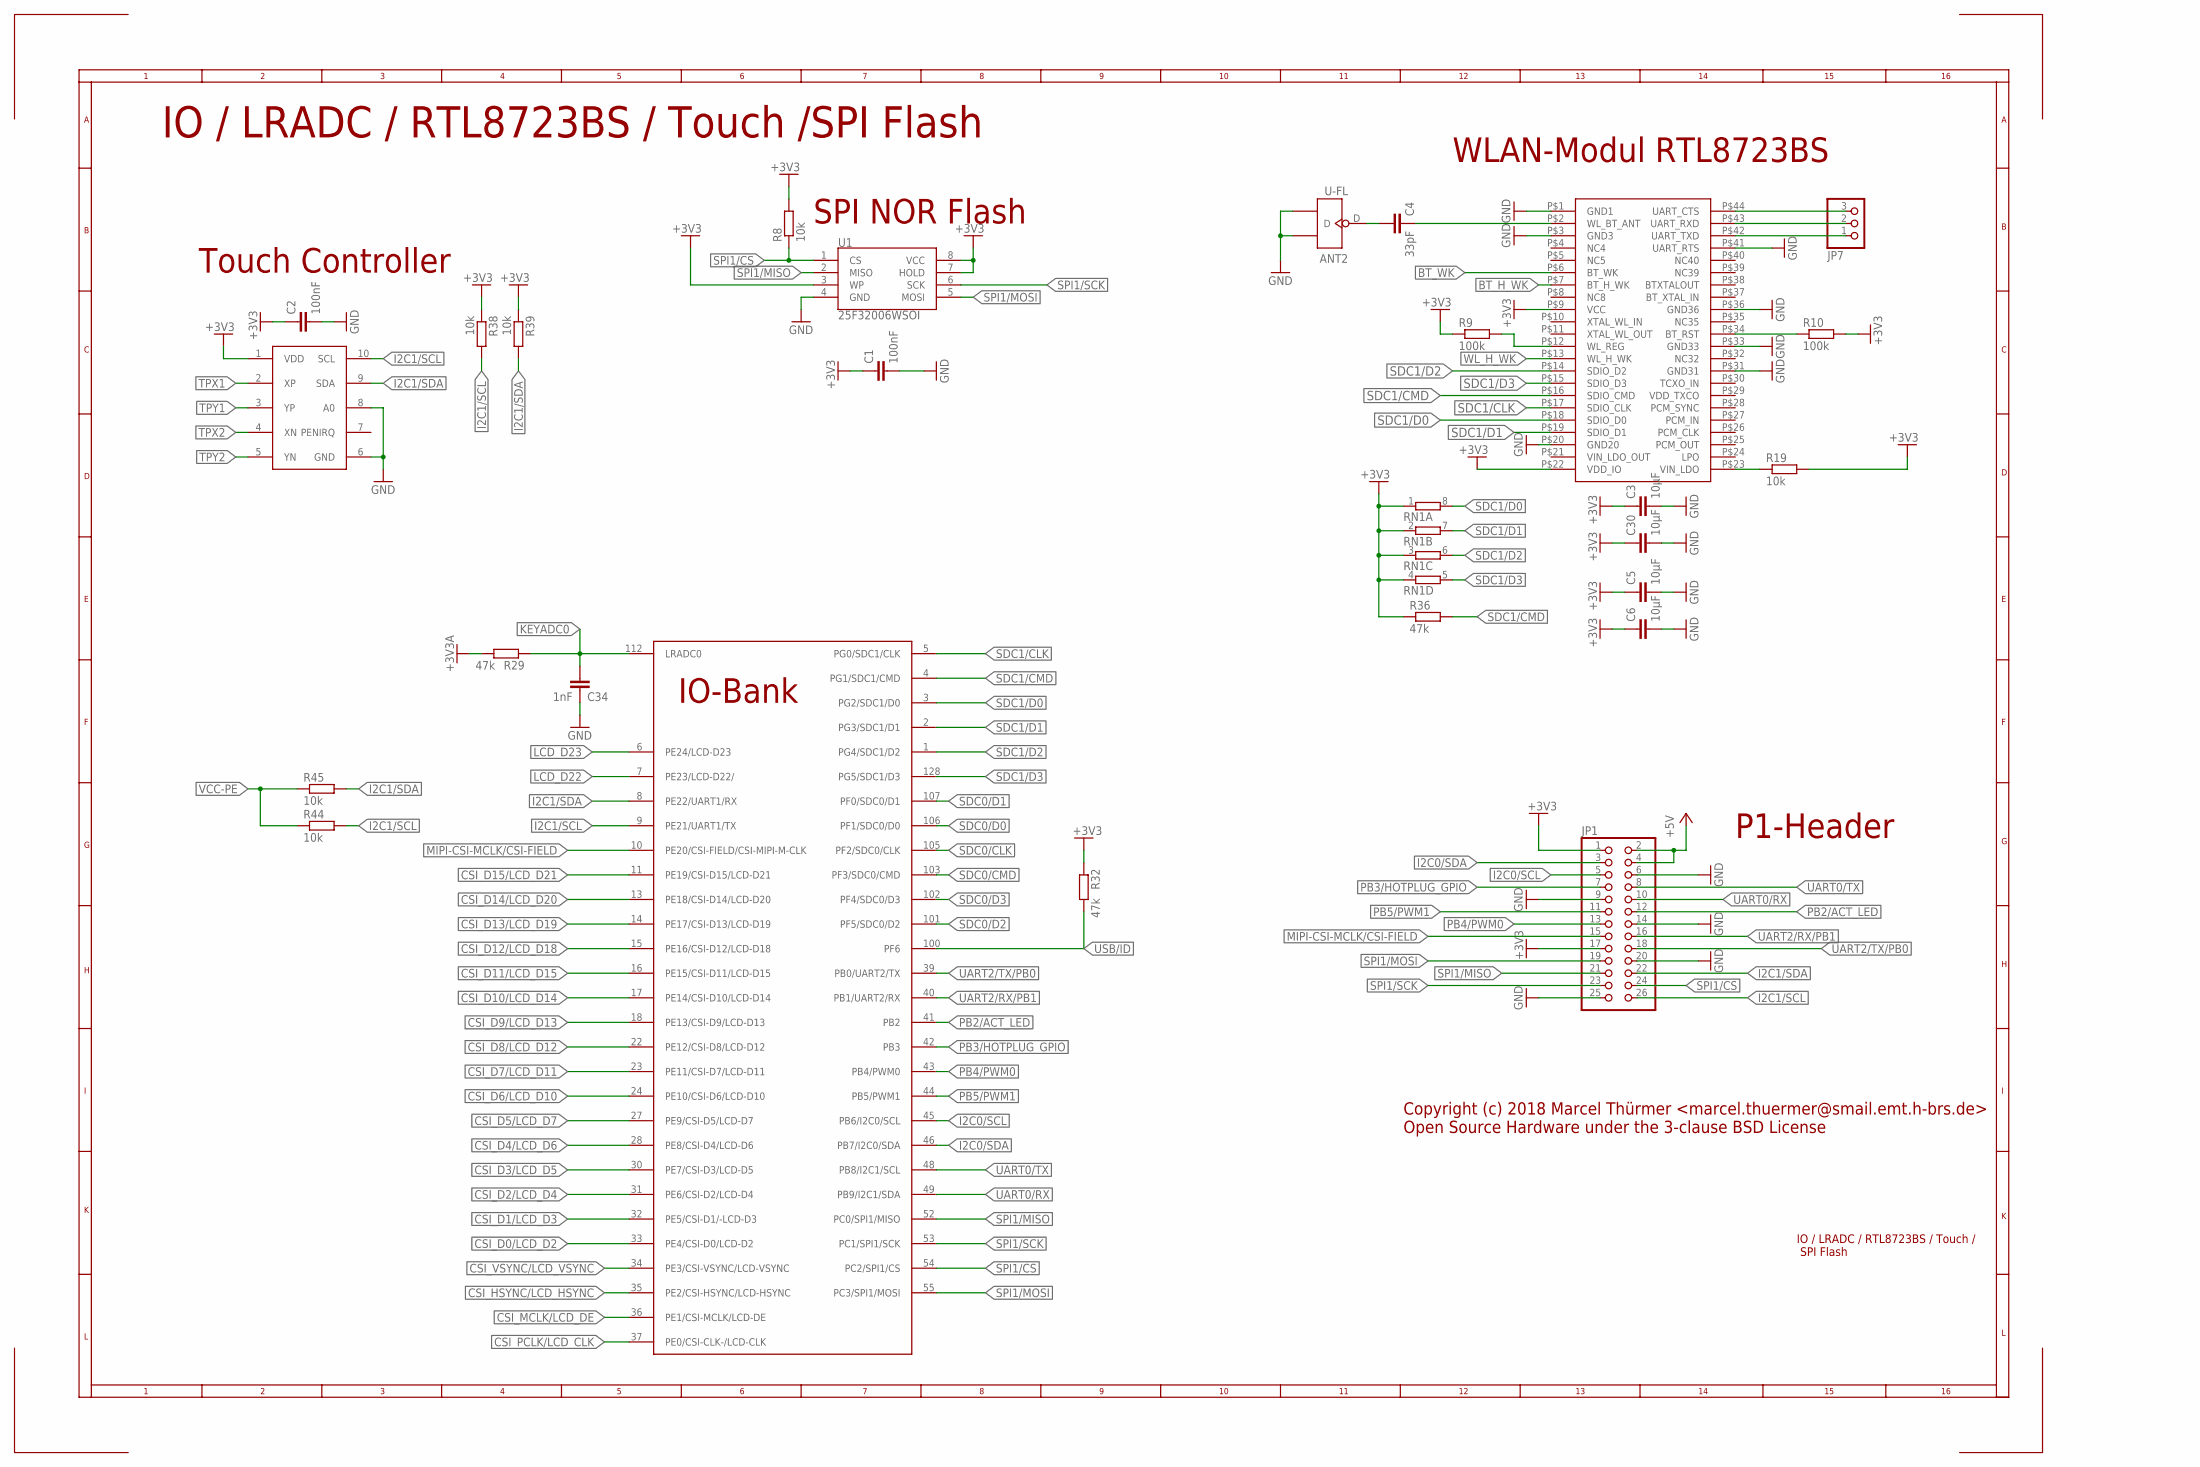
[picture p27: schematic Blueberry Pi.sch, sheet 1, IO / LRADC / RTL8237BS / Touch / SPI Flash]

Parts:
ANT2: U-FL; U-FL3P-SMD-2.6X2.6X1.0MM
C1, C2: 100nF; C0603
C3, C5, C6, C30: 10µF; C0805
C4: 33pF; C0603
C34: 1nF; C0603
JP1: PINHD-2X13; 2X13
JP7: PINHD-1X3M; 1X03M
R8, R19, R38, R39, R44, R45: 10k; R0603
R9, R10: 100k; R0603
R29, R32, R36: 47k; R0603
RN1: 4R-NEXB38V; EXB38V
U1: 25F32006WSOI; SO08-EIAJ
U$1: V3S; QFP-128
U$2: RTL8723BS; LGA
U$8: NS2009; MSOP10

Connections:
+3V3: C1.1, C2.1, C3.1, C5.1, C6.1, C30.1, JP1.1, JP1.17, R8.2, R9.1, R10.2, R19.2, R32.1, R36.1, R38.1, R39.1, RN1.1, RN1.2 (1), RN1.3 (1), RN1.4 (1), U1.3 (WP), U1.7 (HOLD), U1.8 (VCC), U$2.P$9 (VCC), U$2.P$22 (VDD_IO), U$8.1 (VDD); also elsewhere on the board
+3V3A: R29.2; also elsewhere on the board
+5V: JP1.2, JP1.4; also elsewhere on the board
BT_H_WK: U$2.P$7 (BT_H_WK)
BT_WK: U$2.P$6 (BT_WK)
CSI_D0/LCD_D2: U$1.33 (PE4/CSI-D0/LCD-D2); also elsewhere on the board
CSI_D1/LCD_D3: U$1.32 (PE5/CSI-D1/-LCD-D3); also elsewhere on the board
CSI_D2/LCD_D4: U$1.31 (PE6/CSI-D2/LCD-D4); also elsewhere on the board
CSI_D3/LCD_D5: U$1.30 (PE7/CSI-D3/LCD-D5); also elsewhere on the board
CSI_D4/LCD_D6: U$1.28 (PE8/CSI-D4/LCD-D6); also elsewhere on the board
CSI_D5/LCD_D7: U$1.27 (PE9/CSI-D5/LCD-D7); also elsewhere on the board
CSI_D6/LCD_D10: U$1.24 (PE10/CSI-D6/LCD-D10); also elsewhere on the board
CSI_D7/LCD_D11: U$1.23 (PE11/CSI-D7/LCD-D11); also elsewhere on the board
CSI_D8/LCD_D12: U$1.22 (PE12/CSI-D8/LCD-D12); also elsewhere on the board
CSI_D9/LCD_D13: U$1.18 (PE13/CSI-D9/LCD-D13); also elsewhere on the board
CSI_D10/LCD_D14: U$1.17 (PE14/CSI-D10/LCD-D14); also elsewhere on the board
CSI_D11/LCD_D15: U$1.16 (PE15/CSI-D11/LCD-D15); also elsewhere on the board
CSI_D12/LCD_D18: U$1.15 (PE16/CSI-D12/LCD-D18); also elsewhere on the board
CSI_D13/LCD_D19: U$1.14 (PE17/CSI-D13/LCD-D19); also elsewhere on the board
CSI_D14/LCD_D20: U$1.13 (PE18/CSI-D14/LCD-D20); also elsewhere on the board
CSI_D15/LCD_D21: U$1.11 (PE19/CSI-D15/LCD-D21); also elsewhere on the board
CSI_HSYNC/LCD_HSYNC: U$1.35 (PE2/CSI-HSYNC/LCD-HSYNC); also elsewhere on the board
CSI_MCLK/LCD_DE: U$1.36 (PE1/CSI-MCLK/LCD-DE); also elsewhere on the board
CSI_PCLK/LCD_CLK: U$1.37 (PE0/CSI-CLK-/LCD-CLK); also elsewhere on the board
CSI_VSYNC/LCD_VSYNC: U$1.34 (PE3/CSI-VSYNC/LCD-VSYNC); also elsewhere on the board
GND: ANT2.GND1, ANT2.GND2, C1.2, C2.2, C3.2, C5.2, C6.2, C30.2, C34.1, JP1.6, JP1.9, JP1.14, JP1.20, JP1.25, U1.4 (GND), U$2.P$1 (GND1), U$2.P$3 (GND3), U$2.P$20 (GND20), U$2.P$31 (GND31), U$2.P$33 (GND33), U$2.P$36 (GND36), U$2.P$41 (UART_RTS), U$8.6 (GND), U$8.8 (A0); also elsewhere on the board
I2C0/SCL: JP1.5, U$1.45 (PB6/I2C0/SCL)
I2C0/SDA: JP1.3, U$1.46 (PB7/I2C0/SDA)
I2C1/SCL: JP1.26, R38.2, R44.2, U$1.9 (PE21/UART1/TX), U$8.10 (SCL); also elsewhere on the board
I2C1/SDA: JP1.22, R39.2, R45.2, U$1.8 (PE22/UART1/RX), U$8.9 (SDA); also elsewhere on the board
KEYADC0: C34.2, R29.1, U$1.112 (LRADC0)
LCD_D22: U$1.7 (PE23/LCD-D22/); also elsewhere on the board
LCD_D23: U$1.6 (PE24/LCD-D23); also elsewhere on the board
MIPI-CSI-MCLK/CSI-FIELD: JP1.15, U$1.10 (PE20/CSI-FIELD/CSI-MIPI-M-CLK); also elsewhere on the board
unnamed: ANT2.D, C4.2
unnamed: R19.1, U$2.P$23 (VIN_LDO)
unnamed: JP7.3, U$2.P$44 (UART_CTS)
unnamed: R9.2, U$2.P$12 (WL_REG)
unnamed: JP7.2, U$2.P$43 (UART_RXD)
unnamed: JP7.1, U$2.P$42 (UART_TXD)
unnamed: R10.1, U$2.P$34 (BT_RST)
unnamed: C4.1, U$2.P$2 (WL_BT_ANT)
PB2/ACT_LED: JP1.12, U$1.41 (PB2); also elsewhere on the board
PB3/HOTPLUG_GPIO: JP1.7, U$1.42 (PB3); also elsewhere on the board
PB4/PWM0: JP1.13, U$1.43 (PB4/PWM0)
PB5/PWM1: JP1.11, U$1.44 (PB5/PWM1)
SDC0/CLK: U$1.105 (PF2/SDC0/CLK); also elsewhere on the board
SDC0/CMD: U$1.103 (PF3/SDC0/CMD); also elsewhere on the board
SDC0/D0: U$1.106 (PF1/SDC0/D0); also elsewhere on the board
SDC0/D1: U$1.107 (PF0/SDC0/D1); also elsewhere on the board
SDC0/D2: U$1.101 (PF5/SDC0/D2); also elsewhere on the board
SDC0/D3: U$1.102 (PF4/SDC0/D3); also elsewhere on the board
SDC1/CLK: U$1.5 (PG0/SDC1/CLK), U$2.P$17 (SDIO_CLK)
SDC1/CMD: R36.2, U$1.4 (PG1/SDC1/CMD), U$2.P$16 (SDIO_CMD)
SDC1/D0: RN1.8 (2), U$1.3 (PG2/SDC1/D0), U$2.P$18 (SDIO_D0)
SDC1/D1: RN1.7 (2), U$1.2 (PG3/SDC1/D1), U$2.P$19 (SDIO_D1)
SDC1/D2: RN1.6 (2), U$1.1 (PG4/SDC1/D2), U$2.P$14 (SDIO_D2)
SDC1/D3: RN1.5 (2), U$1.128 (PG5/SDC1/D3), U$2.P$15 (SDIO_D3)
SPI1/CS: JP1.24, R8.1, U1.1 (CS), U$1.54 (PC2/SPI1/CS)
SPI1/MISO: JP1.21, U1.2 (MISO), U$1.52 (PC0/SPI1/MISO)
SPI1/MOSI: JP1.19, U1.5 (MOSI), U$1.55 (PC3/SPI1/MOSI)
SPI1/SCK: JP1.23, U1.6 (SCK), U$1.53 (PC1/SPI1/SCK)
TPX1: U$8.2 (XP); also elsewhere on the board
TPX2: U$8.4 (XN); also elsewhere on the board
TPY1: U$8.3 (YP); also elsewhere on the board
TPY2: U$8.5 (YN); also elsewhere on the board
UART0/RX: JP1.10, U$1.49 (PB9/I2C1/SDA)
UART0/TX: JP1.8, U$1.48 (PB8/I2C1/SCL)
UART2/RX/PB1: JP1.16, U$1.40 (PB1/UART2/RX)
UART2/TX/PB0: JP1.18, U$1.39 (PB0/UART2/TX)
USB/ID: R32.2, U$1.100 (PF6); also elsewhere on the board
VCC-PE: R44.1, R45.1; also elsewhere on the board
WL_H_WK: U$2.P$13 (WL_H_WK)

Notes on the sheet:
IO / LRADC / RTL8723BS / Touch / SPI Flash
Copyright (c) 2018 Marcel Thürmer <marcel.thuermer@smail.emt.h-brs.de> Open Source Hardware under the 3-clause BSD License
SPI NOR Flash
WLAN-Modul RTL8723BS
P1-Header
Touch Controller
IO / LRADC / RTL8723BS / Touch /SPI Flash

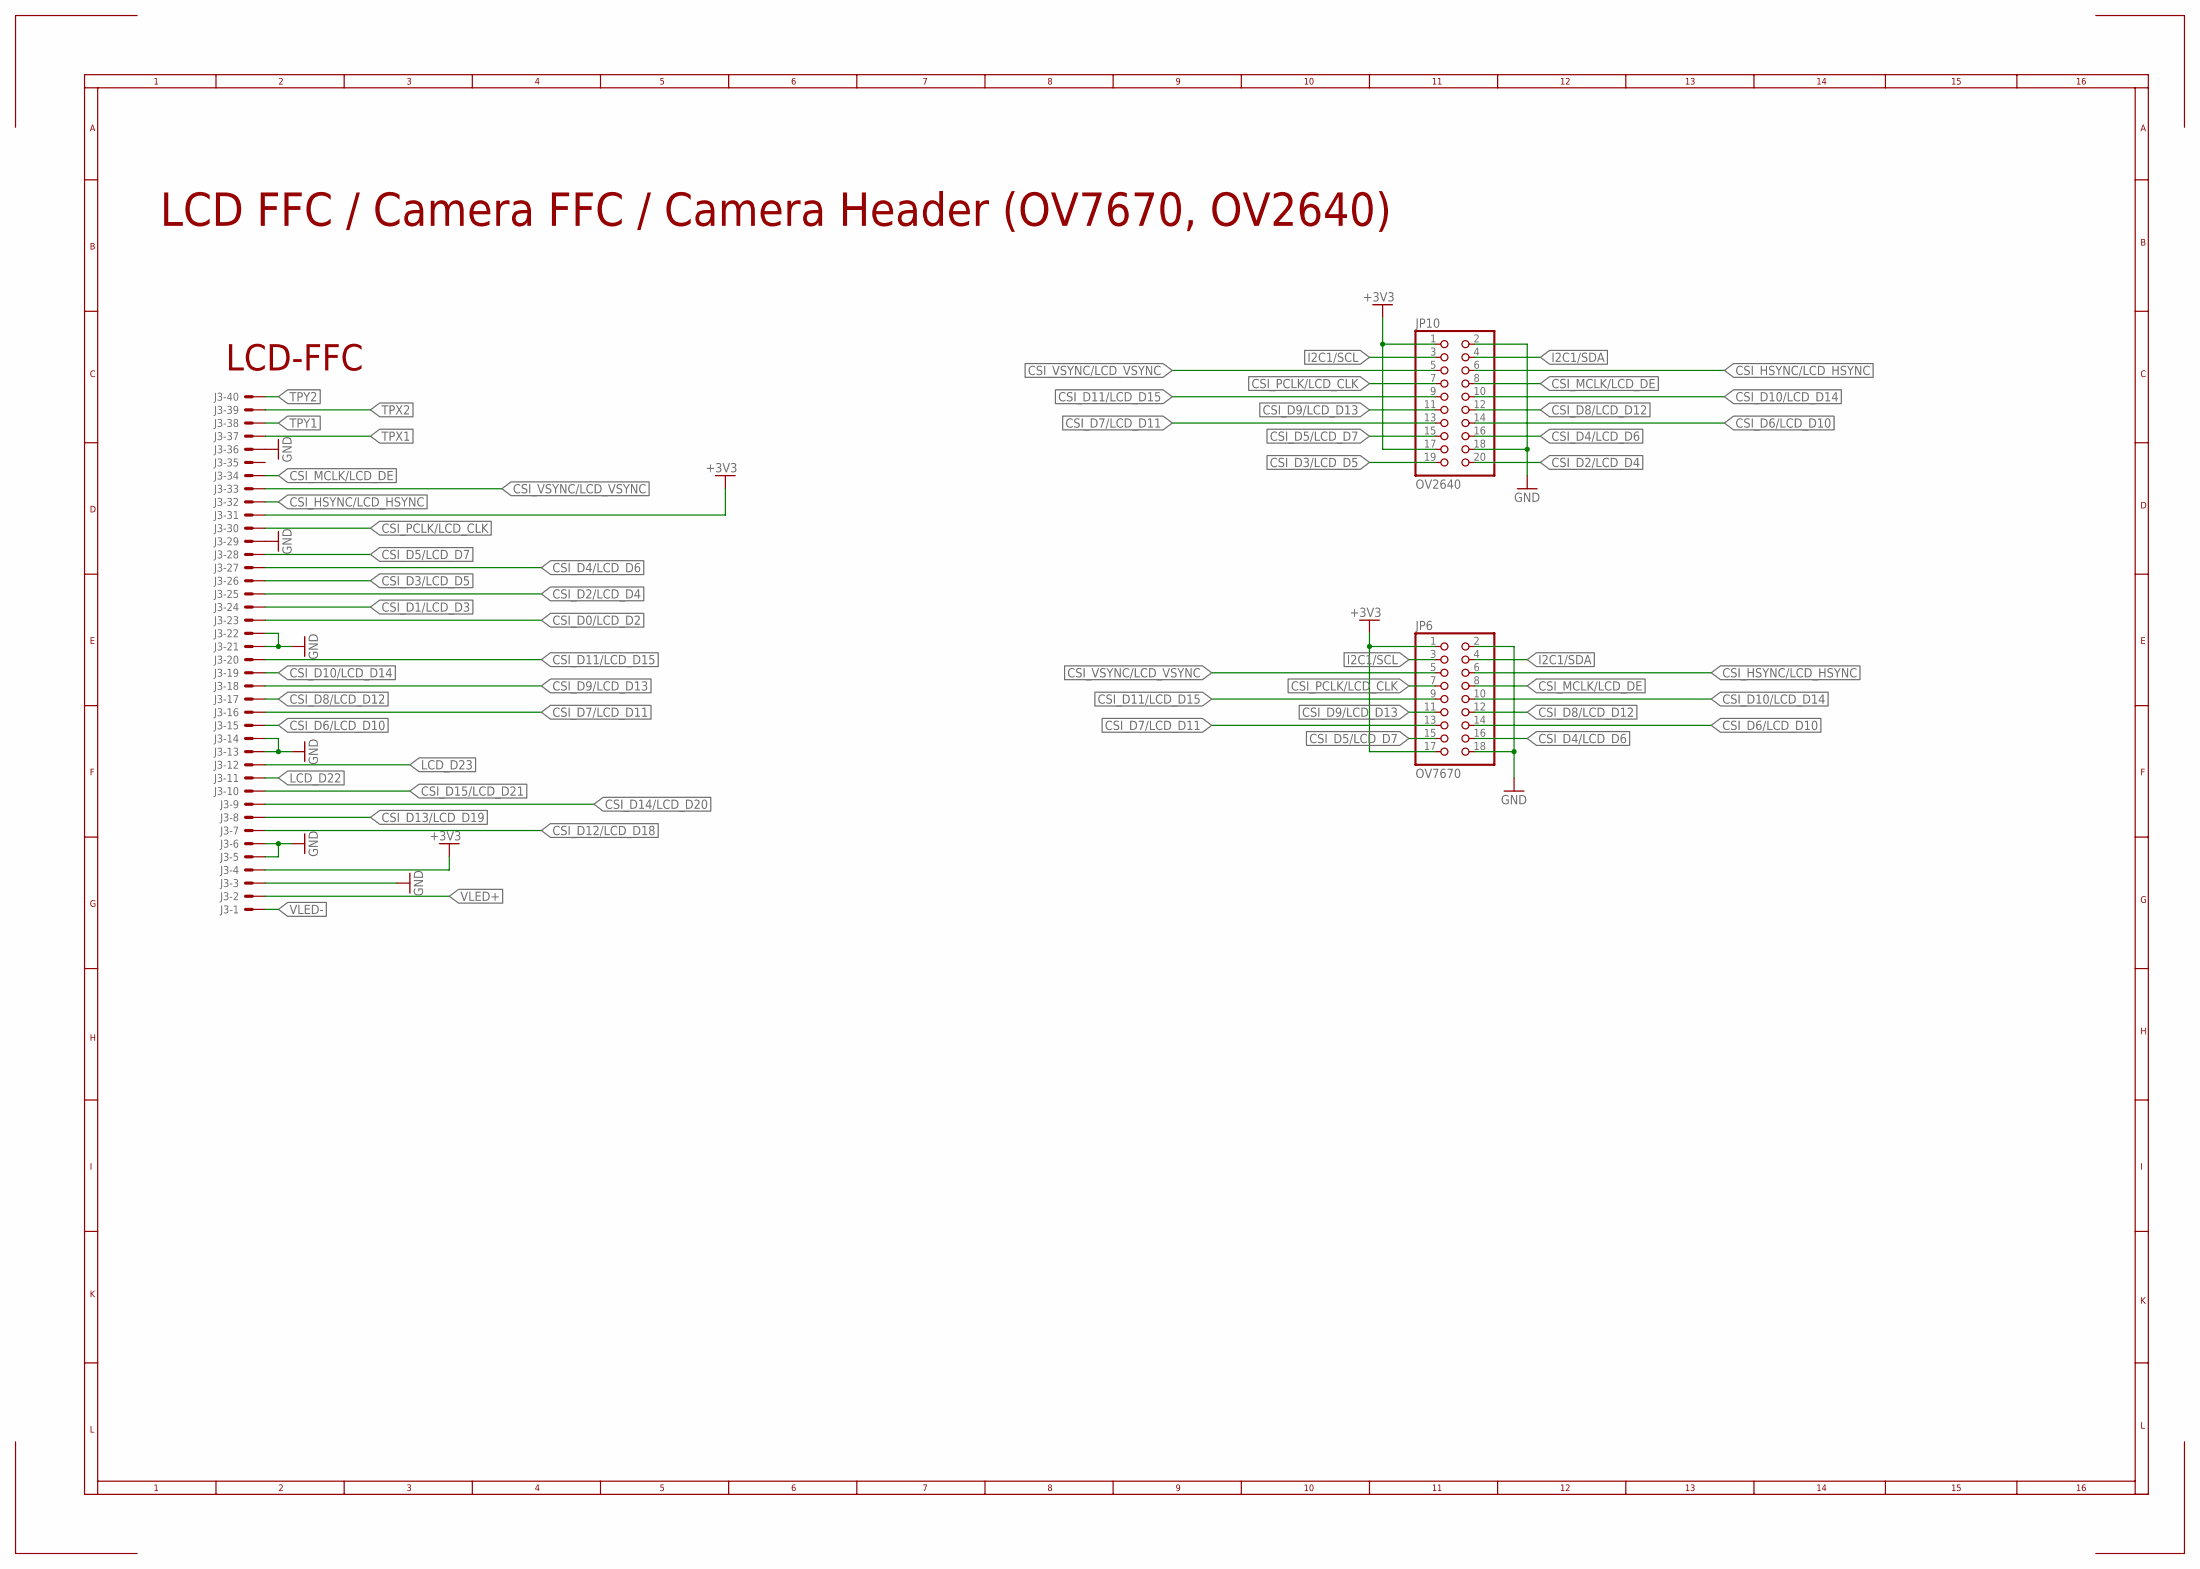
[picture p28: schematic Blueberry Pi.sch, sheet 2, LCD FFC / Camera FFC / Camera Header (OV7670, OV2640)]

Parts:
J3: 40PINFPCH15-1LW; XF2H-4015-1LW
JP6: OV7670; 2X09
JP10: OV2640; 2X10

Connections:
+3V3: J3.4 (MS), J3.31 (MS), JP6.1, JP6.17, JP10.1, JP10.17; also elsewhere on the board
CSI_D0/LCD_D2: J3.23 (MS); also elsewhere on the board
CSI_D1/LCD_D3: J3.24 (MS); also elsewhere on the board
CSI_D2/LCD_D4: J3.25 (MS), JP10.20; also elsewhere on the board
CSI_D3/LCD_D5: J3.26 (MS), JP10.19; also elsewhere on the board
CSI_D4/LCD_D6: J3.27 (MS), JP6.16, JP10.16; also elsewhere on the board
CSI_D5/LCD_D7: J3.28 (MS), JP6.15, JP10.15; also elsewhere on the board
CSI_D6/LCD_D10: J3.15 (MS), JP6.14, JP10.14; also elsewhere on the board
CSI_D7/LCD_D11: J3.16 (MS), JP6.13, JP10.13; also elsewhere on the board
CSI_D8/LCD_D12: J3.17 (MS), JP6.12, JP10.12; also elsewhere on the board
CSI_D9/LCD_D13: J3.18 (MS), JP6.11, JP10.11; also elsewhere on the board
CSI_D10/LCD_D14: J3.19 (MS), JP6.10, JP10.10; also elsewhere on the board
CSI_D11/LCD_D15: J3.20 (MS), JP6.9, JP10.9; also elsewhere on the board
CSI_D12/LCD_D18: J3.7 (MS); also elsewhere on the board
CSI_D13/LCD_D19: J3.8 (MS); also elsewhere on the board
CSI_D14/LCD_D20: J3.9 (MS); also elsewhere on the board
CSI_D15/LCD_D21: J3.10 (MS); also elsewhere on the board
CSI_HSYNC/LCD_HSYNC: J3.32 (MS), JP6.6, JP10.6; also elsewhere on the board
CSI_MCLK/LCD_DE: J3.34 (MS), JP6.8, JP10.8; also elsewhere on the board
CSI_PCLK/LCD_CLK: J3.30 (MS), JP6.7, JP10.7; also elsewhere on the board
CSI_VSYNC/LCD_VSYNC: J3.33 (MS), JP6.5, JP10.5; also elsewhere on the board
GND: J3.3 (MS), J3.5 (MS), J3.6 (MS), J3.13 (MS), J3.14 (MS), J3.21 (MS), J3.22 (MS), J3.29 (MS), J3.36 (MS), JP6.2, JP6.18, JP10.2, JP10.18; also elsewhere on the board
I2C1/SCL: JP6.3, JP10.3; also elsewhere on the board
I2C1/SDA: JP6.4, JP10.4; also elsewhere on the board
LCD_D22: J3.11 (MS); also elsewhere on the board
LCD_D23: J3.12 (MS); also elsewhere on the board
TPX1: J3.37 (MS); also elsewhere on the board
TPX2: J3.39 (MS); also elsewhere on the board
TPY1: J3.38 (MS); also elsewhere on the board
TPY2: J3.40 (MS); also elsewhere on the board
VLED+: J3.2 (MS); also elsewhere on the board
VLED-: J3.1 (MSV); also elsewhere on the board

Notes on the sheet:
LCD-FFC
LCD FFC / Camera FFC / Camera Header (OV7670, OV2640)

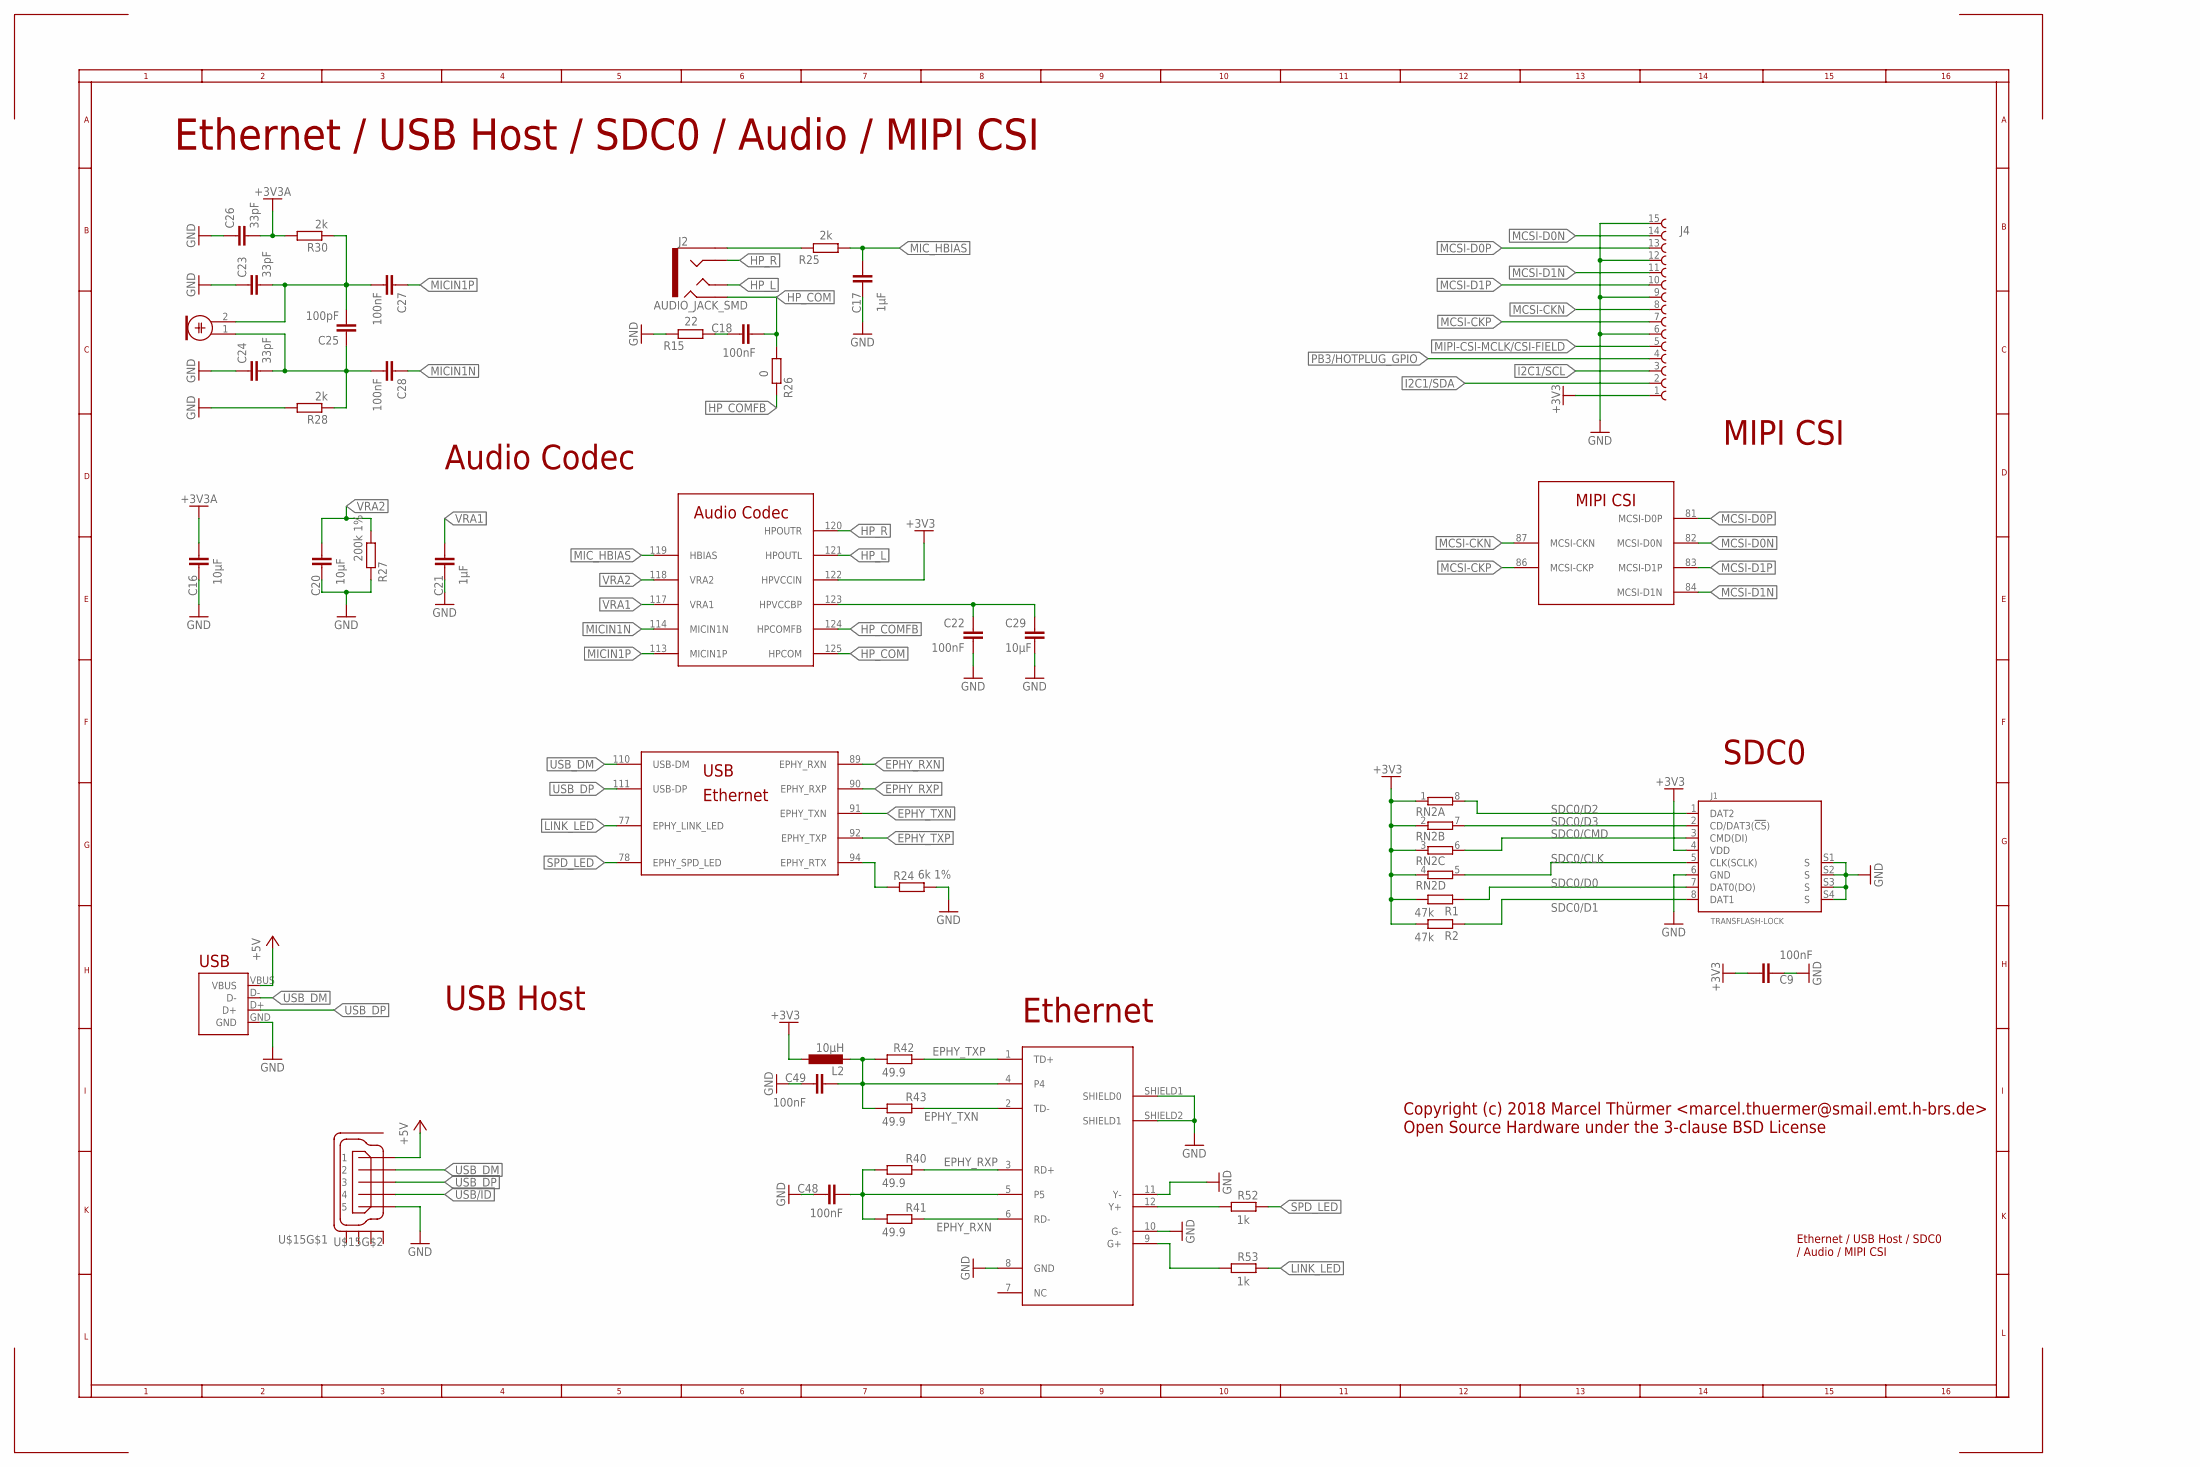
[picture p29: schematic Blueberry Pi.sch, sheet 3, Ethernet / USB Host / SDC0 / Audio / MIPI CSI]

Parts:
C9, C18, C22, C27, C28, C48, C49: 100nF; C0603
C16, C20, C29: 10µF; C0805
C17, C21: 1µF; C0603
C23, C24, C26: 33pF; C0603
C25: 100pF; C0603
J1: TRANSFLASH-LOCK; TRANSFLASH-LOCK-SOCK
J2: AUDIO_JACK_SMD; AUDIO_JACK_3.5MM_TRRS_SMD_RA
J4: 68611514122
L2: 10µH; L0805
MIC: ELECTRET_MICROPHON-F6035AP; F6035AP
R1, R2: 47k; R0603
R15: 22; R0603
R24: 6k 1%; R0603
R25, R28, R30: 2k; R0603
R26: 0; R0603
R27: 200k 1%; R0603
R40, R41, R42, R43: 49.9; R0603
R52, R53: 1k; R0603
RN2: 4R-NEXB38V; EXB38V
U$1: V3S; QFP-128
U$3: HR911105A; RJ45
U$15: CON-HIROSE_MICRO-USB-SHIELD-ZX62R-B-5P; CON-HIROSE_ZX62R-B-5P
X1: USB-B-S; USB-B-SMT

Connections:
+3V3: C9.1, J1.4 (VDD), J4.1 (15), L2.1, R1.2, R2.2, RN2.1, RN2.2 (1), RN2.3 (1), RN2.4 (1), U$1.122 (HPVCCIN); also elsewhere on the board
+3V3A: C16.2, C26.2, R30.2; also elsewhere on the board
+5V: U$15.1, X1.VBUS; also elsewhere on the board
EPHY_RXN: R41.1, U$1.89 (EPHY_RXN), U$3.6 (RD-)
EPHY_RXP: R40.1, U$1.90 (EPHY_RXP), U$3.3 (RD+)
EPHY_TXN: R43.1, U$1.91 (EPHY_TXN), U$3.2 (TD-)
EPHY_TXP: R42.1, U$1.92 (EPHY_TXP), U$3.1 (TD+)
GND: C9.2, C16.1, C17.2, C20.1, C21.1, C22.2, C23.1, C24.1, C26.1, C29.1, C48.2, C49.2, J1.6 (GND), J1.S1 (S), J1.S2 (S), J1.S3 (S), J1.S4 (S), J4.6 (10), J4.9 (7), J4.12 (4), J4.15 (1), R15.1, R24.2, R27.1, R28.2, U$3.8 (GND), U$3.10 (G-), U$3.11 (Y-), U$3.SHIELD1 (SHIELD0), U$3.SHIELD2 (SHIELD1), U$15.5, X1.GND; also elsewhere on the board
HP_COM: C18.2, J2.RING2, R26.2, U$1.125 (HPCOM)
HP_COMFB: R26.1, U$1.124 (HPCOMFB)
HP_L: J2.TIP, U$1.121 (HPOUTL)
HP_R: J2.RING1, U$1.120 (HPOUTR)
I2C1/SCL: J4.3 (13); also elsewhere on the board
I2C1/SDA: J4.2 (14); also elsewhere on the board
LINK_LED: R53.1, U$1.77 (EPHY_LINK_LED)
MCSI-CKN: J4.8, U$1.87 (MCSI-CKN)
MCSI-CKP: J4.7 (9), U$1.86 (MCSI-CKP)
MCSI-D0N: J4.14 (2), U$1.82 (MCSI-D0N)
MCSI-D0P: J4.13 (3), U$1.81 (MCSI-D0P)
MCSI-D1N: J4.11 (5), U$1.84 (MCSI-D1N)
MCSI-D1P: J4.10 (6), U$1.83 (MCSI-D1P)
MICIN1N: C28.1, U$1.114 (MICIN1N)
MICIN1P: C27.1, U$1.113 (MICIN1P)
MIC_HBIAS: C17.1, R25.2, U$1.119 (HBIAS)
MIPI-CSI-MCLK/CSI-FIELD: J4.5 (11); also elsewhere on the board
unnamed: R24.1, U$1.94 (EPHY_RTX)
unnamed: R53.2, U$3.9 (G+)
unnamed: R52.2, U$3.12 (Y+)
unnamed: C49.1, L2.2, R42.2, R43.2, U$3.4
unnamed: C48.1, R40.2, R41.2, U$3.5
unnamed: C22.1, C29.2, U$1.123 (HPVCCBP)
unnamed: J2.EARTH, R25.1
unnamed: C18.1, R15.2
unnamed: C23.2, C25.2, C27.2, MIC.2, R30.1
unnamed: C24.2, C25.1, C28.2, MIC.1, R28.1
PB3/HOTPLUG_GPIO: J4.4 (12); also elsewhere on the board
SDC0/CLK: J1.5 (CLK(SCLK)), RN2.5 (2); also elsewhere on the board
SDC0/CMD: J1.3 (CMD(DI)), RN2.6 (2); also elsewhere on the board
SDC0/D0: J1.7 (DAT0(DO)), R1.1; also elsewhere on the board
SDC0/D1: J1.8 (DAT1), R2.1; also elsewhere on the board
SDC0/D2: J1.1 (DAT2), RN2.8 (2); also elsewhere on the board
SDC0/D3: J1.2 (CD/DAT3(!CS!)), RN2.7 (2); also elsewhere on the board
SPD_LED: R52.1, U$1.78 (EPHY_SPD_LED)
USB/ID: U$15.4; also elsewhere on the board
USB_DM: U$1.110 (USB-DM), U$15.2, X1.D-
USB_DP: U$1.111 (USB-DP), U$15.3, X1.D+
VRA1: C21.2, U$1.117 (VRA1)
VRA2: C20.2, R27.2, U$1.118 (VRA2)

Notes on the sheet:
Ethernet / USB Host / SDC0 / Audio / MIPI CSI
USB Host
Audio Codec
MIPI CSI
Ethernet
SDC0
Copyright (c) 2018 Marcel Thürmer <marcel.thuermer@smail.emt.h-brs.de> Open Source Hardware under the 3-clause BSD License
Ethernet / USB Host / SDC0 / Audio / MIPI CSI

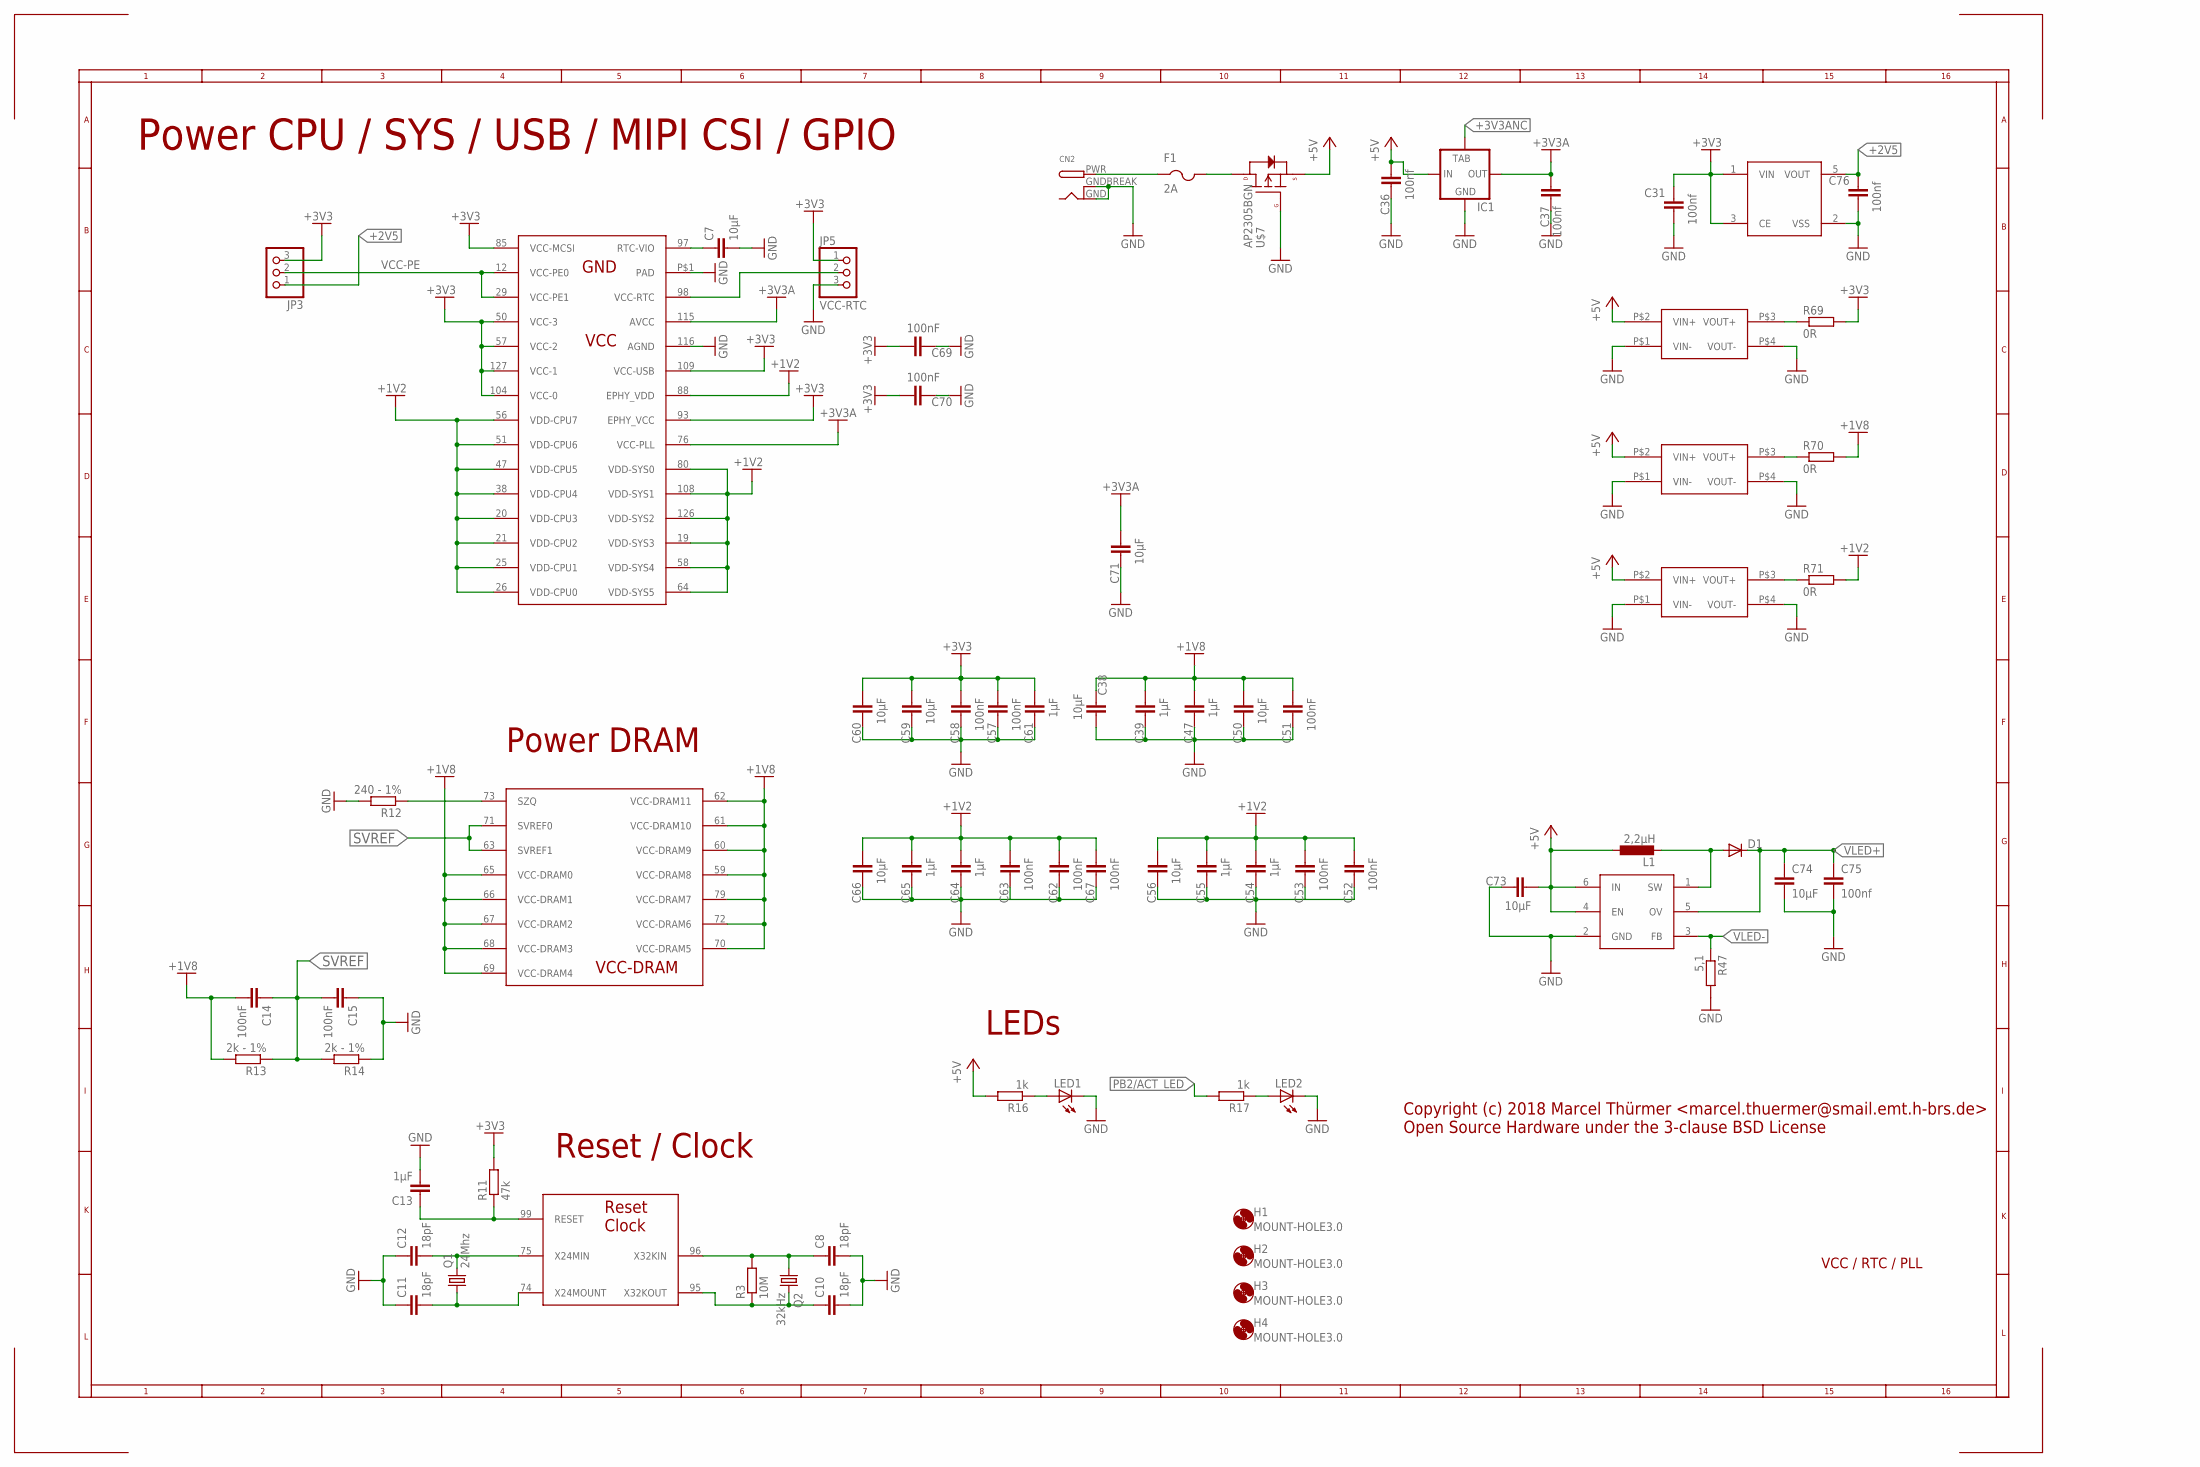
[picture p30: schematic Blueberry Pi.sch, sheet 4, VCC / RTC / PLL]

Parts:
C7, C50, C59, C66, C73, C74: 10µF; C0805
C8, C10, C11, C12: 18pF; C0603
C13, C39, C47, C55, C64, C65: 1µF; C0603
C14, C15, C51, C53, C57, C58, C62, C67, C70: 100nF; C0603
C31, C36, C37, C75, C76: 100nf; C0603
C38, C56, C60, C71: 10µF; C0603
C52, C63, C69: 100nF; C0805
C54, C61: 1µF; C0805
CN2: DCBARRELPTH; DCJACK_2MM_PTH
D1: DIODE-SOD323-W; SOD323-W
F1: 2A; R1206
H1, H2, H3, H4: MOUNT-HOLE3.0; 3,0
IC1: LM1117; SOT223
JP3: PINHD-1X3; 1X03
JP5: VCC-RTC; 1X03
L1: 2,2µH; ODD-INDUCTOR
LED1, LED2: LEDCHIPLED_0805; CHIPLED_0805
Q1: 24Mhz; HC49U-V
Q2: 32kHz; TC38H
R3: 10M; R0603
R11: 47k; R0603
R12: 240 - 1%; R0603
R13, R14: 2k - 1%; R0603
R16, R17: 1k; R0603
R47: 5,1; R0603
R69, R70, R71: 0R; R0603
U$1: V3S; QFP-128
U$4, U$10, U$11: MP1584-MINI; MINI-DC-BRICK
U$6: XC6204; SOT25
U$7: AP2305BGN; SOT23-3
U$9: PT4101; SOT23-6

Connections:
5VNS: CN2.PWR, F1.1
+1V2: C52.1, C53.1, C54.1, C55.1, C56.1, C62.1, C63.1, C64.1, C65.1, C66.1, C67.1, R71.2, U$1.19 (VDD-SYS3), U$1.20 (VDD-CPU3), U$1.21 (VDD-CPU2), U$1.25 (VDD-CPU1), U$1.26 (VDD-CPU0), U$1.38 (VDD-CPU4), U$1.47 (VDD-CPU5), U$1.51 (VDD-CPU6), U$1.56 (VDD-CPU7), U$1.58 (VDD-SYS4), U$1.64 (VDD-SYS5), U$1.80 (VDD-SYS0), U$1.88 (EPHY_VDD), U$1.108 (VDD-SYS1), U$1.126 (VDD-SYS2)
+1V8: C14.2, C38.2, C39.1, C47.1, C50.1, C51.1, R13.2, R70.2, U$1.59 (VCC-DRAM8), U$1.60 (VCC-DRAM9), U$1.61 (VCC-DRAM10), U$1.62 (VCC-DRAM11), U$1.65 (VCC-DRAM0), U$1.66 (VCC-DRAM1), U$1.67 (VCC-DRAM2), U$1.68 (VCC-DRAM3), U$1.69 (VCC-DRAM4), U$1.70 (VCC-DRAM5), U$1.72 (VCC-DRAM6), U$1.79 (VCC-DRAM7)
+2V5: C76.1, JP3.1, U$6.5 (VOUT)
+3V3: C31.1, C57.1, C58.1, C59.1, C60.1, C61.1, C69.1, C70.1, JP3.3, JP5.1, R11.2, R69.2, U$1.50 (VCC-3), U$1.57 (VCC-2), U$1.85 (VCC-MCSI), U$1.93 (EPHY_VCC), U$1.104 (VCC-0), U$1.109 (VCC-USB), U$1.127 (VCC-1), U$6.1 (VIN), U$6.3 (CE); also elsewhere on the board
+3V3A: C37.1, C71.1, IC1.2 (OUT), U$1.76 (VCC-PLL), U$1.115 (AVCC); also elsewhere on the board
+3V3ANC: IC1.4 (IN1)
+5V: C36.1, C73.1, IC1.3 (IN), L1.P$1 (1), R16.2, U$4.P$2 (VIN+), U$7.2 (S), U$9.4 (EN), U$9.6 (IN), U$10.P$2 (VIN+), U$11.P$2 (VIN+); also elsewhere on the board
GND: C7.2, C8.2, C10.2, C11.1, C12.1, C13.2, C15.1, C31.2, C36.2, C37.2, C38.1, C39.2, C47.2, C50.2, C51.2, C52.2, C53.2, C54.2, C55.2, C56.2, C57.2, C58.2, C59.2, C60.2, C61.2, C62.2, C63.2, C64.2, C65.2, C66.2, C67.2, C69.2, C70.2, C71.2, C73.2, C74.2, C75.2, C76.2, CN2.GND, CN2.GNDBREAK, IC1.1 (GND), JP5.3, LED1.C, LED2.C, R12.2, R14.1, R47.2, U$1.116 (AGND), U$1.P$1 (PAD), U$4.P$1 (VIN-), U$4.P$4 (VOUT-), U$6.2 (VSS), U$7.1 (G), U$9.2 (GND), U$10.P$1 (VIN-), U$10.P$4 (VOUT-), U$11.P$1 (VIN-), U$11.P$4 (VOUT-); also elsewhere on the board
unnamed: LED1.A, R16.1
unnamed: LED2.A, R17.1
unnamed: D1.A, L1.P$2 (2), U$9.1 (SW)
unnamed: C7.1, U$1.97 (RTC-VIO)
unnamed: JP5.2, U$1.98 (VCC-RTC)
unnamed: C10.1, Q2.2, R3.1, U$1.95 (X32KOUT)
unnamed: C8.1, Q2.1, R3.2, U$1.96 (X32KIN)
unnamed: C11.2, Q1.1, U$1.74 (X24MOUNT)
unnamed: C12.2, Q1.2, U$1.75 (X24MIN)
unnamed: C13.1, R11.1, U$1.99 (RESET)
unnamed: R12.1, U$1.73 (SZQ)
unnamed: R69.1, U$4.P$3 (VOUT+)
unnamed: R70.1, U$10.P$3 (VOUT+)
unnamed: F1.2, U$7.3 (D)
unnamed: R71.1, U$11.P$3 (VOUT+)
PB2/ACT_LED: R17.2; also elsewhere on the board
SVREF: C14.1, C15.2, R13.1, R14.2, U$1.63 (SVREF1), U$1.71 (SVREF0)
VCC-PE: JP3.2, U$1.12 (VCC-PE0), U$1.29 (VCC-PE1); also elsewhere on the board
VLED+: C74.1, C75.1, D1.C, U$9.5 (OV); also elsewhere on the board
VLED-: R47.1, U$9.3 (FB); also elsewhere on the board

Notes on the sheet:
VCC / RTC / PLL
Power CPU / SYS / USB / MIPI CSI / GPIO
Power DRAM
Copyright (c) 2018 Marcel Thürmer <marcel.thuermer@smail.emt.h-brs.de> Open Source Hardware under the 3-clause BSD License
Reset / Clock
LEDs

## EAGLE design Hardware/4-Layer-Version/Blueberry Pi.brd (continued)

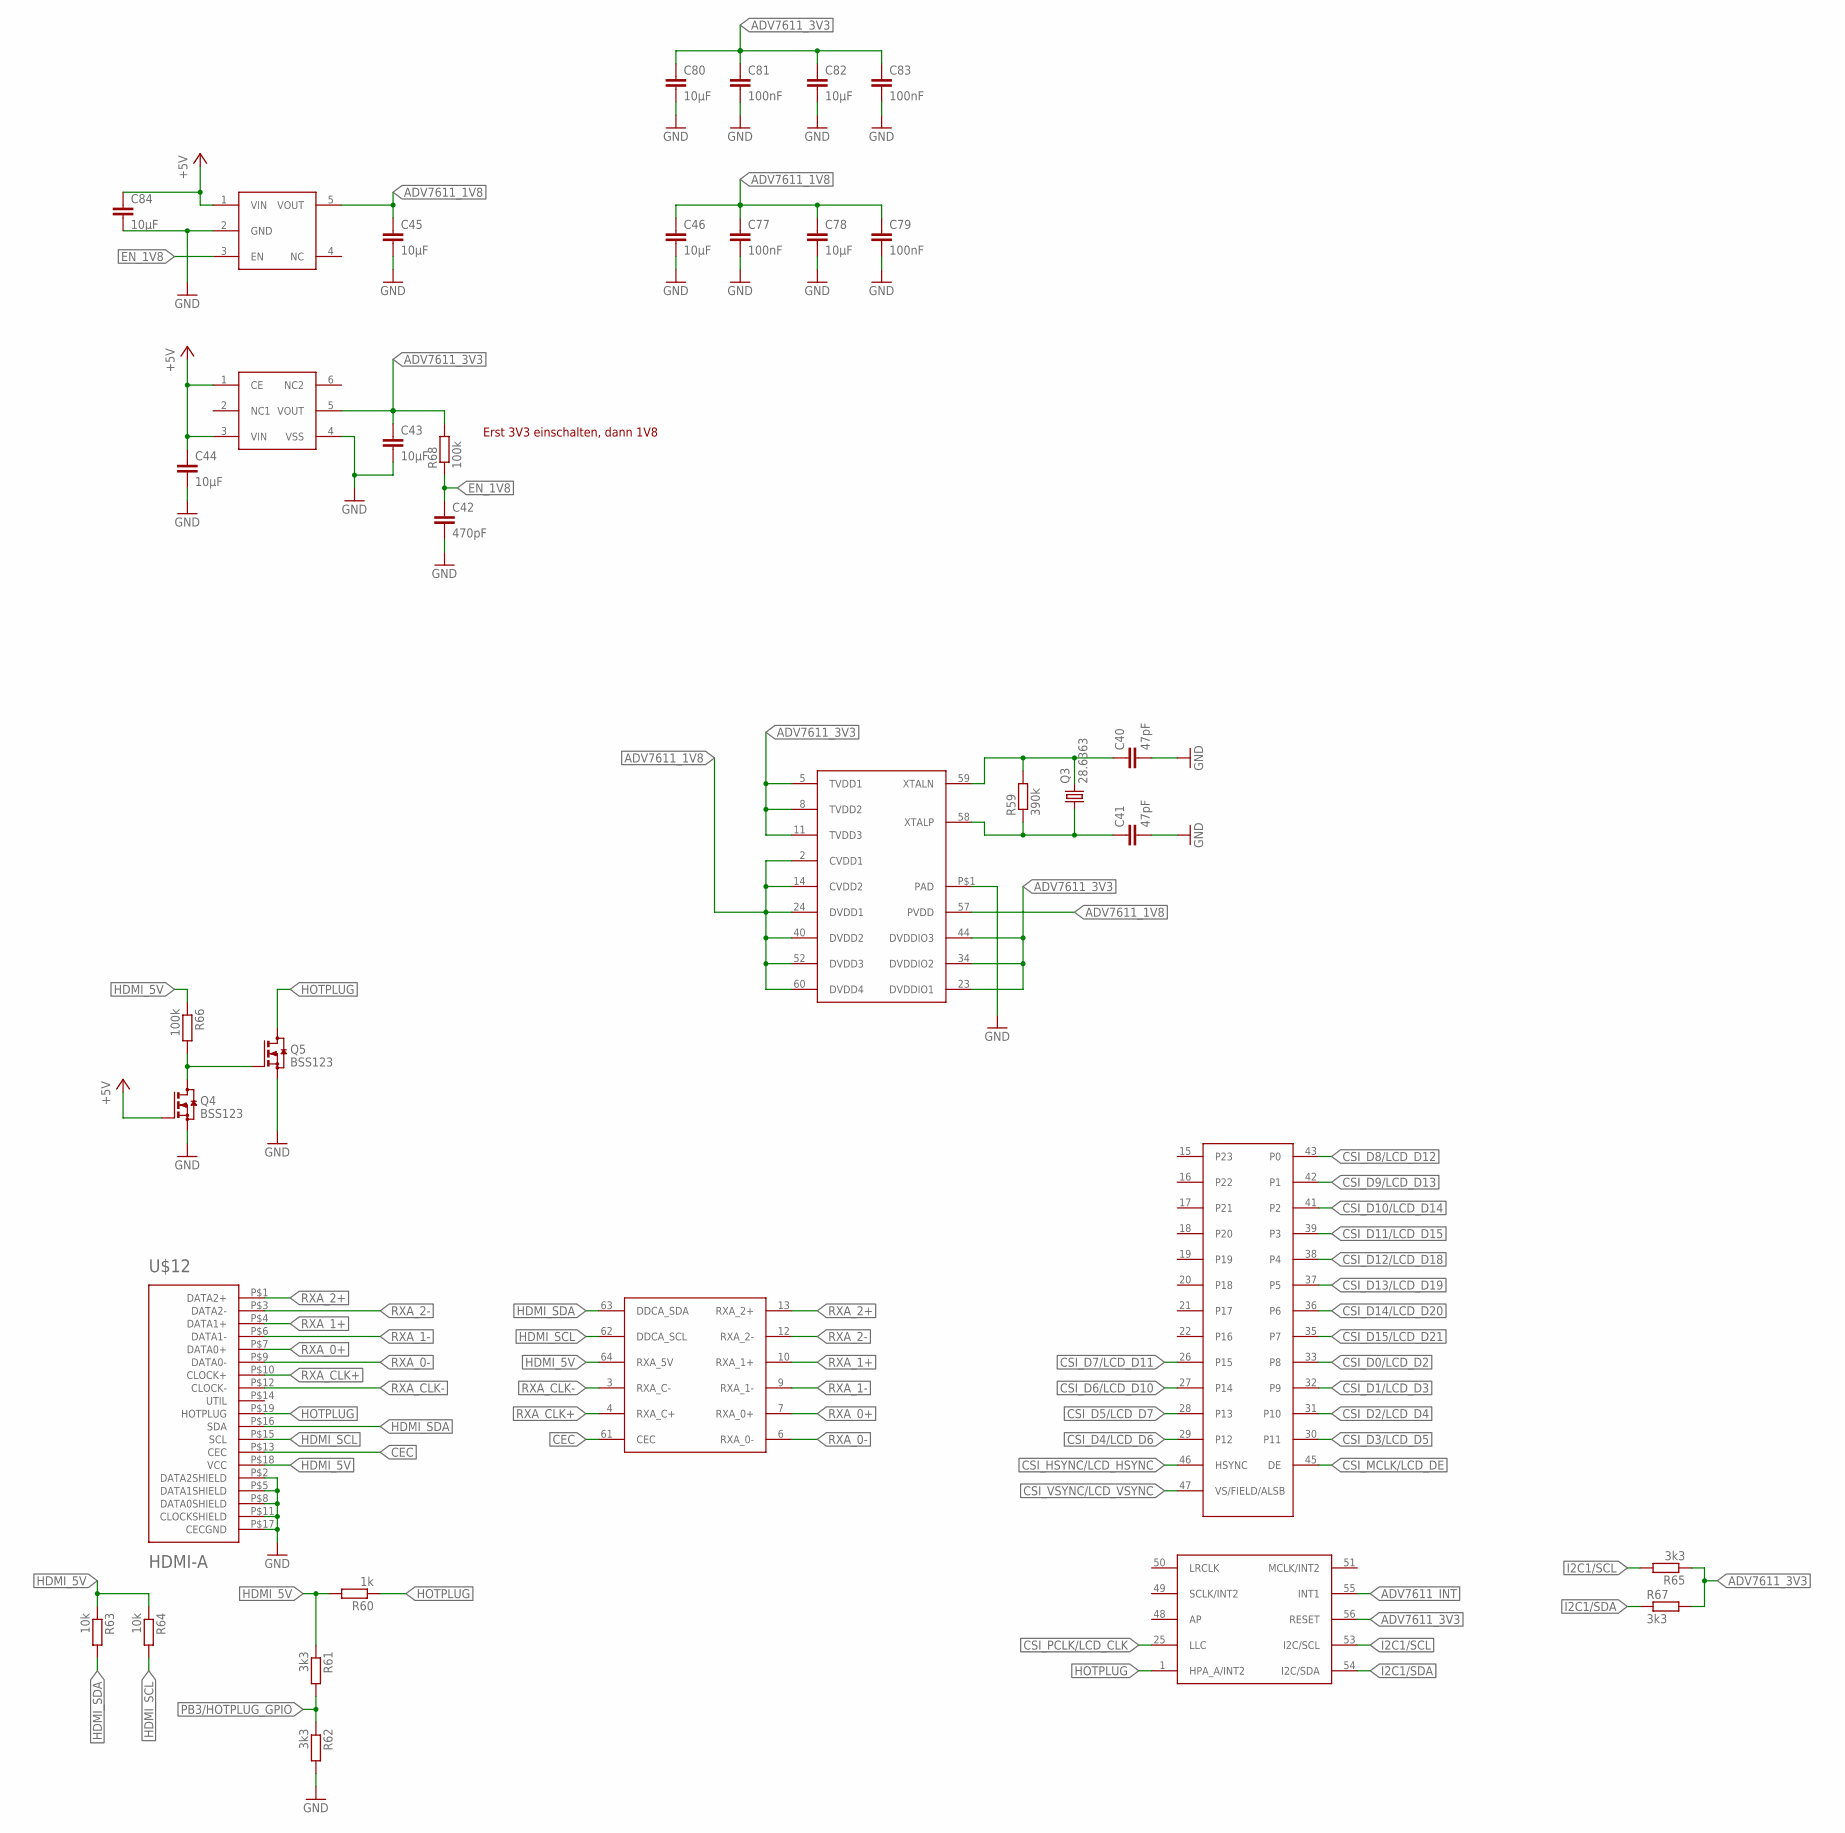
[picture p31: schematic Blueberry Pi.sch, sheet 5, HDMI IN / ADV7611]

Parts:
C40, C41: 47pF; C0603
C42: 470pF; C0603
C43, C44, C45, C46, C78, C80, C82, C84: 10µF; C0805
C77, C79, C81, C83: 100nF; C0603
Q3: 28.6363; HC49/S
Q4, Q5: BSS123; SOT23
R59: 390k; R0603
R60: 1k; R0603
R61, R62, R65, R67: 3k3; R0603
R63, R64: 10k; R0603
R66, R68: 100k; R0603
U$5: ADV7611; QFP50P1210X1210X120-65T500
U$12: HDMI-A; HDMI_A
U$13: XC6210B332MR-G; SOT-25
U$14: RT9013-18GB; SOT-23-5

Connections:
+5V: C44.1, C84.1, Q4.1 (G), U$13.1 (CE), U$13.3 (VIN), U$14.1 (VIN); also elsewhere on the board
ADV7611_1V8: C45.1, C46.1, C77.1, C78.1, C79.1, U$5.2 (CVDD1), U$5.14 (CVDD2), U$5.24 (DVDD1), U$5.40 (DVDD2), U$5.52 (DVDD3), U$5.57 (PVDD), U$5.60 (DVDD4), U$14.5 (VOUT)
ADV7611_3V3: C43.1, C80.1, C81.1, C82.1, C83.1, R65.1, R67.2, R68.2, U$5.5 (TVDD1), U$5.8 (TVDD2), U$5.11 (TVDD3), U$5.23 (DVDDIO1), U$5.34 (DVDDIO2), U$5.44 (DVDDIO3), U$5.56 (RESET), U$13.5 (VOUT)
ADV7611_INT: U$5.55 (INT1)
CEC: U$5.61 (CEC), U$12.P$13 (CEC)
CSI_D0/LCD_D2: U$5.33 (P8); also elsewhere on the board
CSI_D1/LCD_D3: U$5.32 (P9); also elsewhere on the board
CSI_D2/LCD_D4: U$5.31 (P10); also elsewhere on the board
CSI_D3/LCD_D5: U$5.30 (P11); also elsewhere on the board
CSI_D4/LCD_D6: U$5.29 (P12); also elsewhere on the board
CSI_D5/LCD_D7: U$5.28 (P13); also elsewhere on the board
CSI_D6/LCD_D10: U$5.27 (P14); also elsewhere on the board
CSI_D7/LCD_D11: U$5.26 (P15); also elsewhere on the board
CSI_D8/LCD_D12: U$5.43 (P0); also elsewhere on the board
CSI_D9/LCD_D13: U$5.42 (P1); also elsewhere on the board
CSI_D10/LCD_D14: U$5.41 (P2); also elsewhere on the board
CSI_D11/LCD_D15: U$5.39 (P3); also elsewhere on the board
CSI_D12/LCD_D18: U$5.38 (P4); also elsewhere on the board
CSI_D13/LCD_D19: U$5.37 (P5); also elsewhere on the board
CSI_D14/LCD_D20: U$5.36 (P6); also elsewhere on the board
CSI_D15/LCD_D21: U$5.35 (P7); also elsewhere on the board
CSI_HSYNC/LCD_HSYNC: U$5.46 (HSYNC); also elsewhere on the board
CSI_MCLK/LCD_DE: U$5.45 (DE); also elsewhere on the board
CSI_PCLK/LCD_CLK: U$5.25 (LLC); also elsewhere on the board
CSI_VSYNC/LCD_VSYNC: U$5.47 (VS/FIELD/ALSB); also elsewhere on the board
EN_1V8: C42.1, R68.1, U$14.3 (EN)
GND: C40.2, C41.2, C42.2, C43.2, C44.2, C45.2, C46.2, C77.2, C78.2, C79.2, C80.2, C81.2, C82.2, C83.2, C84.2, Q4.2 (S), Q5.2 (S), R62.2, U$5.P$1 (PAD), U$12.P$2 (DATA2SHIELD), U$12.P$5 (DATA1SHIELD), U$12.P$8 (DATA0SHIELD), U$12.P$11 (CLOCKSHIELD), U$12.P$17 (CECGND), U$13.4 (VSS), U$14.2 (GND); also elsewhere on the board
HDMI_5V: R60.2, R61.1, R63.1, R64.1, R66.1, U$5.64 (RXA_5V), U$12.P$18 (VCC)
HDMI_SCL: R64.2, U$5.62 (DDCA_SCL), U$12.P$15 (SCL)
HDMI_SDA: R63.2, U$5.63 (DDCA_SDA), U$12.P$16 (SDA)
HOTPLUG: Q5.3 (D), R60.1, U$5.1 (HPA_A/INT2), U$12.P$19 (HOTPLUG)
I2C1/SCL: R65.2, U$5.53 (I2C/SCL); also elsewhere on the board
I2C1/SDA: R67.1, U$5.54 (I2C/SDA); also elsewhere on the board
unnamed: C40.1, Q3.2, R59.2, U$5.59 (XTALN)
unnamed: C41.1, Q3.1, R59.1, U$5.58 (XTALP)
unnamed: Q4.3 (D), Q5.1 (G), R66.2
PB3/HOTPLUG_GPIO: R61.2, R62.1; also elsewhere on the board
RXA_0+: U$5.7 (RXA_0+), U$12.P$7 (DATA0+)
RXA_0-: U$5.6 (RXA_0-), U$12.P$9 (DATA0-)
RXA_1+: U$5.10 (RXA_1+), U$12.P$4 (DATA1+)
RXA_1-: U$5.9 (RXA_1-), U$12.P$6 (DATA1-)
RXA_2+: U$5.13 (RXA_2+), U$12.P$1 (DATA2+)
RXA_2-: U$5.12 (RXA_2-), U$12.P$3 (DATA2-)
RXA_CLK+: U$5.4 (RXA_C+), U$12.P$10 (CLOCK+)
RXA_CLK-: U$5.3 (RXA_C-), U$12.P$12 (CLOCK-)

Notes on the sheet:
Erst 3V3 einschalten, dann 1V8

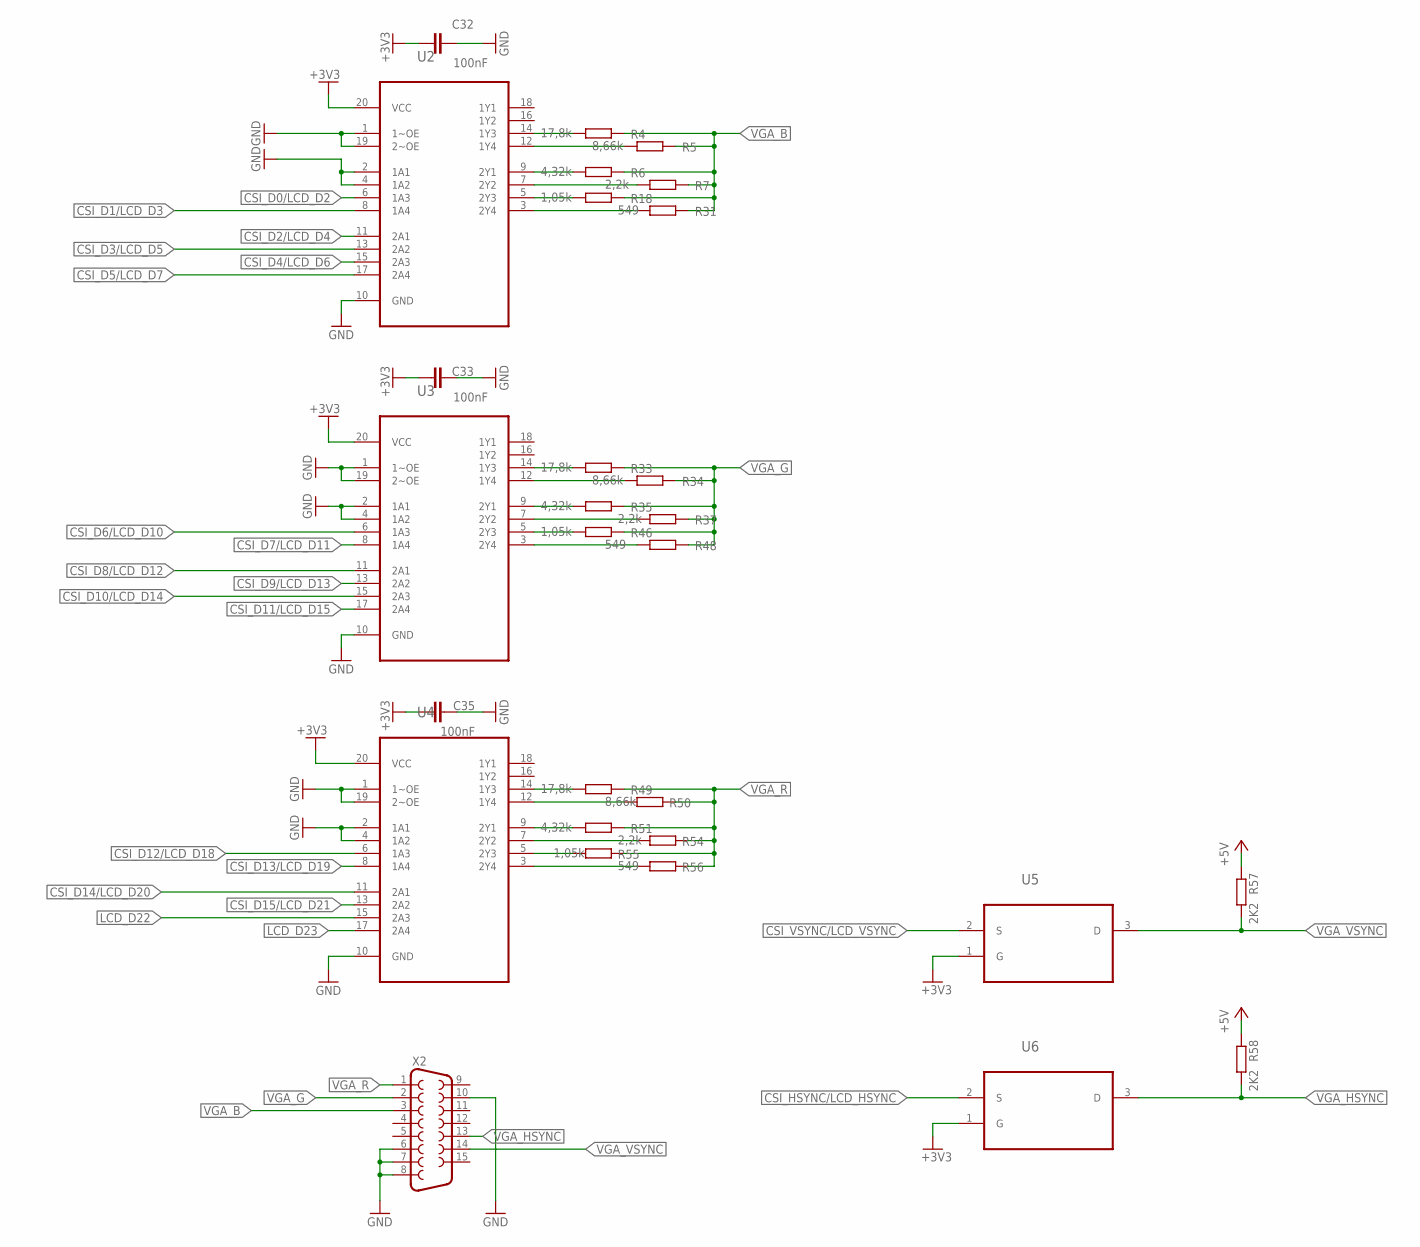
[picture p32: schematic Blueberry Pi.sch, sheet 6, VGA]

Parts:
C32, C33, C35: 100nF; C0603
R4, R33, R49: 17,8k; R0603
R5, R34, R50: 8,66k; R0603
R6, R35, R51: 4,32k; R0603
R7, R37, R54: 2,2k; R0603
R18, R46, R55: 1,05k; R0603
R31, R48, R56: 549; R0603
R57, R58: 2K2; R0603
U2, U3, U4: SN74ALVC244PW; SOP65P640X120-20N
U5, U6: BSS138TA; SOT95P240X110-3N
X2: F15HDH; HDF15H

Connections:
+3V3: C32.2, C33.2, C35.2, U2.20 (VCC), U3.20 (VCC), U4.20 (VCC), U5.1 (G), U6.1 (G); also elsewhere on the board
+5V: R57.1, R58.1; also elsewhere on the board
CSI_D0/LCD_D2: U2.6 (1A3); also elsewhere on the board
CSI_D1/LCD_D3: U2.8 (1A4); also elsewhere on the board
CSI_D2/LCD_D4: U2.11 (2A1); also elsewhere on the board
CSI_D3/LCD_D5: U2.13 (2A2); also elsewhere on the board
CSI_D4/LCD_D6: U2.15 (2A3); also elsewhere on the board
CSI_D5/LCD_D7: U2.17 (2A4); also elsewhere on the board
CSI_D6/LCD_D10: U3.6 (1A3); also elsewhere on the board
CSI_D7/LCD_D11: U3.8 (1A4); also elsewhere on the board
CSI_D8/LCD_D12: U3.11 (2A1); also elsewhere on the board
CSI_D9/LCD_D13: U3.13 (2A2); also elsewhere on the board
CSI_D10/LCD_D14: U3.15 (2A3); also elsewhere on the board
CSI_D11/LCD_D15: U3.17 (2A4); also elsewhere on the board
CSI_D12/LCD_D18: U4.6 (1A3); also elsewhere on the board
CSI_D13/LCD_D19: U4.8 (1A4); also elsewhere on the board
CSI_D14/LCD_D20: U4.11 (2A1); also elsewhere on the board
CSI_D15/LCD_D21: U4.13 (2A2); also elsewhere on the board
CSI_HSYNC/LCD_HSYNC: U6.2 (S); also elsewhere on the board
CSI_VSYNC/LCD_VSYNC: U5.2 (S); also elsewhere on the board
GND: C32.1, C33.1, C35.1, U2.1 (1~OE), U2.2 (1A1), U2.4 (1A2), U2.10 (GND), U2.19 (2~OE), U3.1 (1~OE), U3.2 (1A1), U3.4 (1A2), U3.10 (GND), U3.19 (2~OE), U4.1 (1~OE), U4.2 (1A1), U4.4 (1A2), U4.10 (GND), U4.19 (2~OE), X2.6, X2.7, X2.8, X2.10; also elsewhere on the board
LCD_D22: U4.15 (2A3); also elsewhere on the board
LCD_D23: U4.17 (2A4); also elsewhere on the board
unnamed: R4.2, U2.14 (1Y3)
unnamed: R5.2, U2.12 (1Y4)
unnamed: R6.2, U2.9 (2Y1)
unnamed: R7.2, U2.7 (2Y2)
unnamed: R18.2, U2.5 (2Y3)
unnamed: R31.2, U2.3 (2Y4)
unnamed: R33.2, U3.14 (1Y3)
unnamed: R34.2, U3.12 (1Y4)
unnamed: R35.2, U3.9 (2Y1)
unnamed: R37.2, U3.7 (2Y2)
unnamed: R46.2, U3.5 (2Y3)
unnamed: R48.2, U3.3 (2Y4)
unnamed: R56.2, U4.3 (2Y4)
unnamed: R55.2, U4.5 (2Y3)
unnamed: R54.2, U4.7 (2Y2)
unnamed: R51.2, U4.9 (2Y1)
unnamed: R50.2, U4.12 (1Y4)
unnamed: R49.2, U4.14 (1Y3)
VGA_B: R4.1, R5.1, R6.1, R7.1, R18.1, R31.1, X2.3
VGA_G: R33.1, R34.1, R35.1, R37.1, R46.1, R48.1, X2.2
VGA_HSYNC: R58.2, U6.3 (D), X2.13
VGA_R: R49.1, R50.1, R51.1, R54.1, R55.1, R56.1, X2.1
VGA_VSYNC: R57.2, U5.3 (D), X2.14

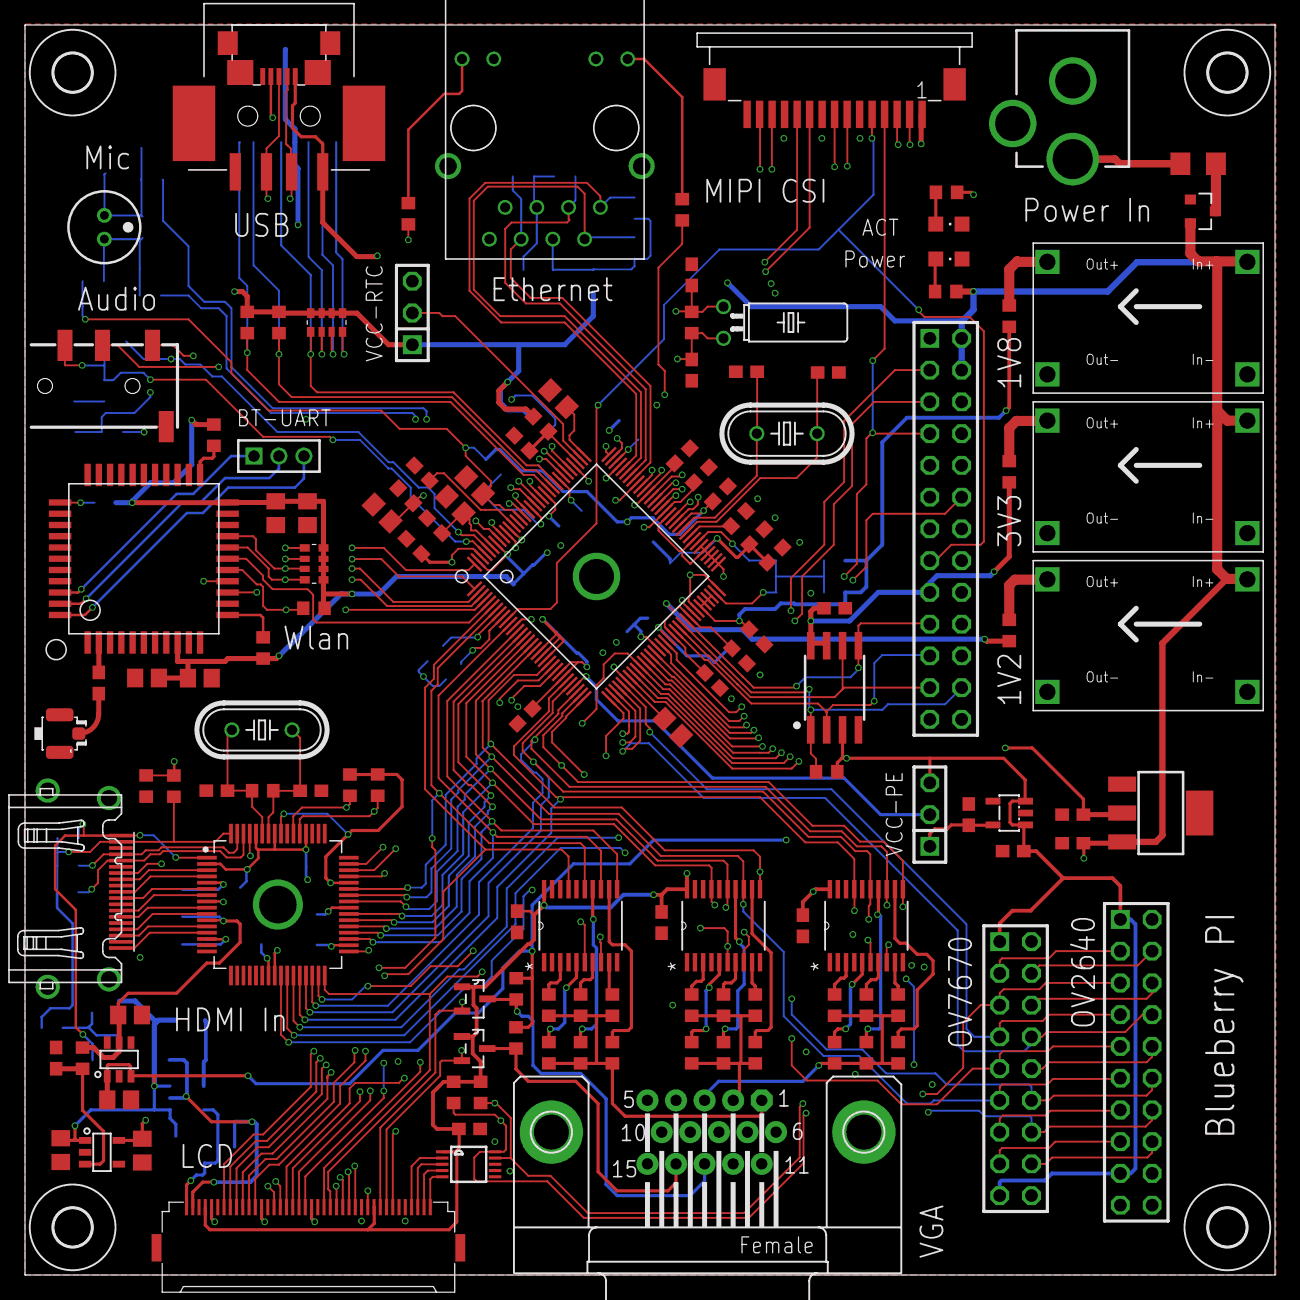
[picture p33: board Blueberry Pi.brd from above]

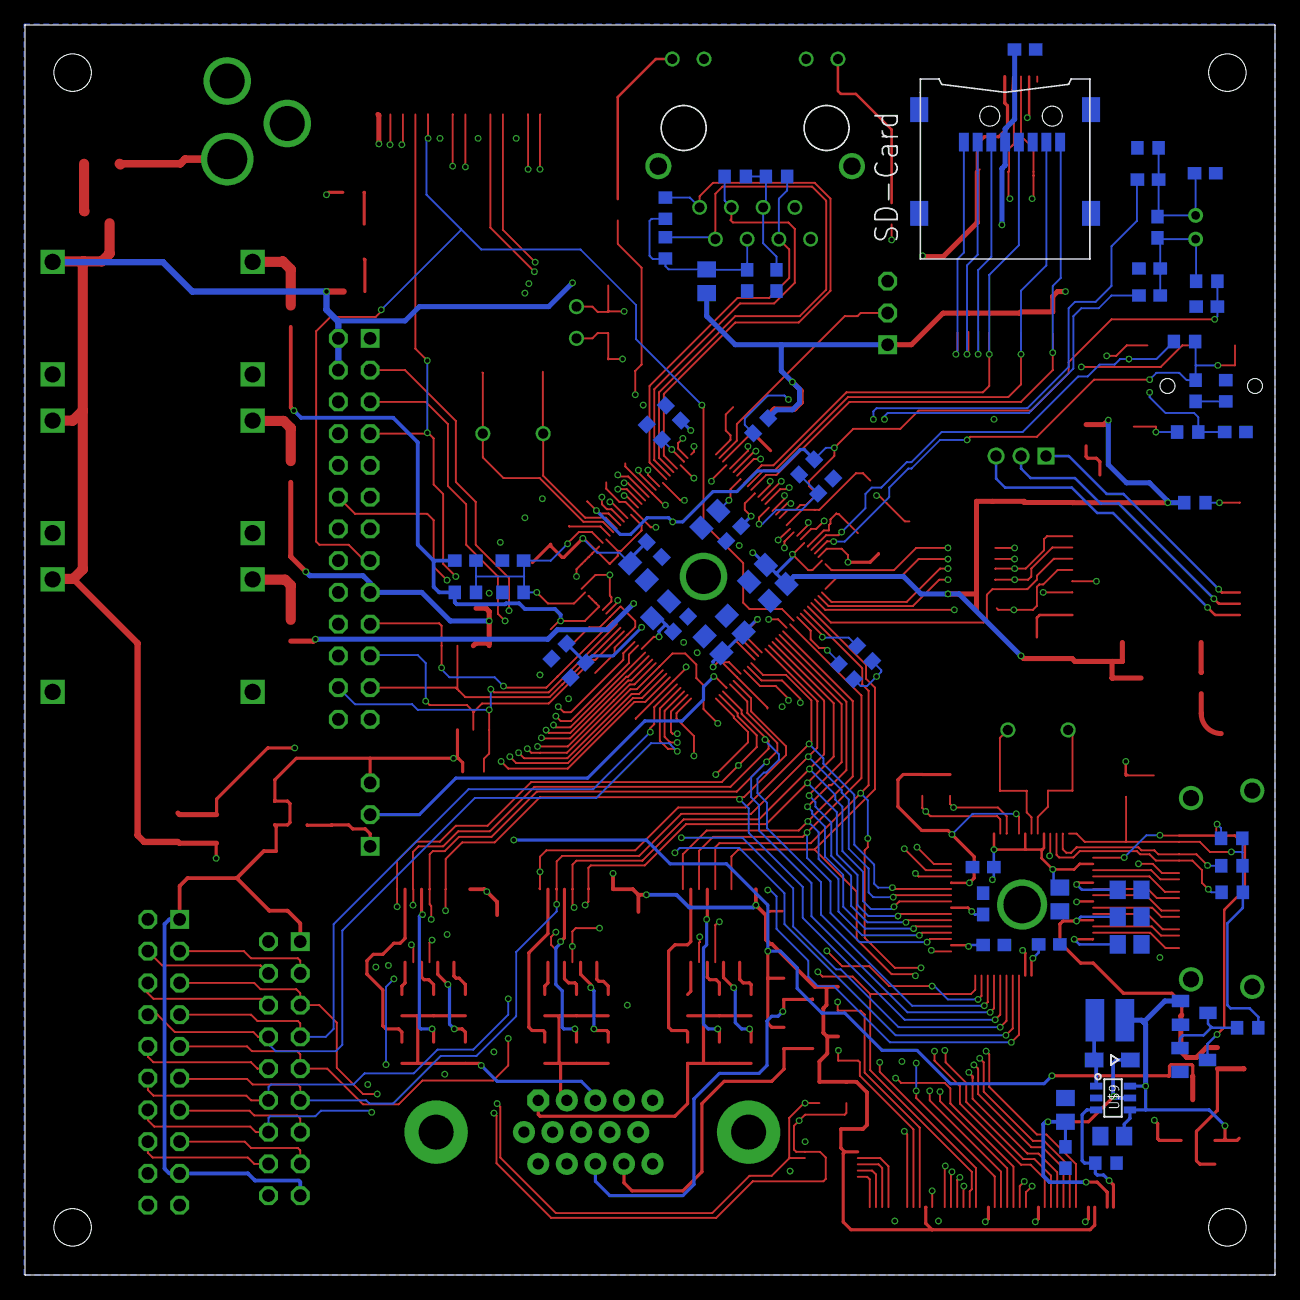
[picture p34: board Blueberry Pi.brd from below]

Board: 4 copper layers, 100.0 x 100.0 mm, 202 parts (67 on the bottom side), 167 nets.

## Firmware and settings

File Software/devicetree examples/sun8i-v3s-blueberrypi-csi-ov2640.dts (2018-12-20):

/dts-v1/;
#include "sun8i-v3s.dtsi"
#include "sunxi-common-regulators.dtsi"
#include <dt-bindings/input/input.h>
/ {
	model = "Blueberry PI";
	compatible = "blueberrypi", "allwinner,sun8i-v3s";

	aliases {
		serial0 = &uart0;
		ethernet0 = &emac;
		
	};

	chosen {
		stdout-path = "serial0:115200n8";
	};

	leds {
	compatible = "gpio-leds";

	act_led {
		label = "act_led:green:usr";
		gpios = <&pio 1 2 GPIO_ACTIVE_HIGH>; /* PB2 */
		linux,default-trigger = "mmc0";
		default-state = "off";
	};
	};
};



&csi1 {
	status = "okay";
    pinctrl-names = "default";
    pinctrl-0 = <&csi1_clk &csi1_8bit>;

port {
	
	
	csi1_ep: endpoint {
	
		remote-endpoint = <&ov2640_0>;
		hsync-active = <0>;
		vsync-active = <0>;
		bus-width = <10>;
	    pclk-sample = <1>;
		
		};
	};
 };

&i2c1 {
    	pinctrl-0 = <&i2c1_pins>;
		pinctrl-names = "default";
		status = "okay";

	
	ov2640: camera@30 {
		compatible = "ovti,ov2640";
		reg = <0x30>;
		pinctrl-names = "default";
		pinctrl-0 = <&csi1_mclk>;
		clocks = <&ccu CLK_CSI1_MCLK>;
		clock-names = "xvclk";
		assigned-clocks = <&ccu CLK_CSI1_MCLK>;
		assigned-clock-rates = <24000000>;
		
		port {
			ov2640_0: endpoint {
				remote-endpoint = <&csi1_ep>;
				bus-width = <10>;
			};
		};
	};
};



&mmc0 {
	pinctrl-0 = <&mmc0_pins>;
	pinctrl-names = "default";
	broken-cd;
	bus-width = <4>;
	vmmc-supply = <&reg_vcc3v3>;
	status = "okay";
};

&mmc1 {
	pinctrl-0 = <&mmc1_pins>;
	pinctrl-names = "default";
	broken-cd;
	bus-width = <4>;
	vmmc-supply = <&reg_vcc3v3>;
	status = "okay";
};

&usb_otg {
	dr_mode = "otg";
	status = "okay";
};

&usbphy {
	pinctrl-0 = <&usb0_id_detect_pin>;
	usb0_id_det-gpio = <&pio 5 6 GPIO_ACTIVE_LOW>;
	status = "okay";
};

&ehci0 {
                         
    status = "okay";
};

&ohci0 {
                         
    status = "okay";
};

&emac {
	allwinner,leds-active-high;
	status = "okay";
};

&uart0 {
	pinctrl-0 = <&uart0_pins>;
	pinctrl-names = "default";
	status = "okay";
};

&i2c0 {
	pinctrl-0 = <&i2c0_pins>;
	pinctrl-names = "default";
	status = "okay";
};

&codec {
	allwinner,audio-routing = "Headphone", "HP", "Headphone", "HPCOM", "Mic", "MIC1";
	status = "okay";
};

&lradc {
	vref-supply = <&reg_vcc3v0>;
	status = "okay";

	button@200 {
		label = "Volume Up";
		linux,code = <KEY_VOLUMEUP>;
		channel = <0>;
		voltage = <200000>;
	};

	button@400 {
		label = "Volume Down";
		linux,code = <KEY_VOLUMEDOWN>;
		channel = <0>;
		voltage = <400000>;
	};

	button@600 {
		label = "Select";
		linux,code = <KEY_SELECT>;
		channel = <0>;
		voltage = <600000>;
	};

	button@800 {
		label = "Start";
		linux,code = <KEY_OK>;
		channel = <0>;
		voltage = <800000>;
	};
};

&pio {
	csi1_8bit: csi1-8bit@0 {
	       pins 	 = "PE6","PE7","PE8","PE9","PE10","PE11","PE12","PE13","PE14","PE15";
	       bias-disable;
	       function = "csi";
    	};

	csi1_clk: csi1-clk@0 {
	        pins = "PE0","PE2","PE3";
	        bias-disable;
	        function = "csi";
    	};
    
    csi1_mclk: csi1-mclk@0 {
	        pins = "PE1";
	        bias-disable;
	        function = "csi";
    	};

	i2c0_pins: i2c0 {
		pins = "PB6", "PB7";
		function = "i2c0";
	};

	i2c1_pins: i2c1 {
		pins = "PE21", "PE22";
		function = "i2c1";
	};
	

	uart0_pins: uart0@0 {
	 	pins = "PB8", "PB9";
		function = "uart0";
	};

	usb0_id_detect_pin: usbid@0 {
	 	pins = "PF6";
		function = "gpio_in";
	};
};

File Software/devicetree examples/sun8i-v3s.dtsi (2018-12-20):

#include <dt-bindings/clock/sun8i-v3s-ccu.h>
#include <dt-bindings/reset/sun8i-v3s-ccu.h>
#include <dt-bindings/interrupt-controller/arm-gic.h>
#include <dt-bindings/pinctrl/sun4i-a10.h>


/ {
	#address-cells = <1>;
	#size-cells = <1>;
	interrupt-parent = <&gic>;


	chosen {
		#address-cells = <1>;
		#size-cells = <1>;
		ranges;
		
       	};
			

	
	cpus {
		#address-cells = <1>;
		#size-cells = <0>;

		cpu@0 {
			compatible = "arm,cortex-a7";
			device_type = "cpu";
			reg = <0>;
			clocks = <&ccu CLK_CPU>;
		};
	};
	

	de0: display-engine {
		compatible = "allwinner,sun8i-v3s-display-engine";
		allwinner,pipelines = <&mixer0>;
		status = "disabled";
	};

	timer {
		compatible = "arm,armv7-timer";
		interrupts = <GIC_PPI 13 (GIC_CPU_MASK_SIMPLE(4) | IRQ_TYPE_LEVEL_LOW)>,
			     <GIC_PPI 14 (GIC_CPU_MASK_SIMPLE(4) | IRQ_TYPE_LEVEL_LOW)>,
			     <GIC_PPI 11 (GIC_CPU_MASK_SIMPLE(4) | IRQ_TYPE_LEVEL_LOW)>,
			     <GIC_PPI 10 (GIC_CPU_MASK_SIMPLE(4) | IRQ_TYPE_LEVEL_LOW)>;
	};


	

	clocks {
		#address-cells = <1>;
		#size-cells = <1>;
		ranges;

		osc24M: osc24M_clk {
			#clock-cells = <0>;
			compatible = "fixed-clock";
			clock-frequency = <24000000>;
			clock-output-names = "osc24M";
		};

		osc32k: osc32k_clk {
			#clock-cells = <0>;
			compatible = "fixed-clock";
			clock-frequency = <32768>;
			clock-output-names = "osc32k";
		};


		
	};

	soc {
		compatible = "simple-bus";
		#address-cells = <1>;
		#size-cells = <1>;
		ranges;

	syscon: syscon@1c00000 {
			compatible = "allwinner,sun8i-v3s-system-controller",
				"syscon";
			reg = <0x01c00000 0x1000>;
	};

	
	display_clocks: clock@1000000 {
			compatible = "allwinner,sun8i-v3s-de2-clk";
			reg = <0x01000000 0x100000>;
			clocks = <&ccu CLK_DE>,
				 <&ccu CLK_BUS_DE>;
			clock-names = "mod",
				      "bus";
			resets = <&ccu RST_BUS_DE>;
			#clock-cells = <1>;
			#reset-cells = <1>;
			status = "disabled";
		};

		mixer0: mixer@1100000 {
			compatible = "allwinner,sun8i-v3s-de2-mixer";
			reg = <0x01100000 0x100000>;
			clocks = <&display_clocks 0>,
				 <&display_clocks 6>;
			clock-names = "bus",
				      "mod";
			resets = <&display_clocks 0>;
			assigned-clocks = <&display_clocks 6>;
			assigned-clock-rates = <150000000>;
			status = "disabled";

			ports {
				#address-cells = <1>;
				#size-cells = <0>;

				mixer0_out: port@1 {
					#address-cells = <1>;
					#size-cells = <0>;
					reg = <1>;

					mixer0_out_tcon0: endpoint@0 {
						reg = <0>;
						remote-endpoint = <&tcon0_in_mixer0>;
					};
				};
			};
		};

		tcon0: lcd-controller@1c0c000 {
			compatible = "allwinner,sun8i-v3s-tcon";
			reg = <0x01c0c000 0x1000>;
			interrupts = <GIC_SPI 86 IRQ_TYPE_LEVEL_HIGH>;
			clocks = <&ccu CLK_BUS_TCON0>,
				 <&ccu CLK_TCON0>;
			clock-names = "ahb",
				      "tcon-ch0";
			clock-output-names = "tcon-pixel-clock";
			resets = <&ccu RST_BUS_TCON0>;
			reset-names = "lcd";
			status = "disabled";

			ports {
				#address-cells = <1>;
				#size-cells = <0>;

				tcon0_in: port@0 {
					#address-cells = <1>;
					#size-cells = <0>;
					reg = <0>;

					tcon0_in_mixer0: endpoint@0 {
						reg = <0>;
						remote-endpoint = <&mixer0_out_tcon0>;
					};
				};

				tcon0_out: port@1 {
					#address-cells = <1>;
					#size-cells = <0>;
					reg = <1>;
				};
			};
		};
	

	csi1: csi@1cb4000 {
			compatible = "allwinner,sun8i-v3s-csi";
			reg = <0x01cb4000 0x1000>;
			interrupts = <GIC_SPI 84 IRQ_TYPE_LEVEL_HIGH>;
			clocks = <&ccu CLK_BUS_CSI>,
					<&ccu CLK_CSI1_SCLK>,
					<&ccu CLK_DRAM_CSI>;
			clock-names = "bus", "mod", "ram";
			resets = <&ccu RST_BUS_CSI>;
			status = "disabled";
		};
		
	dma: dma-controller@01c02000 {
			compatible = "allwinner,sun8i-v3s-dma";
			reg = <0x01c02000 0x1000>;
			interrupts = <GIC_SPI 50 IRQ_TYPE_LEVEL_HIGH>;
			clocks = <&ccu CLK_BUS_DMA>;
			resets = <&ccu RST_BUS_DMA>;
			#dma-cells = <1>;
		};
	
	mmc0: mmc@1c0f000 {
			compatible = "allwinner,sun7i-a20-mmc";
			reg = <0x01c0f000 0x1000>;
			clocks = <&ccu CLK_BUS_MMC0>,
		 	<&ccu CLK_MMC0>,
		 	<&ccu CLK_MMC0_OUTPUT>,
		 	<&ccu CLK_MMC0_SAMPLE>;
		 	clock-names = "ahb","mmc","output","sample";
		 	resets = <&ccu RST_BUS_MMC0>;
		 	reset-names = "ahb";
		 	interrupts = <GIC_SPI 60 IRQ_TYPE_LEVEL_HIGH>;
		 	status = "disabled";
		 	#address-cells = <1>;
		 	#size-cells = <0>;
		};
	
	
	mmc1: mmc@1c10000 {
			compatible = "allwinner,sun7i-a20-mmc";
			reg = <0x01c10000 0x1000>;
			clocks = <&ccu CLK_BUS_MMC1>,
				 <&ccu CLK_MMC1>,
				 <&ccu CLK_MMC1_OUTPUT>,
				 <&ccu CLK_MMC1_SAMPLE>;
			clock-names = "ahb",
				      "mmc",
				      "output",
				      "sample";
			resets = <&ccu RST_BUS_MMC1>;
			reset-names = "ahb";
			interrupts = <GIC_SPI 61 IRQ_TYPE_LEVEL_HIGH>;
			pinctrl-names = "default";
			pinctrl-0 = <&mmc1_pins>;
			status = "disabled";
			#address-cells = <1>;
			#size-cells = <0>;
		};	
	
	
	mmc2: mmc@1c11000 {
			compatible = "allwinner,sun7i-a20-mmc";
			reg = <0x01c11000 0x1000>;
			clocks = <&ccu CLK_BUS_MMC2>,
				 <&ccu CLK_MMC2>,
				 <&ccu CLK_MMC2_OUTPUT>,
				 <&ccu CLK_MMC2_SAMPLE>;
			clock-names = "ahb",
				      "mmc",
				      "output",
				      "sample";
			resets = <&ccu RST_BUS_MMC2>;
			reset-names = "ahb";
			interrupts = <GIC_SPI 62 IRQ_TYPE_LEVEL_HIGH>;
			status = "disabled";
			#address-cells = <1>;
			#size-cells = <0>;
		};
	
	usb_otg: usb@1c19000 {
			compatible = "allwinner,sun8i-h3-musb";
			reg = <0x01c19000 0x0400>;
			clocks = <&ccu CLK_BUS_OTG>;
			resets = <&ccu RST_BUS_OTG>;
			interrupts = <GIC_SPI 71 IRQ_TYPE_LEVEL_HIGH>;
			interrupt-names = "mc";
			phys = <&usbphy 0>;
			phy-names = "usb";
			extcon = <&usbphy 0>;
			status = "disabled";
		};

	usbphy: phy@1c19400 {
			compatible = "allwinner,sun8i-v3s-usb-phy";
			reg = <0x01c19400 0x2c>,
			      <0x01c1a800 0x4>;
			reg-names = "phy_ctrl",
				    "pmu0";
			clocks = <&ccu CLK_USB_PHY0>;
			clock-names = "usb0_phy";
			resets = <&ccu RST_USB_PHY0>;
			reset-names = "usb0_reset";
			status = "disabled";
			#phy-cells = <1>;
		};

	ehci0: usb@01c1a000 {
		compatible = "allwinner,sun8i-v3s-ehci", "generic-ehci";
		reg = <0x01c1a000 0x100>;
		interrupts = <GIC_SPI 72 IRQ_TYPE_LEVEL_HIGH>;
		clocks = <&ccu CLK_BUS_EHCI0>, <&ccu CLK_BUS_OHCI0>;
		resets = <&ccu RST_BUS_EHCI0>, <&ccu RST_BUS_OHCI0>;
		phys = <&usbphy 0>;
   		phy-names = "usb";
		status = "disable";
	};

	ohci0: usb@01c1a400 {
		compatible = "allwinner,sun8i-v3s-ohci", "generic-ohci";
		reg = <0x01c1a400 0x100>;
		interrupts = <GIC_SPI 73 IRQ_TYPE_LEVEL_HIGH>;
		clocks = <&ccu CLK_BUS_EHCI0>, <&ccu CLK_BUS_OHCI0>, <&ccu CLK_USB_OHCI0>;
		resets = <&ccu RST_BUS_EHCI0>, <&ccu RST_BUS_OHCI0>;
		phys = <&usbphy 0>;
   		phy-names = "usb";
		status = "disable";
	}; 

	ccu: clock@1c20000 {
			compatible = "allwinner,sun8i-v3s-ccu";
			reg = <0x01c20000 0x400>;
			clocks = <&osc24M>, <&osc32k>;
			clock-names = "hosc", "losc";
			#clock-cells = <1>;
			#reset-cells = <1>;
		};
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

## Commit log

2017-07-21 Added Hardware folder
    [Blueberry Pi.brd, Blueberry Pi.sch, LCD_to_VGA_Modul.brd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]
2018-07-23 new devicetree files
2018-08-14 updated schematics
    [Blueberry Pi.brd, Blueberry Pi.sch]
2018-12-20 new version
    [ADV7611-Allwinner-V3s-mapping.xlsx, BOM.xlsx, Blueberry Pi BOM.csv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]

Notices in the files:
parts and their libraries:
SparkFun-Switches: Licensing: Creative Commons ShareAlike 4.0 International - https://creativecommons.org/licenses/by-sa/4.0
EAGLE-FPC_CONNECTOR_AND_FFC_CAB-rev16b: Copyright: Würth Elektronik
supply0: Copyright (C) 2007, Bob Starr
